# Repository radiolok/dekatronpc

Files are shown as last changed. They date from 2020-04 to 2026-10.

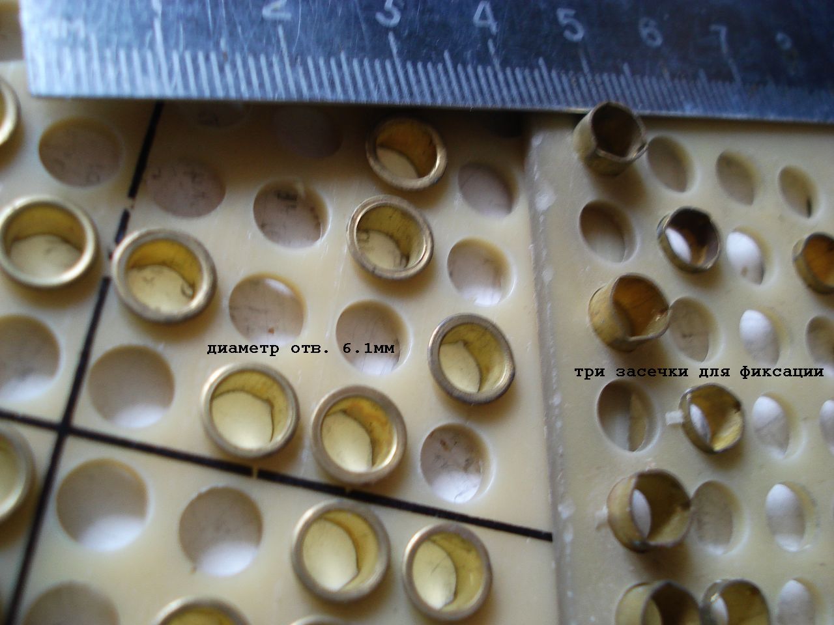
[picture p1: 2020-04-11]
img/magnetic_punch_card/DSC00020.JPG

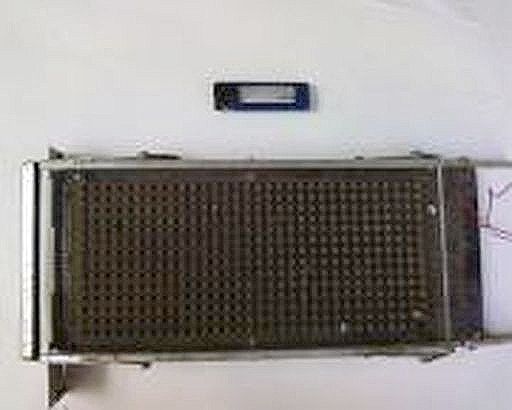
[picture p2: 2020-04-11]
img/magnetic_punch_card/njojryg1g.jpg

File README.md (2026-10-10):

# DekatronPC

Ламповый компьютер на декатронах А110 с системой команд Brainfuck. Счётчики машины — реверсивные декатроны: они умеют ровно то, что нужно Brainfuck, — прибавить и отнять единицу. Логика вокруг них — вакуумные лампы 6Н16Б и 6Ж2Б, без кремниевых полупроводников в вычислительном тракте.

*A vacuum-tube Brainfuck computer built around A110 dekatron counting tubes. RTL in SystemVerilog, an FPGA emulator for blocks not yet built, requirements and microarchitecture docs in Russian.*

Верхний уровень DekatronPC: пульт, терминал, автомат управления, линия выборки с памятью программ, линия данных с памятью данных, реле времени сброса

## Машина

| Параметр | Значение |
|---|---|
| Архитектура | гарвардская: отдельные память программ и память данных |
| Система команд | Brainfuck и отладочный набор, по 16 опкодов, 4 бита на команду |
| Счётчик команд IP | 5 декатронов, 0…99999 |
| Счётчик вложенности Loop | 2 декатрона, 0…99 (в RTL пока 3) |
| Указатель данных AP | 5 декатронов, предел 29999 (99999 — открытый вопрос OPEN-001) |
| Значение ячейки Data | 3 декатрона, 0…255 |
| Всего декатронов | 15 |
| Память программ | 100 000 × 4 бит, верхний банк 99900…99999 — ПЗУ загрузчика |
| Память данных | 30 000 ячеек × 10 бит (BCD: сотни, десятки, единицы) |
| Тактовая частота | 1 МГц (цель; калибровка таймингов декатрона — OPEN-013/014) |
| Логика | ≈ 2600 ламп по синтезу RTL в библиотеку ламповых ячеек, без памяти |

Адреса и данные хранятся в BCD прямо так, как их показывают декатроны: память адресуется тетрадами без перевода в двоичный код. Цикл просматривается самой линией выборки: при `[` с нулевой ячейкой или `]` с ненулевой IP проматывается до парной скобки, счётчик Loop считает вложенность.

Конфигурация счётчиков проверена на наборе из ста реальных программ с GitHub — [Brainfuck-100](https://github.com/radiolok/bfutils/tree/claude_nextGen/programs/bf100) в сабмодуле `bfutils`: в 5 + 2 + 5 + 3 декатрона помещаются 97 программ из 100.

## Система команд

Команда декодируется по паре {режим, опкод}. Неопределённые и зарезервированные опкоды исполняются как NOP.

| Опкод | Отладочный набор (режим 0) | Brainfuck (режим 1) |
|---|---|---|
| 0x0 | NOP | NOP |
| 0x1 | HALT | HALT |
| 0x2 | BELL | `+` INC |
| 0x3 | — (NOP) | `-` DEC |
| 0x4 | EOT — конец загрузки | `>` AINC |
| 0x5 | SOT — начало загрузки | `<` ADEC |
| 0x6 | `{` — пропуск, если AP = 0 | `[` LBEG |
| 0x7 | `}` — повтор, если AP ≠ 0 | `]` LEND |
| 0x8 | CLRL — Loop ← 0 | `.` COUT |
| 0x9 | CLRI — IP ← 0 | `,` CIN |
| 0xA | CLRD — ячейка ← 0 | `[-]` CLRD |
| 0xB | CLRA — AP ← 0 | CLRML — выгрузить и снять MemLock |
| 0xC | HRST — аппаратный сброс | LOAD |
| 0xD | SRST — программный сброс | STORE |
| 0xE | ISA0 — в отладочный набор | ISA0 |
| 0xF | ISA1 — в Brainfuck | ISA1 |

Аппаратный сброс ставит IP = 99900 и запускает загрузчик из ПЗУ; программный — IP = 0. Полная семантика, MemLock и ленивое чтение памяти данных — в [TRS.md](TRS.md), разделы 6–10.

## Документы

| Документ | Что в нём |
|---|---|
| [TRS.md](TRS.md) | требования: архитектура, ISA, память, декатроны, RTL, верификация, стенд, ламповые модули, открытые вопросы, чек-лист и план работ. Каждое требование имеет ID (`REQ-*`, `OPEN-*`) и статус |
| [SCHEMES.md](SCHEMES.md) | структурные схемы ядра в семи листах: декатрон, модуль, счётчик, IpLine, ApLine, MachineCtrl, верхний уровень |
| [doc/dpcrun_golden_model.md](doc/dpcrun_golden_model.md) | C++ golden model: семантика, расхождения RTL и TRS, найденные дефекты |
| [tb/README.md](tb/README.md) | testbench на cocotb и pyuvm |
| [rtl/DekatronPC/Dekatron/DekatronCounter.md](rtl/DekatronPC/Dekatron/DekatronCounter.md) | устройство декатронного счётчика |
| [rtl/DekatronPC/emulator_inspection.md](rtl/DekatronPC/emulator_inspection.md) | разбор слоя эмулятора на ПЛИС |
| [history.md](history.md) | журнал сессий работы над проектом |

## Репозиторий

| Путь | Содержимое |
|---|---|
| `rtl/DekatronPC/` | ядро: `DekatronPC.sv`, `MachineCtrl.sv`, `IpLine.sv`, `ApLine.sv`, `IpMemory.sv`, `RAM.sv`, верх для DE0-Nano `De0Nano.sv` |
| `rtl/DekatronPC/Dekatron/` | декатрон: модель лампы `DekatronTubeV2`, модуль, счётчик, генератор фаз, формирователь импульсов |
| `rtl/parameters.sv` | разрядность счётчиков |
| `rtl/Emulator/` | слой эмулятора на ПЛИС: клавиатура, индикатор МС6205, ИН-12, загрузчик прошивки |
| `rtl/Logic/`, `rtl/Functions/` | примитивы и кодеры |
| `rtl/vtube/` | библиотека ламповых ячеек `vtube_cells.lib` для синтеза |
| `rtl/programs/` | тестовые программы `*.bfk` и загрузчик |
| `rtl/run/` | скрипты моделирования, синтеза и подсчёта ламп |
| `rtl/quartus/` | проект Quartus |
| `tb/` | testbench на cocotb и pyuvm |
| `bfutils/` | сабмодуль [radiolok/bfutils](https://github.com/radiolok/bfutils): компилятор, эмулятор, golden model `dpcrun`, набор Brainfuck-100 |
| `sch/` | схемы KiCad: эмулятор, экспериментальная декатронная ячейка, библиотеки ламп |
| `doc/` | отчёты и справочная литература |
| `img/schemes/` | картинки для SCHEMES.md |
| `web/` | симулятор в браузере: пульт, декатроны, загрузка по SOT/EOT, Brainfuck-100 ([web/README.md](web/README.md)) |
| `tools/schemes/` | генератор SCHEMES.md и картинок схем: `python3 tools/schemes/build.py` |

Блоки `Dekatron.sv`, `DekatronPulseAllow`, `DekatronCarrySignal`, `InsnDecoder`, `BcdToBinEnc` в тракте памяти и папка `rtl/[DEPRECATED]` — старый тракт, подлежит удалению (TRS, раздел 19.4).

## Сборка и проверка

```bash
git clone --recursive https://github.com/radiolok/dekatronpc.git
cd dekatronpc
git submodule update --init       # если клонировали без --recursive

docker build -t dekatron-pc .     # Verilator, Icarus, Yosys, cocotb — то же окружение, что в CI
```

| Задача | Команда |
|---|---|
| один тест на Icarus | `cd tb && make test_compare SIM=icarus` |
| регрессия cocotb | `cd tb && make regression` |
| моделирование RTL | `cd rtl/run && ./run_tests.sh -t` |
| синтез в лампы (Yosys) | `cd rtl/run && ./run_tests.sh -s` |

Полная сборка DekatronPC и эмулятора в Verilator и синтез — тяжёлые задачи; на слабой машине начинайте с одиночных целей на Icarus. CI: `.github/workflows/docker-image.yml`.

## Состояние

- Готово в RTL: модель декатрона, декатронный счётчик с Valid/Ready, линии IpLine и ApLine с ленивым чтением, MachineCtrl, банковая память, синтез в ламповые ячейки.
- Golden model `bfutils/dpcrun` поддерживает полный ISA; пошаговое сравнение с RTL ждёт исправления вывода `.` (OPEN-017).
- Решения, ещё не внесённые в RTL: Loop на 2 декатрона, сброс `lock` в ApLine при смене адреса, вывод через `AP_COUT`.
- Следующие этапы: прогон всех новых блоков в Verilator и Icarus, испытательный стенд, экспериментальная декатронная ячейка и калибровка таймингов, первые ламповые модули.

Полный чек-лист — в TRS.md, разделы 19–22.

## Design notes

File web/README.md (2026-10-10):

# DekatronPC web simulator

A static web page that runs DekatronPC in the browser: 15 dekatrons (IP 5, Loop 2, AP 5, Data 3), the operator panel of `DekatronPC.sv`, program and data memory strips, the Consul printer with keyboard input, the repo test programs and the Brainfuck-100 set.

| File | What it is |
|---|---|
| `index.html` | the page: console, panel, program sheet, printer, RU/EN text |
| `dpc.js` | the machine: JavaScript port of the golden model `bfutils/dpcrun` |
| `build_bf100.py` | copies `rtl/programs/*.bfk` and `bfutils/programs/bf100` (with licenses) to `programs/` and writes `programs/index.json` |
| `test/test_dpc.js` | model tests: trace compare with `dpcrun`, assembler, SOT/EOT load |
| `programs/` | generated, not committed |

## Run locally

```bash
git submodule update --init bfutils
python3 web/build_bf100.py
cd web && python3 -m http.server 8000      # open http://localhost:8000
```

The page fetches `programs/`, so it needs an HTTP server: opening `index.html` as a file shows only the built-in Hello World.

## Deploy

- **GitHub Pages:** `.github/workflows/pages.yml` builds and publishes on every push to `master`, `claude_nextGen` or `web_simulator` that touches `web/`, `bfutils` or `rtl/programs/`, and on manual run. Repository settings: Pages, Source: GitHub Actions; Environments, `github-pages`, Deployment branches: allow the branch you deploy from.
- **Own server:** run `build_bf100.py`, then copy `index.html`, `dpc.js` and `programs/` to any static directory. All paths are relative.

## Tests

```bash
g++ -O2 -DEXEC -o /tmp/dpcrun bfutils/dpcrun/dpcrun.cpp
node web/test/test_dpc.js /tmp/dpcrun     # without the argument the trace compare is skipped
```

CI: `.github/workflows/web.yml`. Design notes and the halt finding: `doc/web_simulator.md`.

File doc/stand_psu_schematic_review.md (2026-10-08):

# Test stand power supply: schematic review

Date: 2026-10-07. Scope: KiCad project `sch/stand/stand.kicad_pro` (was `sch/stand/stand/` at the first review)
(root sheet `stand.kicad_sch` plus three instances of `psu.kicad_sch`:
PSU_200v, PSU_120v, PSU_80v). The side files `stand_v2.kicad_sch` and
`untitled.kicad_sch` are not part of the project hierarchy and were not reviewed.
Requirements: TRS §15 (REQ-STAND-*, REQ-PWR-*, REQ-SAFE-*).

Method: `kicad-cli` 10.0.6 (ERC, netlist export, PDF plot, DRC with schematic
parity), then a manual net-by-net reading of the exported netlist against the
datasheets (TL494, TL431, PC817, LM317, LM337). No simulation was run. The AC
input voltages of the converters are not stated in the schematic, so the
numbers below that depend on them are given as formulas plus an example.

## 1. What the schematic contains

| Block | Parts | Function |
|---|---|---|
| Root, top | J10, D34–D37, C40, U10 LM317, R57/R58/R59, J14 (6.8k pot) | Positive linear rail, about +5.1…+29.8 V |
| Root, bottom | J11, D39–D41/D44, C42, U11 LM337, R62/R60/R61, J15 (6.8k pot) | Negative linear rail, about −5.1…−29.8 V |
| psu.kicad_sch ×3 | Bridge D1–D4 + C1 330 µF/315 V; TL494 push-pull, 2× IRFBE30S, EL33 transformer; bridge HER108 + C14; TL431 + PC817 feedback; Q1 + 1 Ω current limit; 12 V aux via R1, 18 V zener, 7812 | Isolated adjustable HV outputs, nominally 200 / 120 / 80 V |

The ±regulators, protection diodes, ADJ bypass capacitors and their discharge
diodes, bridge orientations and capacitor polarities are all correct (checked
pin by pin, including the LM317 1-ADJ/2-OUT/3-IN and LM337 1-ADJ/2-IN/3-OUT
TO-220 pinouts, TL431LP TO-92 1-REF/2-A/3-K and 2N3904 EBC footprint).

## 2. ERC result

172 violations, of which 163 are only "library not in the current configuration"
(the global symbol and footprint tables are not set up on this machine; not a
design fault). The remaining 9:

- 8 × `power_pin_not_driven` (U10/U11 IN, U3/U4/U7 IN, U1/U4/U7 GND). The rails
  come from rectifiers, not power symbols. Cosmetic: add `PWR_FLAG` symbols.
- 1 × `unconnected_wire_endpoint`: a 3.8 mm stub at (234.95, 81.28)–(234.95, 85.09)
  in `psu.kicad_sch`, next to R9/OC1. The R9→OC1 connection itself is fine;
  delete the stub.

So ERC finds no wiring errors. The real problems are in circuit design and are
listed below.

## 3. Findings, by severity

### Critical: the converter cannot work as drawn

**C1. The voltage loop has the wrong sign (positive feedback).**
The two TL494 error amplifiers are disabled (1IN+/2IN+ at GND, 1IN−/2IN− at
REF), so FB (pin 3) is set only by R13 (4.7k, FB→REF 5 V) and the PC817
transistor (collector OC1.4→FB, emitter OC1.3→GND). In the TL494, higher FB
means a shorter pulse (≈0.5 V gives maximum duty, ≈3.5 V gives zero).
- Output above setpoint → TL431 conducts → LED on → transistor pulls FB low →
  **maximum duty** → output rises further.
- Output below setpoint (including start-up) → TL431 off → LED off → FB pulled up
  to about 5 V → zero duty.

So the loop either does not start, or (with FB partly loaded by the error-amplifier
sink current) starts, then latches at maximum duty with no regulation. The output
then rises to Vbus·Ns/Np_half (≈1.12·Vbus), limited only by the transformer.
Fix: swap the roles: transistor collector to REF (pin 14), emitter to FB,
R13 from FB to GND (the usual TL494 + opto arrangement).

**C2. The current limit is wired for the wrong loop sign, and becomes wrong once
C1 is fixed.** Q1 (base at J2.1, emitter at the return, sensing R24 = 1 Ω)
pulls TL431 REF low on overcurrent. With today's inverted opto this shuts the
converter down, which is the right effect for the wrong reason. After the C1 fix,
pulling REF low turns the LED off, which gives **maximum** duty in overcurrent.
Fix: connect the Q1 collector to the TL431 cathode (U2-K), in parallel with the
TL431, so that overcurrent drives the LED on. Also add a base resistor (≈100–470 Ω).
The trip point is about 0.6–0.7 A, far above REQ-PWR-004's 0.1 A. For a tube
stand, R24 ≈ 6.8 Ω (≈0.1 A) is probably what is wanted. **Question to the owner.**

**C3. The TL431 cathode sees the full output voltage.** The LED and TL431 are fed
straight from +Vout through R9 (18k). The TL431 is rated V_KA ≤ 37 V. When it is
off (start-up, overcurrent, transients) its cathode floats to almost Vout
(80–200 V). When it regulates, V_KA = Vout − V_LED − I_LED·R9. Only about 1 mA
of LED current is needed to pull FB through R13, so V_KA would sit near Vout.
This is an overvoltage on the TL431 in every instance. Fix: supply the LED +
TL431 from a low-voltage rail derived from Vout (for example an
R + 12–15 V zener shunt, or a small transistor follower), with R9 recalculated
for 1–5 mA. The same rail can then power Q1's collector path.

**C4. The 12 V auxiliary supply cannot deliver the gate-drive current.** The TL494
VCC comes from the HV bus through R1, an 18 V zener (D5, DO-35 ≈ 0.5 W) and a
7812. The load on it is dominated by the gate pull-downs R20/R21 = 68 Ω on E1/E2:
when an output is on, (12 − ~1.5) V / 68 Ω ≈ 154 mA. With about 45 % duty per
output, that averages ≈ 140 mA, plus about 10 mA for the TL494: ≈ 150 mA.
R1 then dissipates (Vbus − 18 V) × 0.15 A. At Vbus = 200 V that is about 27 W,
in a DIN0918 (≈2 W) footprint. R1's value is also unspecified (value "R" in all
three instances). As drawn, the rail will collapse, and the MOSFETs will run in
linear mode at low gate voltage. Fix: power the 12 V from a separate
low-voltage winding (the stand already has AC inputs for the ±rails), and raise
the pull-downs to about 1 kΩ with a PNP turn-off transistor (or a diode +
pull-down) per gate, so gate drive costs milliamps, not 150 mA.

**C5. The 4.7 nF snubbers burn tens of watts.** C3/C13 (4.7 nF/630 V) +
R22/R23 (1k, DIN0414 ≈ 1 W) + D7/D6 sit from each drain to GND. In a
centre-tapped push-pull each drain swings 0 → 2·Vbus. A RC/RCD snubber
dissipates about C·V²·f: at Vbus = 200 V, 4.7 nF · (400 V)² · 50 kHz ≈ 38 W
per transistor (bounded a little by R·C = 4.7 µs against a 10 µs half-period).
In addition, the diode is reversed relative to a classic RCD turn-off snubber:
anode is at GND, so it does not speed up charging on turn-off. It does let the
capacitor dump CV² straight into the MOSFET at turn-on, with no resistance.
Fix: a 100–470 pF RC snubber sized against the measured ringing, or an RCD
clamp from drain to +Vbus; in any case, recalculate R power.
Also: the capacitor voltage rating of 630 V is below 2·Vbus + spike as soon
as Vbus > ~280 V.

### Major: values and requirements

**M1. Per-instance values exist only as text notes.** The notes on the PSU sheet
give R7 = 91k / 51k / 24k, R9 = 18k / 11k / 5.6k and transformer turns per
version, but the components carry 91k and 18k in all three instances, and the
BOM/netlist lists them 3×. Use separate sheet files (or KiCad variants) so the
BOM is correct.

**M2. The output range does not reach the nominal voltage in any version.**
Vout = 2.5 V · (1 + R7 / (R8 + R_pot)), with R8 = 1.5k and R_pot = 0…6.8k
(J4 "Voltage", with pins 1–2 joined: a rheostat in the lower leg).

| Version | R7 (note) | R_pot = 0 (max) | R_pot = 6.8k (min) | Needed R8 for nominal |
|---|---|---|---|---|
| 200v | 91k | 154 V | 30 V | ≤ 1.15k |
| 120v | 51k | 87.5 V | 17.9 V | ≤ 1.08k |
| 80v | 24k | 42.5 V | 9.7 V | ≤ 0.78k |

REQ-PWR-004 (50–200 V) is therefore not met. Fix: R8 ≈ 1.0k with a smaller pot,
or move the pot into the upper leg. With a pot in the lower leg, a broken wiper
or unplugged J4 sends REF high: after the C1 fix this shuts the converter down
(safe), but with today's wiring it gives maximum output.

**M3. Linear rail range: a disconnected pot gives the full input voltage.**
On the LM317 (and the LM337 mirror) the pot J14 is in parallel with R58 = 12k.
The range is 1.25·(1 + (R58‖R_pot + 680)/220) ≈ 5.1…29.8 V. If J14 is
disconnected, the setpoint becomes 73 V, so the output goes to Vin − dropout.
If this rail heats tubes (6.3 V), that is an overvoltage on every heater.
Prefer a topology where an open pot gives the minimum voltage. Note also:
LM317/337 are ≤ 1.5 A with 1 A 1N4007 bridges, so neither rail meets
REQ-PWR-001 (6.3 V, ≥ 6 A). The LM337 range (≥ −30 V, 40 V in-out limit) does
not cover REQ-PWR-006 (−20…−70 V). **Question to the owner:** which rails
feed the heaters and the bias, and are REQ-PWR-001/005/006 supposed to be on
another board?

**M4. Bus capacitor rating vs input.** C1/C4/C28 are 330 µF/**315 V**. If the
200v converter is fed from 220–230 V mains directly, the bus is 311–325 V
nominal and about 357 V at +10 % mains, above the rating. The turns notes
(Ns/Np_half ≈ 1.12 for all three versions, Np = 50/30/20) suggest each version
gets a different, lower AC input, but that is not written anywhere.
**Question to the owner:** what AC voltage goes to J1/J3/J7, and is it from an
isolating transformer?

**M5. Shared heatsink.** On the PCB, `radiator1` sits between U10 (LM317, tab =
OUT) and U11 (LM337, tab = IN). On one bare heatsink these tabs short +Vout to
the negative input. REQ-SAFE-005 requires insulated flanges; nothing in the
schematic or PCB records the insulators. Add a note or BOM line (mica/silpad +
bushing) for both, and for the 7812s if they share it.

### Minor

- No fuse, inrush limiter (NTC) or EMI filter on any input. With 330 µF on a
  rectified high-voltage bus, the inrush current is large.
- No HV presence indicator (REQ-SAFE-002), and no explicit bleeder on the
  330 µF bus (REQ-SAFE-004): it only discharges through the R1/zener path. The
  output bleeds through R7 and R9 only.
- Soft-start (C7 1 µF, R10‖R11 ≈ 0.9 kΩ) is ≈ 0.9 ms, short for charging an
  82 µF/200 V output. Consider about 10× more.
- DTC rest level 5·1k/11k = 0.45 V: dead time is fine. Oscillator
  RT = 10k, CT = 1.1 nF: ≈ 100 kHz, 50 kHz per switch, reasonable for EL33.
- No primary-side current sensing: a transformer short or saturation is caught
  only on the secondary (C2), and only after the fix.
- R8/R34/R49 values are written `1.5к` with a Cyrillic "к". BOM tools and
  SPICE will not parse it; use `1.5k`.
- R1/R2/R3 value is `R` (unspecified).
- Symbol `Transformer_SP_1S` is described as 1 secondary, matching the
  netlist. D6/D7 labels overlap the `IRFBE30S` text on the sheet; cosmetic.

## 4. PCB parity (outside the schematic scope, noted for completeness)

DRC with schematic parity (`kicad-cli pcb drc --schematic-parity`, library
warnings ignored): 5 unconnected items, among them the **positive output
rectifier cathodes** D8–D10, D19–D21 and D30–D32 not joined in all three
converters, a Q7 drain track ending at x = −423 mm (off-board), and a D39 pad.
The 4 "extra footprints" and 8 hole-clearance errors are the reference-less
mounting holes. 39 courtyard overlaps; HV creepage was not checked.

## 5. Suggested order of work

1. Decide the input voltages and current limits (M4, C2), and which rails serve
   REQ-PWR-001/005/006 (M3).
2. Rework the feedback: opto polarity (C1), Q1 to the TL431 cathode (C2),
   low-voltage rail for the TL431/LED (C3), R8 and the pot (M2).
3. Rework gate drive and the 12 V auxiliary supply (C4), and the snubbers (C5).
4. Split the PSU sheet per version (M1), fix values (`R`, `1.5к`), add PWR_FLAGs,
   delete the wire stub.
5. Then fix the PCB opens, and check HV creepage and heatsink insulation.

Reproduce: `kicad-cli sch erc --severity-all stand.kicad_sch`,
`kicad-cli sch export netlist stand.kicad_sch`,
`kicad-cli pcb drc --schematic-parity stand.kicad_pcb` in `sch/stand/stand/`.

## 6. Re-check after the owner's fixes (2026-10-07)

The project moved to `sch/stand/` (the `stand/` subfolder is gone). The netlist
was re-exported and diffed against the first review; the changes are present in
all three instances.

| Item | Change in the netlist | Verdict |
|---|---|---|
| C1 | OC1 collector (pin 4) → REF, emitter (pin 3) → FB, R13 4.7k FB → GND | **Fixed.** LED on → FB up → shorter pulse. |
| C2 | Q1 collector → TL431 cathode/LED cathode, base through R51 470 Ω | **Fixed.** Overcurrent now drives the LED on, so duty drops. Trip ≈ 0.6 A kept by owner decision (soft limit). |
| C3 | D38/D47/D48 18 V zener from the R9/LED-anode node to the output return | **Fixed** for the TL431 rating: V_KA ≤ 18 − V_LED ≈ 17 V. Remaining notes below. |
| C4 | none yet | Open; proposal below. |
| C5 | D7/D6 anode at the drain, R22/R23 drain → node, C3/C13 node → +Vbus | **Not fixed**, see below. |

**C3 notes.** (a) R9 now carries the zener current: at 200 V out,
(200 − 18)/18k ≈ 10 mA and 1.8 W in a DIN0516 (≈2 W): use 3 W or 2 × 9.1k.
D38 dissipates about 0.18 W: fine in DO-35. (b) The TL431 needs ≥ 1 mA
cathode current to regulate (datasheet I_min), but the LED needs only a fraction
of that to pull FB up. Add about 1 kΩ across the opto LED so the TL431 always
has its bias. (c) At low setpoints the R9 branch gives little current, for
example (30 − 18)/18k ≈ 0.7 mA at 30 V: then the lowest usable output is about
20–40 V. This is fine for the 200 V version, but check it when R9 is set per version (M1).

**C5 is still a dv/dt snubber, not a clamp.** R22 sits across D7, so the
capacitor charges through D7 on turn-off and discharges through R22 on
turn-on. Referenced to +Vbus, the node still swings from 0 to 2·Vbus each
cycle, so R22 still dissipates about ½·C·(2·Vbus)²·f ≈ ½ · 4.7 nF · (400 V)² ·
50 kHz ≈ 19 W at Vbus = 200 V. Two ways to fix it:
- **RCD clamp:** move R22 so it is across C3 (node → +Vbus) instead of across D7.
  C then charges to about Vbus + overshoot and stays there, so it only absorbs
  the leakage spike. R dissipates about (Vbus + ΔV)²/R, so it has to be large:
  for example 10 nF/630 V, 47–100 kΩ / 2 W. One clamp (C‖R) can serve both
  drains through D6 and D7.
- **Keep the RC/RCD snubber:** but with C ≈ 100–220 pF (≈ 0.4–0.9 W).

### C4 proposal: buffer the TL494 outputs

The 150 mA comes from the 68 Ω static pull-downs, not from the MOSFETs.
IRFBE30 gate charge is about 78 nC, so 78 nC · 50 kHz ≈ 4 mA per transistor
on average. Put an NPN/PNP emitter-follower pair (BC337/BC327 or
2N4401/2N4403) behind each output:

```
            VCC 12 V
               |
               C   NPN
 E1 ──┬─────── B
      |        E ──┬── R18 10 Ω ──┬── G (Q4)
      |        E ──┘              |
      |        B   PNP          10k (G–S)
      |        C                  |
    R20 2.2k   |                 GND
      |       GND
     GND
(the two bases are joined at E1; the two emitters are joined)
```

- Each TL494 output now sources only about 5 mA into R20, against 154 mA before.
- Turn-off goes through the PNP at hFE × 5 mA ≈ 0.5 A peak. This is much
  faster than the 68 Ω pull-down was.
- The 10 kΩ gate–source resistor at each MOSFET keeps it off while VCC is absent.

12 V budget after the change: TL494 ~7 mA, 7812 quiescent ~5 mA, gates ~8 mA,
R20/R21 ~5 mA, REF loads ~1.5 mA, so about 25–30 mA.
Then R1 = (Vbus − 18 V)/30 mA, and P(R1) = (Vbus − 18 V) · 30 mA: for example
6.2 kΩ and 5.5 W at Vbus = 200 V, or 9.7 kΩ and 8.8 W at 310 V. Use a
wirewound part of ≥ 10 W.
D5 then has to absorb the full R1 current whenever the TL494 is not switching:
18 V · 30 mA = 0.54 W, more than a DO-35 can take, so use a 1 W part
(1N4746A, DO-41).
Optional:
- Replace the 18 V zener + 7812 with a single 15 V / 1.3 W zener
  (1N4744A). That saves the 7812's ~5 mA.
- The usual way to remove the R1 heat entirely is a few-turn auxiliary winding
  on T1. R1 then only starts the converter (a few mA), and the winding powers
  VCC once it runs. It stays inside the converter, with no external supply.

### Still open from §3

M1 (per-instance values, R7/R9 are still 91k/18k in all instances),
M2 (R8 1.5k caps the outputs at 154/87/42 V), M3–M5, the minor items, and the
3.8 mm wire stub at (234.95, 81.28) in `psu.kicad_sch`.

## 7. Second re-check (2026-10-07)

Netlist diffed against §6.

**C4: fixed.** Each TL494 output drives a BC337/BC327 pair: the bases are joined
at E1/E2 with R20/R21 = 1k to GND, the NPN collector goes to VCC and the PNP
collector to GND, and the joined emitters drive R18/R19 10 Ω to the gate. The
CBE TO-92 pinout matches the BC337/BC327 parts. Output drive is now
≈ 10 mA per TL494 output instead of 154 mA. One leftover: there is no
gate–source resistor at Q4/Q5 (about 10k), so a gate floats while VCC is absent.

**C5: fixed.** There is now one shared RCD clamp: D6 and D7 run from the drains
to a common node, with C3 10 nF/630 V and R22 47k in parallel from that node to +Vbus.
C13/R23 were removed. R22 dissipates about (Vbus + overshoot)²/47k: about 1.0 W
in the 200v version, which is at the limit of the DIN0414 footprint (≈1 W). Use
2 W there; the 120v and 80v versions are at ≤ 0.45 W.

**M1: accepted by owner.** The three copies are soldered by hand with
per-version values from the sheet notes, so the BOM showing 91k/18k ×3 is known
and acceptable.

**M4: closed.** The inputs are now documented: J10/J11 24 V RMS, and J1 136 / 80 / 56 V RMS for
the 200v / 120v / 80v converters. Peak bus ≈ √2·V − 1.4 V:

| Version | Vbus nominal (+10 %) | Max output ≈ Vbus·Ns/Np − 2.4 V, nominal / −10 % mains | R1 for 30 mA, P(R1) |
|---|---|---|---|
| 200v | 191 V (212 V) | 211 V / 190 V | 5.6k, ≈ 5.2 W |
| 120v | 112 V (124 V) | 124 V / 111 V | 3.0k, ≈ 2.8 W |
| 80v | 78 V (86 V) | 87 V / 78 V | 2.0k, ≈ 1.8 W |

- All bus capacitors (315 V), output capacitors (315 V) and the 630 V clamp
  capacitor have margin. The IRFBE30 drain stays ≤ 2·212 V + spike.
- With no output choke, the output peak-charges, so the maximum is set by the
  turns ratio, not the duty. Each version reaches its nominal voltage with about 5 % headroom
  at nominal mains, but not at −10 % mains or under heavy load.
- R1 can now be sized (the table assumes the 25–30 mA budget from §6). Pick
  about 2× the power rating.
- **D5 (18 V, DO-35 0.5 W) is still too small.** While the converter idles
  (output at setpoint, no load, pulses near zero) the zener takes all of R1's
  current: 18 V · 30 mA ≈ 0.55 W, more at +10 % mains. Use a 1 W zener
  (1N4746A, DO-41).
- ±rails: 24 V RMS gives ≈ 32.5 V DC (36 V at +10 %). This is within LM317/337's
  40 V input–output limit across the whole 5–30 V range. At low output voltages
  the regulator dissipates (32.5 − Vout)·I, for example ≈ 26 W at 6.3 V/1 A, so the
  heatsink must be sized for that.

**M5: closed.** One of the two TO-220s is fully isolated (REQ-SAFE-005). The
heatsink is then at the other part's tab potential (LM317 OUT or LM337 IN,
≤ 36 V), so keep it off the chassis.

**Still open:**
- M2: R8 = 1.5k caps the outputs at 154 / 87 / 42 V. It needs R8 + R_pot,min ≤ 1.15k / 1.08k / 0.78k.
- M3: an open pot drives the LM317/337 rails to full input. Also unanswered: which rails cover REQ-PWR-001/005/006.
- Minor: R1 value still `R`, `1.5к` (Cyrillic), the 3.8 mm wire stub in psu.kicad_sch.
- New, minor: the transformer footprint link `User:EL33` does not
  exist in `User.pretty` (the file is `EL33_1Prx2+1S.kicad_mod`). The PCB still
  holds an embedded copy, but "Update PCB from Schematic" will fail on T1–T3.

## 8. Third re-check (2026-10-07)

Changes: R8 now has per-version values (1.1k / 1.1k / 0.82k), R1 has per-version
values (10k / 4.7k / 3k), and both have sheet notes. Owner information: heater
power goes from the transformer straight to the edge connectors
(REQ-PWR-001), and the 300–500 V dekatron supply is a separate PWM module
mounted on top of this board (REQ-PWR-005; the PCB has mounting holes for it).

**M2.** Range with R_pot = 0…6.8k: Vout = 2.5·(1 + R7/(R8 + R_pot)).

| Version | R7 / R8 | Range | Turns limit (nominal mains) | R8 for nominal |
|---|---|---|---|---|
| 200v | 91k / 1.1k | 31…209 V | 211 V | ≤ 1.15k: OK |
| 120v | 51k / 1.1k | 19…118 V | 124 V | ≤ 1.08k: **1.0k** |
| 80v | 24k / 0.82k | 10…76 V | 87 V | ≤ 0.77k: **0.75k** |

The 120v and 80v versions still stop 2–4 V short of nominal. Before tolerances
(TL431 ±1–2 %, resistors ±1 %) the 200v version sits at 209 V, and the turns ratio
leaves it only about 1 % headroom at nominal mains. So at its top setting it
runs near maximum duty (see the R1 note).

**M3: closed, no defect.** The divider is R57 (220 Ω, OUT–ADJ) over
R58 + R59 in series to GND. The pot (J14 pins 1–2 at ADJ, pin 3 at the
R58/R59 node) is **in parallel with R58**, so
V = 1.25·(1 + (R58‖R_pot + R59)/R57): 5.1 V at R_pot = 0, 29.8 V at 6.8k.
A disconnected pot leaves R58 + R59 = 12.68k, which gives a setpoint of 73 V.
The regulator cannot reach that, so it saturates at its input, ≈ 32.5 V − dropout
≈ 30 V. That is the same as the pot's top end. Heaters are not on these
rails, so this is harmless. The LM317/LM337 rails cover REQ-PWR-007
(+10 V/−20 V), but −30 V is the limit, so they **do not cover the −20…−70 V bias
(REQ-PWR-006)**. Question to the owner: where does the bias come from?

**R1 and the 12 V budget.**

| Version | R1 | I(R1) nominal | P(R1) nominal / +10 % mains | D5 idle, +10 % |
|---|---|---|---|---|
| 200v | 10k | 17 mA | 3.0 W / 3.8 W | 0.35 W |
| 120v | 4.7k | 20 mA | 1.9 W / 2.4 W | 0.41 W |
| 80v | 3k | 20 mA | 1.2 W / 1.5 W | 0.41 W |

- **R1 footprint:** DIN0918 (18 × 9 mm) is a ≈ 2 W body. The 200v R1 (3–3.8 W) and the
  120v R1 (≈ 2.4 W at high mains) are over it: use a 5 W part with its footprint
  (for example a cement/wirewound R_Axial_Power_L25.0mm).
- **D5:** idle dissipation is now ≤ 0.41 W, within the DO-35 0.5 W rating but with
  little margin when hot. A 1 W zener is still advisable, though no longer critical.
- **Budget at full duty is about 30 mA**: TL494 ~6 mA, 7812 quiescent ~5 mA,
  gate charge 2 × 78 nC × 50 kHz ≈ 8 mA, R20/R21 1k ≈ 10 mA, REF loads
  ≈ 1 mA. R1 now supplies only 17–20 mA. At light load this is fine (short
  pulses), but during start-up and near the top setting the 18 V node sags, the 7812
  drops out and gate drive falls below the 10 V the IRFBE30 needs. The 200v
  version near 209 V is the worst case. Cheapest fix: **R20/R21 → 4.7k**.
  Then the PNP still gets ≈ 2 mA of base current (≈ 200 mA turn-off peak),
  and the budget drops to about 22 mA. Optionally replace the 7812 with a 78L12
  (≈ 3 mA quiescent). For the 200v version, also consider R1 ≈ 8.2k / 5 W.

**Still open (minor):** a 10k gate–source resistor at each MOSFET; R22 2 W in the 200v version;
the `User:EL33` footprint link (file is `EL33_1Prx2+1S`); the wire stub
at (234.95, 81.28) in psu.kicad_sch; the REQ-PWR-006 bias source.

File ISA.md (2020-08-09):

# DekatronPC Instruction set

DekatronPC Instruction set if fully compatible with brainfuck programming language, but have some extentions for maintance purposes.

In-memory representation for each instruction is 4-bit width, 
but there are two Instruction Set Registers - ISAR0 and ISAR1, which extend number of instructions from 16 to 64.

## Brainfuck ISA (ISAR1=0, ISAR0=0)

| Symbol | Opcode | Brainfuck | Name | Description |
|---|---|---|-|---|
|  N |  0x0 | |NOP | No instruction, can be used for alignment purposes|
|  H |  0x1 | |HALT | Stop machine execution, Namual resume |
|  + |  0x2 | + |INC  | Increment of Current data cell|
|  - |  0x3 | - |DEC  | Decrement of current data cell|
|  > |  0x4 | > |AINC | Increment of address pointer|
|  < |  0x5 | < |ADEC | Decrement of address pointer|
|  [ |  0x6 | [ |LBEG | If current data cell equal zero, skip the loop|
|  ] |  0x7 | ] |LEND| If current data cell not equal zero, repeat loop iteration|
|  . |  0x8 | . |COUT| Print current symbol to the terminal|
|  , |  0x9 | , |CIN | Read symbol from the terminal (Blocked acces - Program halted while no symbol)|
|  R |  0xA | |RST | Hard reset|
|  0 |  0xB | |CLRD | Write zero to current Data Cell |
|  3 |  0xC | |ISA3| Set ISAR1 = 1 and ISAR0=1 - RESERVED ISA|
|  P |  0xD | |ISA2| Set ISAR1 = 1 and ISAR0=0 - PunchTape ISA|
|  M |  0xE | |ISA1| Set ISAR1 = 0 and ISAR0=1 - Maintaince ISA|
|  B |  0xF | |ISA0| Set ISAR1 = 0 and ISAR0=0 - Brainfuck ISA (Default value)|

## Maintance ISA (ISAR1=0, ISAR0=1)

| Symbol | Opcode | Brainfuck | Name | Description |
|---|---|---|-|---|
| |  0x0 | | | |
| |  0x1 | || |
| |  0x2 | |  ||
| |  0x3 | |  ||
|  > |  0x4 | > | AINC | Increment of address pointer|
|  < |  0x5 | < | ADEC | Decrement of address pointer|
|  { |  0x6 | |LABEG | If current address equal zero, skip the loop|
|  } |  0x7 | |LAEND | If current address is not equal zero, repeat loop iteration  |
|  S |  0x8 | |SETI| Set instruction counter to start point|
|  I |  0x9 | |CLRI |Clear instruction counter|
|  A |  0xA | |CLRA | Clear address counter|
|  0 |  0xB | | CLRD | Clear Data |
|  3 |  0xC | |ISA3| Set ISAR1 = 1 and ISAR0=1 - RESERVED ISA|
|  P |  0xD | |ISA2| Set ISAR1 = 1 and ISAR0=0 - PunchTape ISA|
|  M |  0xE | |ISA1| Set ISAR1 = 0 and ISAR0=1 - Maintaince ISA|
|  B |  0xF | |ISA0| Set ISAR1 = 0 and ISAR0=0 - Brainfuck ISA (Default value)|

# Bootloader

Bootloder is the code, which is performed after reset vector. In placed on the instruction address 0x00000;

## Memory clearance routine

After Reset vector release we have zeroes in any counters, but memory can contain garbage. We need to do cleanup:

  ```
  for (i = 0; i < 30000; ++i)
  {
    Memory[i] = 0;
  }
  ```
  
With Dekatron PC ISA we will get next code:

```
  MA0> //Select maintance ISA, Clear Address counter, Clear data and select next data cell
  {   // While address counter is not zero
    0 >//Cleanup current data cell and go next
  }
  B //Set Default brainfuck ISA
  ```

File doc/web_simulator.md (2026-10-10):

---
title: Web simulator of DekatronPC
date: 2026-10-08
status: report
requirements: REQ-GM-001, REQ-LOAD-001..009, REQ-PANEL-001..006, REQ-BELL-007
---

# Web simulator of DekatronPC

`web/` holds a static page that runs the machine in a browser and shows it the way the console will: dekatrons, lamps, keys and switches, memory strips, the Consul printer. It is published on GitHub Pages by `.github/workflows/pages.yml` and runs from any static server (`web/README.md`).

## 1. Machine model

`web/dpc.js` is a line-by-line port of `bfutils/dpcrun` (`dpcrun.cpp` at bfutils 651cb62). The semantics are the golden model's, including the "RTL:" places of `doc/dpcrun_golden_model.md` §4. Differences are outside the instruction semantics:

| Item | dpcrun | web model | Why |
|---|---|---|---|
| Bootloader ROM | empty unless `-b` | `SIMPLEBOOT` of `bootloader.sv`: NOPs, ISA0 at 99998, SOT at 99999 | owner: no clear-memory routine in the simulator, memory is cleared with memset |
| AP limit | 29999 default, `-a` | 99999 | current RTL (ApLine has no top limit, OPEN-001), as `DekatronPC_tb.cpp` builds dpcrun |
| Panel keys | none | `haltKey()`, `loadingStop()`, `nextIp()`, `prevIp()` | keys of `DekatronPC.sv`; semantics from MachineCtrl/IpLine (S_HALT) |
| Loader | one table | two dialects, see §3 | owner decision |

**Check:** `web/test/test_dpc.js` runs the same programs as `dpcrun -f … -s -a 99999` and compares every trace line (IRET, IP, mnemonic, Loop, AP, Data counter, MemLock, status). All match: helloworld 400 steps, looptest 73, program 5 771, triangle 321 969, pi 221 386, fibonachi 400 000 (endless, cut). Plus assembler tests, a full SOT/EOT load of helloworld through the ROM (prints `Hello World!`) and a CIN test on rot13. 15 checks pass.

## 2. Loading: SOT/EOT only

LOAD AND BOOT clears program and data memory, puts the opcode stream on InsnIn and presses Hard Reset and Run. The ROM runs to SOT, the opcodes are written from address 0, EOT gives Soft Reset (SoftRstOnEOT) and the machine waits for RUN unless RunOnSoftRst is on.

The stream is `ISA1, program, HALT, ISA0, EOT`; HALT/ISA0/EOT are not appended when the program already ends with ISA0, EOT (the repo `.bfk` files end with `HDE`). ISA1 comes first for the same reason as in `DekatronPC_tb.sv`: loading starts in Debug ISA, where `>` (0x4) is EOT.

Data memory is cleared at power-on, on LOAD AND BOOT and by the HARD RST key (owner, 2026-10-08; the MEM CLEAN key was dropped). The HRST instruction does not clear memory.

The same load also works from the panel: with RunOnHardRst on, HARD RST starts the ROM, and when SOT puts the machine in load mode with InsnIn empty, the program reader puts the program from the text window on InsnIn (same stream, memory not cleared). With RunOnHardRst off, HARD RST then RUN does the same.

## 3. Program text: two dialects

- **DekatronPC ISA off (default for pasted text and Brainfuck-100):** only `+ - < > [ ] . ,` are commands, everything else is a comment.
- **DekatronPC ISA on (repo `.bfk` presets):** the full table of `generate_rom.py`/`dpc::assemble()`, with comments `//`, `;`, `#` to the end of the line and `/* … */`. `generate_rom.py` and `dpc::assemble()` don't know these comments yet; the page only strips them before assembling.

## 4. Panel

Keys (rectangles, label above): Hard rst, Soft rst, Halt, Step, Run, Load start, Load stop, Dec, Inc. Dec/Inc change the counter picked by the rotary Counter selector (IP, Loop, AP, Data) while the simulator clock is stopped. The RTL has only keyPrevIp/keyNextIp; the other three are a simulator extension (`Machine.manualStep()`): Loop wraps 0–99 without touching the overflow flag, AP moves like `>`/`<` (a locked Data counter is flushed first, which releases MemLock), Data steps like `+`/`-` (MemLock set). Switches (rotary OFF/ON): EchoMode, RunOnHardRst, RunOnSoftRst, SoftRstOnEOT, BellOnCIN, BellOnHALT, BellOnError. Defaults are the Emulator's hard-wired values (OPEN-011) except BellOnHALT and BellOnError, which are on so a finished program rings. Speed: 1, 4, 16, 64, 256, 1k, 10k instructions/s or MAX. The page counts retired instructions only.

The printer has a column selector (40, 64, 72, 80, 132; default 80): lines longer than the width wrap like on a terminal, tabs stop every 8 columns, and the type is sized so the chosen width fills the paper.

`key_next_app_i` is replaced by the program selector. The bell sound plays on every Bell output and has an On/Off radio.

## 5. Finding: halt step skips a pending loop scan

dpcrun has no Step key. Its `enterHalt()` mirrors IpLine S_IDLE with `halt_rq`: when `ip_counted_q & ~ip_ahead`, IP steps once more without looking at `scan_req`. Brackets are never prefetched (`pf_q <= ~is_bracket & ~is_ip_op`), so `ip_ahead` is 0 after a bracket. If the machine halts right after a taken `]` (data ≠ 0) or `[` (data = 0), the scan is lost and IP lands after the bracket.

In the model, halting after every instruction (what MachineCtrl does in Step mode, `one_step` → S_HALT) turns helloworld into garbage output. Not checked on the RTL in a simulator.

By owner decision (2026-10-08) the page's STEP pauses the simulator clock after one `step()` and does not go through the halt path; HALT does, so the effect is visible there. The fix in IpLine/MachineCtrl (and dpcrun) is left for later.

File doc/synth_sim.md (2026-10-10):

# Netlist (gate-level) simulation of the RTL tests

Date: 2026-10-07. Scope: run the Icarus tests of `rtl/run/run_tests.sh -t`
against the Yosys netlists instead of the RTL. Requirement: REQ-VER-025
(first, zero-delay step). Script: `rtl/run/synth_sim.sh`, CI job `synth_sim`.

## 1. How to run

```
cd rtl/run
./synth_sim.sh                 # all tests: synthesize, then simulate
./synth_sim.sh IpLine ApLine   # chosen tests
./synth_sim.sh -n IpLine       # reuse the netlist, simulate only
./run_tests.sh -g              # the same, from run_tests.sh
```

Tests: `Dekatron` (DekatronModule), `Counter` (DekatronCounter), `IpLine`,
`ApLine`, `MachineCtrl`, `DekatronPC` (helloworld and program.bfk on one
netlist). Output goes to `rtl/run/synth_sim/<test>/` (git-ignored):
`<top>_synth.v`, `synth.log`, `<run>_compile.log`, `<run>_sim.log`, VCD.
The exit code is the number of failed runs, and a summary is printed at the end.
Only yosys, python3 and Icarus are needed. Synthesis takes seconds per
block; the whole suite takes about 2.5 min, most of it the two
DekatronPC runs, which hit the testbench timeout.

## 2. Flow

1. **Synthesis**: `synt_dpc.tcl`, the same flow as `run_tests.sh -s` (area
   ABC script, `equiv_opt`, `qn_absorb.py`). Two new options, both off by
   default, so the tube-count flow is unchanged (IpLine rerun: 657.5 tubes,
   415 cells, same as before):
   - `-p NAME VALUE`: `chparam` on the top. Each DUT is synthesized with the
     parameters its testbench uses (e.g. IpLine `LOOP_READ=1`, MachineCtrl
     `EN_EMULATOR=1`, Counter `TOP_VALUE=12'h255`).
   - `-bb MODULE`: the module stays a black box, so its instances stay in the
     netlist **with their parameters** (`DekatronTubeV2 #(...) dekatron`).
   The file list is now read relative to the list file itself, not the
   working directory (same files as before from `rtl/run`).
2. **Prep**: `synth_sim_prep.py` checks that every liberty cell has a model
   in `rtl/vtube/vtube_cells.v`. A synthesized top has no parameters, but the
   testbench passes them, so the script declares them again in the top with the
   synthesized values. An `initial` block calls `$fatal` if the testbench passes
   a different value than the netlist was built for. This guard caught a
   real mistake while setting up: DekatronPC_tb uses `EN_EMULATOR=0`.
3. **Simulation**: Icarus, `-g2012`, the testbench files unchanged:
   testbench + netlist + `vtube_cells.v` + RTL of the black boxes +
   `parameters.sv` + `ClockDivider` (testbench clocks). Run in
   `synth_sim/<test>/`; `../firmware.hex` resolves to `synth_sim/firmware.hex`.

### Black boxes

These are behavioural models of parts that are not tube logic. Under `SYNTH`
they are empty or stubbed, so they add nothing to the tube count, and the
simulation puts their RTL back:

| Module | What it models | Under SYNTH |
|---|---|---|
| `DekatronTubeV2` | the tube | empty body |
| `OneShot`, `Impulse` | hs_clk pulse timing: phase generator, `writeTimer` window; special tube circuits (owner) | empty body |
| `RstTimeRelay` | time relay in the reset lines | empty body; RTL is extracted from `DekatronPC.sv` with awk |
| `Ram`, `IpMemory` | memory (ferrite) | stub |

Without `OneShot`/`Impulse` the netlist has undriven pulse lines
(yosys: `Wire Impulse.\Impulse is used but has no driver`), the tube never
steps and every test fails. **Owner decision (2026-10-07):** `OneShot` and
`Impulse` are special tube circuits, not standard-cell logic, so they stay black
boxes here. Like the dekatron, they are outside the ABC tube count
(`run_tests.sh -s`) and must be added to the machine's budget separately.

### Cell models

`rtl/vtube/vtube_cells.v` had drifted from `vtube_cells.lib`: old names
(`BUF_6N16B`, `NOT_6N16B`, `A1OOI_N16X7`, `A2OOI_N16X7`), no `NOR10_N16X7`,
and triggers without `QN` (which `qn_absorb.py` uses). It is rewritten one to
one with the liberty file. The models have zero delay, and flops without reset
start at X.

## 3. Results (local, Icarus 13-devel, yosys 0.51)

| Run | Result |
|---|---|
| Dekatron | PASS |
| Counter | PASS |
| IpLine | PASS |
| ApLine | PASS |
| MachineCtrl | PASS |
| DekatronPC_hello | PASS ("Hello World!\n", 14332 us; RTL 14330 us) |
| DekatronPC_program | PASS ("Hello from program.bfk!", 179736 us; RTL 179734 us) |

Sanity check: one `NAND2_J2` in the IpLine netlist swapped for `NOR2_N16`
makes IpLine fail, so the netlist really is the DUT.

The netlist runs finish 2 clocks after RTL. TX and every check match; the
offset is not investigated yet.

## 4. DekatronPC failure: analysis and fix (2026-10-07)

Before the fix both DekatronPC runs timed out: after the bootloader the
testbench saw `halted` at `IP=00000 Insn=f`, and TX gave `(0)` every 11
clocks. Method: a probe module printing MachineCtrl/IpLine/ApLine handshakes
every clock after loading, run on RTL and on the netlist and diffed, then
a VCD of `ipLine` around the divergence and a backward walk from the first
X net through the netlist drivers. There were two independent causes. Neither
is a tube-logic bug: the netlist computes the same function as the RTL.

### 4.1 X from the memory read path (simulation model)

Traces match through loading, EOT and the soft reset. At the first IP step
in BF mode (`ISA1` at IP 0) the netlist IP stays at 0, and two clocks later
`ip_ready`, MachineCtrl's state and everything after it are X. Back-trace
from the first X net in `ipLine`:

```
_083_ <- OR2  _026_ <- NOR2(_023_, _025_)
  _023_ <- OR2(_022_, insn_loading=0)  _022_ <- NOR2(loop_val_zero=x, insn_loop_close=0)
  _025_ <- NOR2(_024_, insn_loop_open=0) _024_ <- NOT(loop_val_zero=x)
```

`loop_val_zero = insn_mode ? data_zero : ap_zero`, and in BF mode
`data_zero = lock_q ? data_ctr_zero : ~|mem_rd_data` (ApLine). Right after a
reset no cell has been read (`data_zero_valid = 0`), so `data_zero` follows
the memory output register, which was X: `RamBank.rd_q` is set to 0 at
power-up under `INIT_ZERO`, but `RamGroup.digit_q` (which child drives
`rd_data`, one clock behind) had no such initial value, so
`rd_data = child_rd[digit_q]` was X until the first access.

In RTL IpLine uses the signal only as `insn_loop_open & loop_val_zero`, so
`0 & X = 0`. ABC built the same function from `loop_val_zero` and
`~loop_val_zero` on reconvergent paths, which a 4-state simulator cannot
resolve (X pessimism). The X reached IpLine's state flops and the machine
was lost. With any 0/1 value on the memory output the netlist behaves like
RTL, so real hardware is not affected.

Fix: `rtl/DekatronPC/RAM.sv`, `RamGroup` sets `digit_q`/`dbg_digit_q` to 0
under `INIT_ZERO`, in the same way as `RamBank.rd_q`. This is part of the
behavioural memory model only (`RamGroup` is outside `SYNTH` and a black box
here), so tube count and synthesis are unchanged.

### 4.2 Zero-width IsHalted pulse (testbench)

With 4.1 fixed the netlist matches the RTL trace clock for clock, but the
testbench still printed `halted` on the first instruction. An event probe
shows `IsHalted` going 0 -> 1 -> 0 in one time step on every entry into
state 4: `is_halted = (state == S_HALT)` is a decoder of the state register,
and in the netlist the state bits update in different delta cycles, so the
decoder passes through `S_HALT` for zero time (a decode hazard; a real one
too, but harmless, since every consumer samples it on a clock edge).
`@(posedge IsHalted)` and `wait (IsHalted)` in `DekatronPC_tb.sv` catch the
pulse. A VCD does not show it, because it keeps only the settled value per
time step.

Fix: `DekatronPC_tb.sv` task `wait_halted()` samples `IsHalted` on the
falling edge of `Clk` (as `read_tx` already does for `tx_vld`) and replaces
all four asynchronous waits. The other async waits look at a flop output
(`InsnInLoading`) or at the RTL time relay (`rst_busy`), which do not glitch.
The RTL runs still pass (helloworld 14330 us, program.bfk 179734 us).

## 5. CI

Job `synth_sim` in `.github/workflows/docker-image.yml`: runs
`./synth_sim.sh` in the Docker image (Icarus 12) and uploads `synth_sim/**/*.log` and the netlists as the
`synth-sim-logs` artifact. All runs passed in CI on Icarus 12, so
`continue-on-error` was removed (2026-10-07): a failing netlist run now fails
the pipeline.

## 6. Next

- REQ-VER-025 asks for liberty delays. The flow is zero-delay, so it needs
  `specify` blocks or SDF from the liberty file.
- Look into the 2-clock offset between netlist and RTL run times.
- The netlist's reconvergent X handling will hit any signal read while
  invalid. A gate-level run with random 0/1 initial values for flops without
  reset (instead of X) would find such spots without masking real ones.

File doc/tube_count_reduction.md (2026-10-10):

# Tube count: analysis of the synthesis report and how to reach the budget (now ≤ 1200)

Date: 2026-10-06. Covers the Yosys netlists of `IpLine`, `ApLine` and `MachineCtrl`
(`rtl/run/run_tests.sh -s`, `rtl/run/synt_dpc.tcl`, `rtl/vtube/vtube_cells.lib`
with the uncommitted renames `NOT_N16`, `A1OOI_N16J2`, `A2OOI_J2`).
§1–§7 are the original analysis (no RTL or flow file was changed then; all experiments
ran on scratch copies). §8–§14 record what was implemented afterwards.

## Status (updated 2026-10-07)

Library with 7-tube triggers, `synt_dpc.tcl` with the area ABC script (`-J 50`),
`equiv_opt` and `qn_absorb.py`; `run_tests.sh -s` set (IpLine + ApLine + MachineCtrl,
counters included, memory/reset relay/panel excluded):

| Step | Section | IpLine | ApLine | MachineCtrl | Total | Δ |
|---|---|---|---|---|---|---|
| Old flow, new library (baseline) | §8 | 998.5 | 1065.5 | 572 | 2636 | – |
| Area ABC script + `QN` pins (R6) | §8 | 876 | 989 | 471.5 | 2336.5 | −299.5 |
| RX handshake, `rx_q` removed | §9 | 874.5 | 874 | 493.5 | 2242 | −94.5 |
| ApLine FSM rewrite | §10 | 874.5 | 719 | 493.5 | 2087 | −155 |
| IpLine FSM rewrite (R1) | §11 | 722 | 714 | 512 | 1948 | −139 * |
| MachineCtrl FSM rewrite (R2) | §12 | 722 | 714 | 284.5 | 1720.5 | −227.5 |
| COUT from the Data counter (R7) | §13 | 711 | 679.5 | 282 | 1672.5 | −48 * |
| Decode once (R3), no `insn_q` (R4) | §14 | 652 | 676 | 250 | 1578 | −94.5 * |
| Relays for panel switches, + 5 relays (REQ-MOD-011) | §15 | 661.5 | 684 | 250 | 1595.5 | +17.5 † |
| Prefetch P3, opcode latch back in MachineCtrl (REQ-PERF-003) | §16 | **663.8** | **684** ‡ | **318.7** | **≈ 1666.5** | +71 |
| Binary FSM encoding in DekatronCounter, IpLine, ApLine (T1) | §17.6 | **517.5** | **599** | **334** | **1450.5** (mean of 3 seeds ≈ 1437) | −219 § |
| One pulse sender per counter + J2 guide gates (T5), busy flag in Loop/AP (T4), MachineCtrl state codes (T6) | §17.7 | **489.5** | **568.5** | **319.5** | **1377.5** (mean of 3 seeds 1377) | −60 § |

Δ is the change of the total. Each step re-ran ABC, which moves a block whose RTL
didn't change by up to ±30 tubes, so the RTL effect alone (old and new RTL synthesized
in the same run) differs for the rows marked \*: IpLine rewrite −180, R7 −37, R3+R4 −97.
† IpLine and ApLine didn't change in §15; today's run of the same RTL gives 661.5–662.5 /
681.5–684, with or without the relay cell in the library, so +17.5 is ABC drift, not the
relays. The relays' own effect on MachineCtrl is about −4.5 tubes on average over 7 ABC
seeds (§15); the default seed happens to give 250 both ways. Relays are counted separately
and are not tubes: the three blocks are now **1595.5 tubes + 5 relays (2CO)**.
‡ ApLine wasn't resynthesized for §16 (its RTL didn't change). IpLine and MachineCtrl are
means over 3 `&deepsyn` seeds (§16). After P3 the three blocks are about **1666.5 tubes +
5 relays**.
§ T1 row: default seed; Δ is the mean over 3 seeds against HEAD before T1 (≈ 1656 → ≈ 1437, §17.2).
After T1 the three blocks are **1450.5 tubes + 5 relays** (default seed), 64 triggers. After T4–T6:
**1377.5 tubes + 5 relays** (default seed; 3 seeds 1377.5 / 1376 / 1377.5), 62 triggers, 30 `GUIDE_EN_J2`.

Overall: **2636 → 1578 (−1058, −40 %)** for the three blocks. Of the §5 ideas, R1, R2,
R3, R4, R6 and R7 are done, R8 and R9 were rejected by the owner, R5 and R11 are open,
R10 is not recommended. The open items are worth about 10–30 tubes.

**New goal (2026-10-07, owner):** the whole machine must fit in **1200 tubes**
(REQ-MOD-009, was 1500). The three blocks alone are 1578, 378 (24 %) over that,
before memory support, the reset relay and the panel are counted. FSM cleanup is
used up; see §6 for what's next.

**Second attempt (2026-10-08, §17):** binary state encoding (measured −219, **done**, §17.6), diode codecs under REQ-AUTH-002 (≈ −150…−170) and latches for the counter
carry flags (≈ −70…−84) would take the three blocks from ≈ 1656 to ≈ 1170–1200.
T1 and T4–T6 are in the RTL (three blocks ≈ 1377). Owner (2026-10-08): T2 rejected (diodes
only in rectifiers and ferrite memory, REQ-AUTH-002), T3 and T8 postponed, T7 and T9 rejected (§17.5).

## 1. Baseline

`python3 dpc_stat.py -j IpLine.json,ApLine.json,MachineCtrl.json` on the netlists
from 2026-10-06 22:38, after commit fb4fff7:

| Block | Tubes | of which counters | glue (FSM + muxes) |
|---|---|---|---|
| IpLine | 784.5 | IP 188, Loop 77, InsnLoopDetector 5.5 | **514** |
| ApLine | 871.5 | Data 213, AP 185 | **473.5** |
| MachineCtrl | 482.5 | – | **482.5** |
| **Total** | **2138.5** | 668.5 | **1470** |

The glue between the dekatrons takes 69 % of all tubes, while the four counters
take 31 % (their codecs: BinToBcd 13 × 9, BcdToBinEn 3 × 23, PulseSender 15 × 6).

By cell type, flops are the largest single item: 106 `DFFSR_n` + 24 `DFF` =
130 triggers × 3.5 = **455 tubes (21 %)**. The IpLine and ApLine flop counts
(33 and 31) include one-hot state registers (12 and 9 bits): Yosys `synth` extracts
those FSMs and recodes them to one-hot. MachineCtrl's `state` is an output port,
so its FSM is not extracted.

What the count does **not** include: `Ram`/`IpMemory` (stubbed under `SYNTH`),
`RstTimeRelay`, the panel and the dekatrons themselves. The 1500 target needs a
scope (see §7, Q1; answered in §8: the whole machine).

## 2. Findings in the flow and the library

All four are resolved (§8).

1. **Fixed (§8).** **`fsm -encoding onehot` in `synt_dpc.tcl` is a no-op.** It runs after `synth`,
   which has already done FSM extraction. Measured: an explicit binary pass gives the
   same 2138.5, and `synth -nofsm` gives 2165 (+27). FSM encoding is not a lever.
   The pass was removed.
   **Correction (2026-10-08, §17):** the binary pass also ran after `synth`, so it was a
   no-op too and the encoding was never measured. Set through the `fsm_encoding`
   attribute *before* `synth`, binary encoding saves about 219 tubes (§17.2).
2. **Fixed (§8).** **ABC maps for delay, not area.** `abc -liberty` with the default script is
   delay-oriented. In tubes only area matters (1 MHz is slow for a gate).
   `rtl/run/abc_area.abc` is now used.
3. **Fixed by the owner (§8).** **`DFF` has `heat_current: 8500`**, ten times `DFFSR`/`DFFSR_n` (850). This
   looks like a typo. It adds 204 A of the 813 A in the heat-current total (about
   1.3 kW of the 5.1 kW estimate). It does not affect the tube count.
   All three trigger cells now have area 7 and `heat_current: 2000`.
4. **Fixed (§8, R6).** 51 of the 161 inverters (25 tubes) only invert a flop output. A tube trigger
   (Eccles–Jordan) has both anodes, so Q̄ is free physically. The library DFF cells
   expose only `Q`. The cells now have `QN`, and `qn_absorb.py` moves the inverters to it.

## 3. Measured: synthesis-only changes (no RTL change)

**Adopted in §8** as `rtl/run/abc_area.abc`: script G with `&deepsyn -J 50 -T 30`, which
runs in seconds instead of minutes, plus the `equiv_opt` check asked for below.

Only the `abc` line in `synt_dpc.tcl` was changed to `abc -liberty $cell_lib -script <file>`:

| Variant | ABC script | Total | Δ | Time for 3 modules |
|---|---|---|---|---|
| baseline | default (delay) | 2138.5 | – | ~3 s |
| A | `strash; dch; map -a; topo` | 2059 | −79.5 | ~2 s |
| B | `strash; ifraig; scorr; dc2; strash; dch -f; map -a; topo` | 2023 | −115.5 | ~2 s |
| E | B + 2× resyn2 + a second `dch -f; map -a` pass | 1992 | −146.5 | ~3 s |
| **G** | `strash; &get -n; &deepsyn -T 10; &put; dch -f; map -a; topo` | **1817.5** | **−321** | ~2.5 min |

G by block: IpLine 665, ApLine 781.5, MachineCtrl 371. `&deepsyn` is SAT-based
exact resynthesis, so its gain grows with `-T`, but so does runtime (this is the
heavy part on a small node).

Things that do not work: `mfs2` turns the result into `$lut` cells (no library
mapping), and `resyn2`/`amap` are either missing aliases in Yosys' ABC or worse
(`amap`: 2072).

**Required before adopting G:** an equivalence check of the mapped netlist
against RTL (`equiv_make`/`equiv_induct` in Yosys, or the cocotb tests on the
`*_synth.v` gate netlist). ABC is trusted, but this flow then feeds the tube
build, so it must be checked.

## 4. Measured: RTL prototype of ApLine

**Implemented in §9 (`rx_q`) and §10 (FSM, Moore strobes).** The held-level `mem_valid`
question below is answered in §10.

A scratch rewrite of ApLine for area estimation only. It passes Verilator lint but
has **not** been simulated. Changes:

- `rx_q` (12 flops plus their enable muxes) removed: `data_in` takes `rx_data_bcd`
  directly. This needs the terminal side to hold RX data stable until CIN is done.
- OP/WAIT state pairs merged: 9 states → 6 (`IDLE, FLUSH, READ, AP, DSET, DOP`). The
  WAIT states are redundant because `ready` in IDLE already ANDs `ap_ready & data_ready & mem_ready`.
- The 7 registered strobes (`ap_valid`, `ap_set_zero`, `data_valid`, `data_set`,
  `data_set_zero`, `mem_valid`, `mem_wr`) are decoded from `state` (Moore outputs).
  This is allowed by the handshake rule: `valid` may depend on state, and only
  `ready` must not depend on `valid`.

| | Script B | Script G |
|---|---|---|
| ApLine now | 835.5 | 781.5 |
| `rx_q` removed only | 769.5 (−66) | – |
| Prototype (all three) | 640.5 (−195) | **607.5 (−174)** |
| Flops in ApLine glue | 31 → 18 | 31 → 18 |

The ApLine glue goes from 406.5 to 232.5 tubes (−43 %). Before this can be used,
check that a held-level `mem_valid` matches the RAM handshake (now it is a pulse
re-raised while `mem_ready & ~mem_rd_valid`).

Negative result: making MachineCtrl's `state` internal (so Yosys extracts and
one-hot encodes it) gives 444 → 482.5 under B, which is worse.

## 5. Estimated: further RTL ideas

The estimates come from the ApLine result and from cell costs (flop with enable ≈ 5
tubes, 2:1 mux bit ≈ 1.5–2, NOT 0.5).

| # | Idea | Est. Δ | Changes a rule or requirement? | Status, measured Δ |
|---|---|---|---|---|
| R1 | Same FSM cleanup in **IpLine**: merge `IP_OP/IP_WAIT`, `LOOP_OP/LOOP_WAIT`, `CLR_OP/CLR_WAIT`; decode `ip_valid`, `loop_valid`, `ip_set_zero`, `loop_set_zero`, `mem_valid`, `mem_wr` from state; `clr_is_loop_q` becomes two states | −100 … −130 | no | **Done, §11** (REQ-IPV2-007). IpLine 902 → 722, **−180**; triggers 51 → 40 |
| R2 | Same in **MachineCtrl**: merge `FETCH/FETCH_W`, `IP_OP/IP_OP_W`, `AP_OP/AP_OP_W`, `COUT`/`ECHO`; decode `ip_valid`, `ap_valid`, `tx_vld`, `*_rst_req` from state; remove the unreachable `S_BELL` (nothing enters it) | −80 … −110 | no | **Done, §12** (REQ-CTLV2-010). MachineCtrl 512 → 284.5, **−227.5**; triggers 25 → 9. Includes the register-free op decode (first half of R3) and the bell/echo/reset-type cleanup |
| R3 | **Decode once.** Pass `{insn_mode, insn}` to ApLine and IpLine as the op, instead of re-encoding it to `ap_op[3:0]`/`ap_dec`/`ip_op[1:0]`. This drops 7 registers and the encoder in MachineCtrl. CIN/TEST become ApLine's own sub-ops | −30 … −50 | internal interface only (ApLine/IpLine op codes) | **Done, §12 + §14** (REQ-APV2-008). The 7 registers went in §12; the encoder and op ports in §14: MachineCtrl 282 → 250 (−32), ApLine +0.5 |
| R4 | Drop `insn_q` in IpLine: the program memory's output register already holds the last opcode (same as the data memory's write-through register). Loading mode can take `insn_in` straight away | −15 … −20 | check IpMemory rd_data hold semantics | **Done, §14** (REQ-IPV2-008). `Ram` hold semantics checked; EOT reported by a 1-bit `insn_eot` (owner). IpLine 717.5 → 652, **−65.5** (two states removed as well) |
| R5 | Panel edge detection (`key_moved_q`, the `one_step` release logic) done once, in the panel or MachineCtrl, not duplicated in IpLine | −10 … −20 | no | **Open.** After R1/R2 there is one flop on each side: `key_moved_q` (±IP keys) in IpLine and `one_step` (Step key) in MachineCtrl. They watch different keys, so merging them saves at most one trigger plus its logic (≈ −10) |
| R6 | `QN` pin on `DFF`/`DFFSR_n` in the liberty, plus a post-map pass that replaces `NOT(Q)` with `QN` | −20 … −25 | library only; confirm the tube trigger really gives Q̄ for free | **Done, §8** (REQ-MOD-010). The owner confirmed `QN` is free. `qn_absorb.py` replaced 19 inverters in IpLine and 8 in ApLine (2026-10-06 logs, counters included), ≈ −13.5 tubes at 0.5 per `NOT_N16`. Not measured on its own: §8 reports it together with the ABC script |
| R7 | COUT always from the Data counter: if the cell isn't locked, LOAD it first. That removes the 10-bit `tx_data_bcd` mux. It costs one write window per `.`, which is negligible at 110 baud | −20 … −30 | changes the ApLine COUT path (lazy read stays for TEST) | **Done, §13** (OPEN-017 closed). ApLine −34.5, MachineCtrl −2.5, **−37**. Also fixed `Hello WWrld!!` |
| R8 | Shared counter control: only one counter steps at a time (asserted in IpLine and MachineCtrl), so the four `writeTimer`/`Impulse`/`DekatronPhaseGen`/3-bit FSM sets can become one or two | −40 … −80 | yes: §5 "one phase generator per counter", counter as a self-contained Valid/Ready unit | **Rejected** by the owner (§8, decision 4) |
| R9 | Address memories with dekatron cathodes one-hot (10 lines per decade) instead of BCD: drops BinToBcd on IP and AP (exactly −90) **and** the BCD→1-of-10 decoders on the memory side, which aren't counted today | −90 (+ memory) | yes: §3 "addresses are raw BCD tetrads"; 50 address wires instead of 20 | **Rejected** by the owner (§8, decision 4) |
| R10 | Use the Data counter as the nesting counter during a scan (flush first): removes the Loop counter (74.5 tubes + 2 dekatrons) | −75 | yes: REQ-CNT-002/007 overflow semantics, IpLine/ApLine coupling | **Not recommended**, not pursued |
| R11 | Flatten MachineCtrl+IpLine+ApLine for synthesis (keep counters and DekatronModule as instances) so constant ops propagate across the boundary | unknown | no | **Open.** The first attempt failed to set up: SYNTH stubs of RstTimeRelay/memories fold the netlist to constants. After R3 the ops cross the boundary as raw `{insn_mode, insn}`, so little is left to propagate |

Also done, outside this list: the area ABC script with `equiv_opt` (§8), `rx_q` removed
with the RX handshake (§9, REQ-UART-008) and the ApLine FSM rewrite (§10, REQ-APV2-007).

## 6. Path to ≤ 1500

### Original plan (2026-10-06, old library with 3.5-tube triggers)

| Step | Total |
|---|---|
| Baseline | 2138.5 |
| §3 ABC script G (measured) | 1817.5 |
| §4 ApLine cleanup + no `rx_q` (measured, G) | 1643.5 |
| R1 IpLine cleanup (≈ −115) | ≈ 1530 |
| R2 MachineCtrl cleanup (≈ −95) | ≈ 1435 |
| R3 decode once (≈ −40) | ≈ 1395 |
| R6 QN pins (≈ −22) | ≈ 1375 |
| optional R7/R8/R9 | ≈ 1170 … 1290 |

That plan assumed the 1500 budget covered only these three blocks, and 3.5-tube
triggers. Both assumptions changed in §8: the budget is for the whole machine
(REQ-MOD-009) and a trigger costs 7 tubes.

Order of work as planned, all done:
1. ~~ABC script G in `synt_dpc.tcl` + an equivalence check step.~~ §8.
2. ~~ApLine rewrite, new ApLine test.~~ §9, §10 (Icarus `ApLine_tb`; there is still no
   cocotb ApLine target).
3. ~~IpLine, then MachineCtrl, each with its own test first.~~ §11, §12.
4. ~~R3, then R6.~~ R6 in §8, R3 in §12/§14, plus R4 (§14) and R7 (§13).

### Where it stands (2026-10-07, 7-tube triggers)

| | Planned (old library) | Done (new library) |
|---|---|---|
| Start | 2138.5 | 2636 |
| After R1–R3, R6 (+ R4, R7 done) | ≈ 1375 | **1578** |
| Reduction | ≈ −36 % | **−40 %** |

The relative reduction beat the plan, but the three blocks alone are still 78 over a
budget that must also cover memory support, `RstTimeRelay` and the panel (and possibly
the dekatrons, still to be clarified in REQ-MOD-009). The ideas left in §5 (R5, R11)
are worth about 10–30 tubes.

What remains in the three blocks: 35 glue triggers (IpLine 17, ApLine 9, MachineCtrl 9,
§14), about 245 tubes, plus the four counters with their codecs and phase generators.
Further reduction therefore needs a new direction, not more FSM hygiene. §8 named one:
move state and flags into dekatron-driven sequencing. R8/R9 would have touched the
counters, but the owner rejected them.

### Next goal: 1200 for the whole machine (owner, 2026-10-07)

REQ-MOD-009 is lowered from 1500 to 1200. Against that target:
- the three blocks must lose at least 378 tubes even if nothing else counted;
- memory support, `RstTimeRelay` and the panel aren't in the synthesis count yet, so
  the real gap is larger. Counting them is the first step (TRS §22 item 10);
- whether the dekatrons count toward the budget is still open (REQ-MOD-009).

## 7. Questions for the owner

All six were answered on 2026-10-06; the decisions are in §8.

1. What does the 1500 budget cover: only the logic counted today (IpLine/ApLine/
   MachineCtrl incl. counter glue), or also memory support, reset relay and panel?
   Should it become a REQ in the TRS?
   → **The whole machine**, REQ-MOD-009. Whether the dekatrons count is still open (TRS).
2. OK to switch `synt_dpc.tcl` to the deepsyn ABC script (2.5 min instead of 3 s)
   and add an equivalence check?
   → Yes. Done in §8 with `-J 50` (about 25 s for the three blocks) and `equiv_opt`.
3. Can the terminal side hold `rx_data_bcd` until CIN completes, so ApLine drops
   `rx_q`? The signal stays, but its timing contract (TRS Appendix B) changes.
   → Yes, through a Valid/Ready handshake with a new `rx_rdy` port. Done in §9 (REQ-UART-008).
4. R8 (shared counter control) and R9 (one-hot memory address): worth pursuing, or
   do the §3/§5 rules stand?
   → Not applicable; the rules stand.
5. Does the tube trigger really give Q̄ without extra tubes (R6)?
   → Yes (REQ-MOD-010). Done in §8.
6. Is `DFF heat_current: 8500` a typo for 850?
   → The owner revised all trigger cells: area 7, `heat_current: 2000`.

## 8. Owner's decisions and what was done (2026-10-06, later the same day)

Decisions:
1. The budget is **1500 tubes for the whole machine** (REQ-MOD-009). No further
   investigation in this step.
2. Fix `synt_dpc.tcl` (done, see below).
3. RX uses a Valid/Ready handshake. The sending side holds `rx_data_bcd` until the
   handshake, so ApLine needs no input register (REQ-UART-008). Today `DekatronPC`
   has only `rx_vld`; an `rx_rdy` port is needed, which is a change to TRS Appendix B.
4. R8/R9 (shared counter control, one-hot memory address) are not applicable.
5. The tube trigger has `QN` for free (REQ-MOD-010).
6. The owner updated the library: a trigger (`DFF`, `DFFSR`, `DFFSR_n`) costs
   **7 tubes** (3 × N16B + 4 × J2B) with 2 A of heater current at 6.3 V.

With 7-tube triggers, the 130 triggers cost 910 tubes, **39 %** of the three
blocks. Every flop removed now saves about 7–9 tubes (with its enable mux), so
§4/§5 (Moore strobes, merged states, no `rx_q`, decode once) matter even more.

### Flow changes

- `rtl/vtube/vtube_cells.lib`: `QN` pin (`function: "IQN"`) on `LATCH`, `DFF`,
  `DFFSR`, `DFFSR_n`.
- `rtl/run/abc_area.abc`: `strash; &get -n; &deepsyn -J 50 -T 30; &put; dch -f; map -a; topo`.
  `-J` (stop after 50 steps without improvement) keeps the result reproducible.
  `-T 30` only caps the runtime.
- `rtl/run/synt_dpc.tcl`:
  - The no-op `fsm -encoding onehot` is removed.
  - The library path is resolved from the script's directory.
  - `equiv_opt -assert -async2sync -map <cell models>` proves the ABC mapping before
    it runs for real. `equiv_opt` restores the pre-ABC design, so `abc` runs a second
    time. The proof covers the **top module only** (the glue), not the counter
    submodules.
  - The mapped netlist is passed through `rtl/run/qn_absorb.py` (via JSON), which
    moves every inverter on a trigger's `Q` to its `QN`.

### Results (new library, `run_tests.sh -s` set: IpLine, ApLine, MachineCtrl)

| Flow | IpLine | ApLine | MachineCtrl | Total |
|---|---|---|---|---|
| old `synt_dpc.tcl` | 998.5 | 1065.5 | 572 | 2636 |
| new, `-J 50` (25 s for the three) | 876 | 989 | 471.5 | **2336.5** |
| new, `-J 200` (80 s) | 873 | 989 | 468.5 | 2330.5 |
| new, `-J 1000` (246 s) | 873 | 989.5 | 466.5 | 2329 |

`-J 50` was kept: larger values cost minutes for 0.3 %.

Projection to 1500 for the whole machine (written before §9–§14; the actual result,
1578 for the three blocks, is in §6 and the status table at the top): the measured ApLine cleanup removes 13
triggers (−91 tubes from flops alone), and R1–R3 should remove about 25 more in
IpLine/MachineCtrl. Even so, the three blocks would stay around 1900–2000 before
memory, reset and panel are counted. Reaching 1500 will need more flop reduction
than §5 lists, for example state and flags moved into dekatron-driven sequencing.
That is the next step's question.

## 9. Done: RX handshake, `rx_q` removed (REQ-UART-008)

Changes:
- `ApLine`: the 12-bit `rx_q` register is gone. For CIN, `data_in` comes straight from
  `rx_data_bcd`, and the Data counter loads it during the write window.
- `MachineCtrl`: new output `rx_rdy = (state == S_AP_OP_W) & (ap_op == AP_CIN) &
  ap_ready & ~(soft_rst | hard_rst)`. It is combinational, needs no extra flop, and
  doesn't depend on `rx_vld`. The handshake `rx_vld & rx_rdy` happens in the cycle
  ApLine finishes CIN, so `rx_data_bcd` is stable for the whole write.
- `DekatronPC`: new output port `rx_rdy` (TRS Appendix B, breaking change).
- `Emulator.sv`: a receive buffer (8-bit `rx_data` + `rx_vld`) catches the UART/consul
  byte on the rising edge of its `vld` and holds it until `rx_vld & rx_rdy`. The
  rising edge matters because the consul's `kb_data_vld` lasts many 1 MHz cycles. A
  byte that arrives while the buffer is full is dropped, the same as before.
- Testbenches: `DekatronPC_tb.sv` connects `rx_rdy`. `DekatronPC_tb.cpp` holds
  `rx_vld` until the handshake. `ApLine_tb` gained a CIN check (CIN 65, flush on an
  AP step, LOAD reads back 65).

Verification:
- Verilator `--lint-only -Wall` is clean for DekatronPC and Emulator.
- `run_tests.sh -t`: all Icarus tests pass (Dekatron, Counter, IpLine, ApLine,
  DekatronPC ×2). The Verilator golden-model runs build and exit 0, but they check
  nothing: without `-s`, the core halts after 12 clocks (IRET=0). This was already
  the case before this change and is TRS §22 item 5. Neither of their programs
  runs CIN.
- `tb make regression`: 34/34 PASS. It has no ApLine/MachineCtrl/DekatronPC targets.
- The Emulator receive buffer is checked by lint only.
- Housekeeping: a stale `rtl/run/obj_dir/DekatronPC_tb.d` still pointed to the old
  `tests/DekatronPC.sv/dpcrun.h` and broke the Verilator build. It was deleted.

Synthesis (`run_tests.sh -s`, `-J 50`). `dpc_stat.py` needs the `liberty` module from
`rtl/run/.venv`; with the system python the script ends with exit 1.

| Block | before (§8) | now | Δ |
|---|---|---|---|
| IpLine | 876 | 874.5 | −1.5 (ABC noise, RTL unchanged) |
| ApLine | 989 | 874 | **−115** |
| MachineCtrl | 471.5 | 493.5 | +22 (`rx_rdy` decode, plus ABC variance) |
| Total | 2336.5 | **2242** | −94.5 |

## 10. Done: ApLine FSM rewrite (§4, REQ-APV2-007)

The §4 prototype, now in `rtl/DekatronPC/ApLine.sv` (`rx_q` was already removed in §9).

Changes:
- 9 states → 6: `S_IDLE, S_FLUSH, S_READ, S_AP, S_DSET, S_DOP`. The WAIT states
  (`S_AP_WAIT`, `S_DATA_SET_W`, `S_DATA_WAIT`) are gone.
- The 7 registered strobes are decoded from `state` (Moore):
  `ap_valid = S_AP & go`, `data_valid = (S_DSET | S_DOP) & go`,
  `mem_valid = (S_FLUSH | S_READ) & go`, `mem_wr = S_FLUSH`, `data_set = S_DSET`,
  `ap_set_zero = op==AP_ZERO`, `data_set_zero = op==DATA_ZERO`,
  where `go = ap_ready & data_ready & mem_ready`.
- Each non-IDLE state issues one operation when all three slaves are idle and leaves in
  the same cycle (the handshake happens in that cycle, because the slave's own ready is
  part of `go`). The next state, or IDLE's `ready`, waits for `go` again, so it also
  waits for the previous operation to finish. Slaves' `ready` never depends on `valid`,
  so `valid & go` makes no loop.
- End of a memory access = `mem_ready` returning. `Ram` drops `busy` on the same edge
  that `rd_data` becomes valid, and the data then holds until the next access. So
  `mem_rd_valid` is no longer used by ApLine (the port stays).
- `lock`/`dirty` after `+ - CLRD` are set when `S_DOP` hands the operation to the
  counter (the old code set them one state later). Nothing can observe the
  difference: `ready` stays low until the counter is done.
- External behaviour is unchanged, including the known v0.9 divergence (a clean AP
  step does not clear `lock`, TRS §22 item 8; the fix is not applied).

The held-level `mem_valid` question from §4 is settled by the design: `mem_valid` only rises
together with `mem_ready`, so a held request can't be accepted twice. The old FSM had
two flaws here. On the first access after reset it re-raised `mem_valid` while the
memory was busy (the RAM ignored it). On every later access it took the **stale**
`rd_valid` of the previous access, which stays 1 until the next accept, as the end
of the read in the accept cycle. It worked only because IDLE's `ready` also waits
for `mem_ready`, and the counter write window outlasts the one-cycle read.

Verification (Icarus, `rtl/run/emul ApLine`):
- `ApLine_tb` was extended with STORE, CLRML (twice: dirty and clean), CLRA with a
  dirty cell, the 255 ↔ 0 wrap, memory access counts (20 AP steps → 0 accesses,
  STORE → 1 write, a clean AP step → no write, CLRML → 1 write, TEST/COUT after a
  flush → no read), and a monitor that flags `mem_valid` without `mem_ready`.
- New ApLine: PASS, 485 µs (the old FSM with the extended test: 575 µs and 1 error,
  the monitor on the first access after reset; every functional check passes on
  both).
- `DekatronPC` hello test passes (it only checks IP moving). Verilator `--lint-only -Wall`
  is clean for DekatronPC.
- `-DASSERTIONS` does not build on Icarus (syntax in `DekatronTubeV2_assertions.sv`,
  unrelated), so the ApLine assertions did not run. The tb monitor covers the
  handshake part.
- Not run: the full `run_tests.sh -t`, the Verilator DekatronPC builds and the cocotb
  regression (heavy, AGENTS §0). The cocotb regression has no ApLine target.

Synthesis (`./synth ApLine`, `-J 50`; `equiv_opt` found no problems):

| Block | before (§9) | now | Δ |
|---|---|---|---|
| ApLine | 874 | **719** | **−155** |
| Total (IpLine + ApLine + MachineCtrl) | 2242 | **2087** | −155 |

The ApLine netlist has 32 triggers (18 `DFFSR_n` + 14 `DFF`, counters included).
Block diagram: sheet 5 (`05_2_apline_fsm.svg`) was redrawn with the new states.

## 11. Done: IpLine FSM rewrite (R1, REQ-IPV2-007)

The §4 method applied to `rtl/DekatronPC/IpLine.sv` (item R1 of §5).

Changes:
- 12 states → 11: `S_IDLE, S_IP, S_FETCH, S_FETCH_W, S_SCAN_EVAL, S_LOOP, S_INSN_IN,
  S_WRITE, S_CLR_IP, S_CLR_LOOP, S_HALT`. The pairs `IP_OP/IP_WAIT`, `LOOP_OP/LOOP_WAIT`
  and `CLR_OP/CLR_WAIT` are gone. `clr_is_loop_q` became two states. `S_FETCH_W` is new
  and is the only waiting state: `insn_q` has to latch `rd_data`, and that is valid only
  when the read ends.
- The 8 registered strobes are decoded from `state` (Moore), with
  `go = ip_ready & loop_ready & mem_ready`:
  `ip_valid = (S_IP & ~scan_done | S_CLR_IP) & go`, `loop_valid = (S_LOOP | S_CLR_LOOP) & go`,
  `mem_valid = (S_FETCH | S_WRITE) & go`, `mem_wr = S_WRITE`, `ip_set_zero = S_CLR_IP`,
  `loop_set_zero = S_CLR_LOOP`.
- `ip_dec` and `scan_dec_q` are merged into one `dir_q` (direction of the next IP step:
  scan direction or the ±IP key). `loop_dec = dir_q ? insn_loop_open : insn_loop_close`,
  taken from `insn_q`. `loop_init_q` is gone: on the starting bracket the opposite
  bracket detector is 0, so the first step is an increment by itself.
- End of scan: `S_LOOP` leaves on issue, so the zero check moved to `S_IP`. When
  `scanning_q & loop_is_zero` holds there (after `go`, so the loop step is done), the
  pair is found and the FSM returns to `S_IDLE` without stepping. During a scan the
  nesting counter is 0 only at that moment: the start and own brackets increment it,
  and overflow is caught before the step.
- `mem_wr_data = insn_q` instead of the live `insn_in`. The loader may change `insn_in`
  right after the `insn_in_valid & insn_in_ready` handshake, and `DekatronPC_tb` does.
  The old FSM wrote one cycle after the handshake and took the next opcode. That was found
  by reading the code; it wasn't simulated on the old RTL.
- `halt_pending_q` is now cleared by `soft_rst | hard_rst` too. Before, a reset during
  the halt step left it set, and the next IP step went to `S_HALT` with `halt_rq` low.
- `mem_rd_valid` is no longer used (the port stays, as in ApLine).

Defect of the old FSM, found by the new testbench: it latched `insn_q` in the cycle the
memory **accepted** the read, using the stale `rd_valid` of the previous access (the
same flaw §10 describes for the old ApLine, but here it loses data). With a memory that
follows the `Ram` discipline, every fetch returned the opcode of the previous fetch
(the first one after `rst_n` returned the reset value 0). The old `IpLine_tb` didn't see
this because its memory was combinational and always ready. The DekatronPC test checks
only that IP moves (TRS §22 item 5), so it didn't see it either.

Verification (Icarus, `rtl/run/emul IpLine ../programs/looptest.bfk`):
- `IpLine_tb` rewritten. The test memory now follows `Ram`: `ready = ~busy`, 2 busy
  cycles, `rd_data` is X until `ready` returns, write-through. The test has six parts:
  1. looptest (back scan);
  2. loading a 23-opcode program with nesting depth 3 over `insn_in` (EOT is shown on
     `insn` and not written; `insn_in` changes right after each handshake). Then 400
     fetches with random `loop_val_zero` (131 scans, forward and back), each compared to
     a reference model (address and opcode), with the nesting counter 0 after each
     fetch (REQ-IPV2-003);
  3. overflow: 120 × `[`, the scan stops at IP 99 with the counter at 99, a repeated
     NEXT doesn't move, CLRL clears both (REQ-CNT-007, REQ-IPV2-004);
  4. CLRI: `insn_valid` drops, and the next fetch reads address 0 without a step;
  5. halt: IP+1, `ready` and `insn_valid` low, ±IP keys, after release the fetch reads
     in place;
  6. hard reset: IP = 99900.

  Monitors: `mem_valid` without `mem_ready`, `ip_valid & loop_valid`, X on `insn` at ready.
- New IpLine: PASS, 9259 µs simulated, 1.6 s wall time. Old IpLine on the same test:
  hangs in part 1 (stale opcodes).
- Verilator `--lint-only -Wall` is clean for DekatronPC. The DekatronPC hello test
  (Icarus) passes, but it checks only that IP moves.
- Not run: the full `run_tests.sh -t`, the Verilator DekatronPC builds and the cocotb
  regression (heavy, AGENTS §0).

Synthesis (`./synth IpLine`, `-J 50`; `equiv_opt`: 129/129 `$equiv` cells proven). The
old IpLine was synthesized with the same flow from a scratch copy:

| | old | new | Δ |
|---|---|---|---|
| IpLine, tubes | 902 | **722** | **−180** |
| Triggers (counters included) | 51 | 40 | −11 |

The `−180` compares two runs made today with the same flow. Against the §9 figure
(874.5, same RTL as "old") it is −152.5; the 27.5 gap is ABC variance.

The three blocks from today's netlists: IpLine 722 + ApLine 714 + MachineCtrl 512 =
**1948**. ApLine and MachineCtrl RTL didn't change since §10; their figures (719 and
493.5 then) moved with ABC variance.

Block diagram: sheet 4 (`04_1_ipline.svg`, `04_2_ipline_fsm.svg`) redrawn. No SVG
renderer was available, so the layout was checked by coordinates only.

## 12. Done: MachineCtrl FSM rewrite (R2, REQ-CTLV2-010)

The §4 method applied to `rtl/DekatronPC/MachineCtrl.sv` (item R2 of §5). The external
interface and the op codes sent to IpLine/ApLine are unchanged.

Changes:
- 15 states → 10: `S_HALT, S_IDLE, S_FETCH_W, S_DECODE, S_EXEC, S_WAIT, S_COUT, S_CIN_WAIT,
  S_RST_REQ, S_RST_WAIT`. `S_IDLE` issues the fetch itself (old `S_IDLE` + `S_FETCH`).
  `S_IP_OP`/`S_AP_OP` became one `S_EXEC`, and the two `_W` states one `S_WAIT`. `S_ECHO` is
  gone (echo goes through `S_COUT`), and so is the unreachable `S_BELL`. The codes of `S_HALT`,
  `S_IDLE`, `S_DECODE` and `S_CIN_WAIT` are kept, because `DekatronPC_tb.cpp` uses them.
- Moore strobes, with `go = ip_ready & ap_ready & ~(soft_rst | hard_rst)`:
  `ip_valid = (S_IDLE & ~halt_key | S_EXEC & is_ip_op) & go`,
  `ap_valid = (S_EXEC & ~is_ip_op | S_CIN_WAIT & ~halt_key & rx_vld) & go`,
  `tx_vld = S_COUT`, `rx_rdy = S_WAIT & is_cin & go`, `*_rst_req = S_RST_REQ & type`.
- **Decode once, without registers.** `ip_op`, `ap_op` and `ap_dec` are combinational from
  `{insn_mode, insn}`. IpLine holds `insn` in `insn_q` until the next fetch, and the next fetch
  waits for `go`, so the op codes stay stable until the slave's `ready`, as Valid/Ready
  requires. This removes 7 registers while keeping ApLine's and IpLine's op encoding (the
  rest of R3 is still open). `ap_dec = insn[0]` also feeds non-step ops; `DekatronCounter`
  ignores `dec` when `set`/`set_zero` is active.
- `echo_pending` removed: `S_WAIT` goes to `S_COUT` when the finished op was CIN (`is_cin`
  from `insn`) and `echo_mode` is on.
- `bell` is a pulse in the cycle of the event (HALT opcode, BELL, CIN, `halt_key` in
  `S_IDLE`, overflow). `bell_pending` and the `bell` register are gone. `Bell` isn't connected
  in `Emulator.sv`.
- `rst_type` (2 bits) → `rst_soft` (1 bit). `RunOnHardRst`/`RunOnSoftRst` act when
  `S_RST_WAIT` ends: it goes straight to `S_IDLE`, not through `S_HALT`, so `RST_NONE` isn't
  needed. On power-up the relay always gives a hard reset, so `run_on_hard_rst` still works
  after `rst_n`.
- **Overflow halts (REQ-CTLV2-005).** `overflow_hit = loop_overflow & ~overflow_q`
  (`overflow_q` is last cycle's `loop_overflow`) takes priority over the whole `case`. The old
  code had two defects. `state <= S_HALT` came before `case (state)`, and the `S_FETCH_W` branch
  overrode it (`doc/dpcrun_golden_model.md` §5.2). Also, CLRL cleared `error_flag` in
  `S_DECODE`, but IpLine drops `overflow_q` only when it accepts CLR_LOOP. In between,
  `error_flag` was set again, and the next overflow didn't halt either. The edge detector has
  no clear, so neither problem can occur.
- Flops: 25 → 9 (`state` 4, `insn_mode`, `insn_loading`, `one_step`, `overflow_q`, `rst_soft`;
  `iret` only with `EN_EMULATOR`).
- One clock less per instruction (the old `S_FETCH`): a NOP takes 7 clocks instead of 8.

Not changed, by owner decision: COUT. `.` still raises `tx_vld` without `AP_COUT` (OPEN-017).
The simulation below printed `Hello WWrld!!` with **both** FSMs, as
`doc/dpcrun_golden_model.md` §5.1 predicts. The cause is the stale memory register after `>`:
ApLine's `S_AP` clears `mem_here_q` without reading, and `Ram` updates `rd_q` only when it
accepts an access (`RAM.sv:109-121`). So, with `lock_q = 0`, `tx_data_bcd = cell_from_mem` is the
previous cell. The owner then chose to print always from the Data counter; see §13.

Verification:
- New `rtl/tests/MachineCtrl.sv/MachineCtrl_tb.sv` (`rtl/run/emul MachineCtrl`, added to
  `run_tests.sh -t`). It uses models of IpLine (opcodes from a queue), ApLine (busy 1–4 random
  cycles, checks that `ap_op`/`ap_dec` stay stable until `ready`), the time relay and the terminal.
  Parts:
  1. all 32 `{insn_mode, insn}`: which op goes to which slave, `dec`, bell, ISA switch, HALT
     with `bell_on_halt`; `loop_val_zero` source;
  2. TEST before a bracket only in BF and only when `data_zero_valid` is low;
  3. CIN with and without echo, `bell_on_cin`, `halt_key` while waiting;
  4. loading: nothing runs, ISA1 inside makes 0x4 a `>`, EOT with and without `SoftRstOnEOT` +
     `RunOnSoftRst`, panel load start/stop keys;
  5. HRST/SRST with `RunOn*` 0/1, panel hard reset during CIN, panel soft reset during loading;
  6. overflow: halt, bell, the bracket is not decoded, Run does not halt again, after CLRL a new
     overflow halts again;
  7. halt key, step: one instruction per press while the key is held.

  Monitors: `ip_valid`/`ap_valid` without `ready`, both at once, `rx_rdy` before CIN ends or
  without `rx_vld`, both reset requests at once.
  New FSM: PASS. Old FSM, same tb (it doesn't depend on state codes): 6 errors, all in part 6
  (the two overflow defects above). Every other check passes on both.
- `DekatronPC_tb` (Icarus) with the existing `TRY_PROGRAM` scenario, in a scratch copy: the
  bootloader starts, helloworld is loaded over `InsnIn`, EOT gives a soft reset, `RunOnSoftRst`
  runs the program. TX characters and IP at each character are identical for the old and new
  FSM (`Hello WWrld!!`). Both halt at IP 113. The new FSM is about 8 % faster between the first
  and last character (14.06 ms vs 15.36 ms of simulated time).
  The scenario isn't usable as checked in, and that was the case before this change:
  - `generate_rom.py` output has no leading ISA1, so in Debug ISA the first `>` (0x4) is EOT
    and only `++++++++++[` is loaded;
  - `@(posedge IsHalted)` caught the old FSM's one-cycle pass through `S_HALT` after the soft
    reset, before the program ran;
  - the tb's final TX compare never completes (it isn't enabled by any cfg).

  For the run, the scratch copy prepended `0xF` and waited for the TX count before waiting
  for HALT.
- Verilator `--lint-only -Wall` is clean for DekatronPC. `./emul DekatronPC` (hello cfg) passes.
- Not run: the Verilator golden-model builds (`run_tests.sh -s`, heavy) and the cocotb
  regression (it has no MachineCtrl target).

Synthesis (`./synth MachineCtrl`, `-J 50`, 6 s; `equiv_opt`: 62/62 `$equiv` cells proven):

| | old (§11 netlist) | new | Δ |
|---|---|---|---|
| MachineCtrl, tubes | 512 | **284.5** | **−227.5** |
| Triggers | 25 | 9 | −16 |

R2 was estimated at −80…−110 (§5). The extra came from decoding the op codes from `insn`
(part of R3) and from the cleanup of the bell, echo and reset-type flags.

The three blocks: IpLine 722 + ApLine 714 + MachineCtrl 284.5 = **1720.5** (the
2026-10-06 baseline was 2636 with the same library).

Block diagram: sheet 6 (`06_*`) redrawn.

## 13. Done: COUT always from the Data counter (R7, OPEN-017)

Owner's decision after §12: drop the `tx_data_bcd = lock ? data_out : cell_from_mem` mux
and always print the Data counter. If MemLock is off, load the cell into the counter first.

Changes:
- `ApLine`: `tx_data_bcd = data_out`. `OP_COUT` in `S_IDLE`: with `lock_q` nothing to do.
  Otherwise go to `S_DSET` if `mem_here_q`, else `S_READ` → `S_DSET`. `S_READ` now
  goes to `S_DSET` for everything except `OP_TEST`. MemLock and `dirty` don't change, as with
  LOAD. Setting `lock` here would hit the known v0.9 divergence (a clean AP step doesn't
  clear `lock`), and the next `.` after `>` would print the old cell again.
- `MachineCtrl`: `.` (`5'h18`) goes to `S_EXEC` with `ap_op = AP_COUT`. `S_WAIT` goes
  to `S_COUT` for COUT, or for CIN with echo. `tx_vld` therefore rises only when ApLine is
  done, and the counter doesn't change while `tx_vld` is high.
- Cost: one counter write window per `.` when MemLock is off. At 110 baud it doesn't matter.
  Memory reads are the same as before: a read only when the register isn't on the
  current cell.

Verification:
- `ApLine_tb`: new part "COUT after an AP step without MemLock". A `<` with the counter holding
  cell 1 must make COUT read cell 0 (1 read, value 124). Back to cell 1: 1 read, value 1. A
  second COUT: no read. MemLock stays off. New ApLine: PASS. The old ApLine also passes this
  part: its `OP_COUT` already read the cell. The defect was only that MachineCtrl never
  issued it.
- `MachineCtrl_tb`: `.` must issue exactly one `AP_COUT` and one TX. A new monitor fails on
  `tx_vld` while ApLine is busy. PASS.
- `DekatronPC_tb` (`TRY_PROGRAM`, the scratch copy from §12): helloworld through the
  bootloader now prints **`Hello World!\n`** (13 characters), and halts at IP 113.
- Verilator `--lint-only -Wall` is clean for DekatronPC.
- Not run: `run_tests.sh -s` (golden-model comparison). The dpcrun golden model was changed to
  match: COUT without MemLock loads the cell into the counter, and `txData()` is the counter
  (`doc/dpcrun_golden_model.md` §5.1). bfutils unit tests: 55 tests, 482 checks pass.

Synthesis (`-J 50`, `equiv_opt` proven: ApLine 127/127, MachineCtrl 62/62):

| Block | §12 | now | Δ |
|---|---|---|---|
| ApLine | 714 | **679.5** | −34.5 |
| MachineCtrl | 284.5 | 282 | −2.5 |
| IpLine (RTL unchanged, netlist on disk) | 722 | 711 | ABC variance |
| Total | 1720.5 | **1672.5** | |

R7 was estimated at −20…−30.

Block diagrams: sheets 5 and 6 redrawn. The dashed "COUT: immediately tx_vld" edge and the
OPEN-017 note are gone.

## 14. Done: decode once (R3) and the opcode held by memory (R4)

Items R3 and R4 of §5. §12 had already decoded the op codes from `insn` without
registers. This step removes the op codes themselves, and the opcode register in
IpLine.

### R3: the instruction is the op code (REQ-APV2-008)

- `ApLine.op` is now `{insn_mode, insn}` (5 bits), wired in `DekatronPC` straight from
  `insn_mode` and `Insn`. ApLine decodes it itself: `0x0A`/`0x1A` zero data, `0x0B` zero
  AP, `0x12`/`0x13` step data, `0x14`/`0x15` step AP, `0x16`/`0x17` TEST, `0x18` COUT,
  `0x19` CIN, `0x1B` CLRML, `0x1C` LOAD, `0x1D` STORE. Other codes are NOP (MachineCtrl
  doesn't issue them). The step direction is `op[0]`, so the `dec` port is gone.
- The `ap_op` encoder, `ap_op[3:0]` and `ap_dec` are gone from MachineCtrl.
- IpLine gets one bit, `clr` (MachineCtrl's `ip_clr = S_EXEC`), instead of `ip_op[1:0]`.
  With `clr`, IpLine picks CLRI or CLRL from `insn[0]` of its own opcode.
- The decode is exact (no don't-cares on unused codes), per the "no X-masking" rule.

### R4: no `insn_q` in IpLine (REQ-IPV2-008)

The precondition from §5 was checked in `RAM.sv`. `Ram.rd_data` changes only when an
access is accepted: the bank's `rd_q` and the group's `digit_q` load on `bank_en`, and
`ovl_hit_q`/`ovl_data_q` load on `accept`. IP steps, CLRI and halt don't touch memory, and
IpLine starts the next access only after MachineCtrl has finished with the current
instruction (`ready` needs `go`). So `insn = mem_rd_data` holds while MachineCtrl
decodes and ApLine executes. The ferrite memory behaves the same way: the value stays in
the sense amplifiers until the next access.

EOT isn't stored in memory (neither RTL nor `dpcrun` writes it), so the register can't
show it. Two options were put to the owner: a 1-bit flag, or writing EOT to memory as well
(which changes the loaded image and `dpcrun`). **The owner chose the flag.** `eot_q` is set
when S_INSN_IN accepts EOT, cleared by the next accepted operation and by the reset lines.
It goes to MachineCtrl as `insn_eot`. In loading mode MachineCtrl checks `insn_eot` first,
then ISA0/ISA1 from `insn`. After write-through, `insn` holds the opcode that was just
written.

Loading writes the opcode in the handshake cycle. `insn_in_ready = S_INSN_IN & insn_loading & go`
(free memory, doesn't depend on `insn_in_valid`). `mem_valid` also covers
`insn_in_valid & insn_in_ready & ~EOT`, and `mem_wr_data = insn_in`. This is the one Mealy
strobe in IpLine: valid follows the loader's valid, while ready still doesn't depend on
valid. The loader already holds `insn_in` until the handshake.

States 11 → 9:
- `S_WRITE` is gone. S_INSN_IN goes to S_IDLE on the handshake, and S_IDLE's `ready`
  waits for the write to finish.
- `S_FETCH_W` only existed to latch `insn_q`, so it is gone too. S_FETCH goes to S_IDLE
  (or S_SCAN_EVAL while scanning) when the read is issued. S_SCAN_EVAL now waits for
  `go` before it looks at the opcode.

Edge case: a write into the bootloader area is rejected by `Ram` (`err`), and `rd_data`
then shows the ROM opcode, not the one sent. Before, MachineCtrl decoded the opcode as
sent. This only matters for a write that is already an error.

### Verification

- `IpLine_tb`:
  - `clr` replaces `op`. For CLRI/CLRL the tb puts the opcode into the memory model's
    register.
  - `insn` must equal the opcode just written after every load.
  - After EOT, `insn_eot` and `insn_valid` must be set, and the next request must clear
    `insn_eot`.
  - A monitor checks that `insn` doesn't change while the memory is idle. This checks the
    memory model's discipline, the precondition R4 relies on.
  - The loader raises `insn_in_valid` before `insn_in_ready`.
  - PASS. `looptest` part 1 runs about 13 % faster (8038 µs vs 9259 µs for the whole tb).
- `ApLine_tb`: op names map to opcodes. Added: Debug CLRD `0x0A` next to BF `[-]` `0x1A`,
  and `]` as TEST. PASS.
- `MachineCtrl_tb`:
  - The IpLine model now behaves like the RTL. EOT during loading doesn't change `insn`
    and raises `insn_eot`.
  - The ApLine model checks that `{insn_mode, insn}` stays stable until `ap_ready` and
    that only data ops reach ApLine.
  - A new monitor fails on `ip_clr` with anything but CLRL/CLRI.
  - PASS.
- Mutations:
  - IpLine never sets `eot_q`: `IpLine_tb` fails ("EOT not reported").
  - MachineCtrl decodes EOT from `insn` the old way: `MachineCtrl_tb` fails 5 checks.
- `DekatronPC_tb` (Icarus, `run_tests.sh -t` configs): helloworld through the bootloader
  prints `Hello World!\n`, halts at IP 112; `program.bfk` passes.
- Verilator `--lint-only -Wall`: clean for `DekatronPC` and `Emulator`.
- Not run: the Verilator golden-model comparison (`veremul`, full DekatronPC build) and the
  cocotb regression (it has no targets for these blocks).

### Synthesis

HEAD and the new RTL were synthesized the same day with the same flow (`./synth`,
`-J 50`). `equiv_opt` is proven on all six runs (new RTL: IpLine 125/125, ApLine 130/130,
MachineCtrl 57/57).

| Block | HEAD | R3 + R4 | Δ |
|---|---|---|---|
| IpLine | 717.5 | **652** | −65.5 |
| ApLine | 675.5 | 676 | +0.5 |
| MachineCtrl | 282 | **250** | −32 |
| Total | 1675 | **1578** | **−97** |

Triggers in the IpLine glue (counters excluded): 22 → 17. `insn_q` costs −4 and `eot_q`
+1. The other −2 come from the state register, which Yosys extracts and encodes one-hot,
so 11 → 9 states. The MachineCtrl and ApLine glue triggers don't change (9 and 9).

The estimates were R3 −30…−50 and R4 −15…−20. As expected, ApLine pays for the 5-bit
decode about what MachineCtrl's encoder cost. The extra gain comes from the two removed
IpLine states.

Block diagrams: sheets 4, 5, 6 and 7 redrawn (no SVG renderer available; layout checked
by coordinates).

## 15. Done: relays for the panel switches (REQ-MOD-011)

Owner's request (2026-10-07): logic that only a panel switch controls (EN or MUX on a
switch) doesn't need tubes. A relay does the same with no filament. Only 2CO relays
(one coil, two changeover contacts) are used. A relay may only be driven by a user
switch, never by fast or clocked logic. Where a relay saves no tube, the tubes stay.

### Library and modules

- `rtl/vtube/vtube_cells.lib`: cell `RELAY_2CO` (pins `COIL`, `NC1/NO1/C1`, `NC2/NO2/C2`;
  `Cn = COIL ? NOn : NCn`), area 0, `heat_current` 0, group `relays(names) { RELAY_2CO: 1; }`.
  The output pins have **no function**, so ABC never uses the relay as a general mux;
  it only appears where RTL instantiates it. Model in `rtl/vtube/vtube_cells.v`.
- `rtl/Logic/Relay.sv` (added to `DPC.files` and `Emulator.qsf`):
  - `RELAY_2CO` behavioral model under `ifndef SYNTH` (in synthesis the liberty cell is used);
  - `RelayMux #(W, S)`: 2^S words of W bits, selected by S switches. A tree of changeover
    contacts, select bit l switches 2^(S−1−l)·W contacts, two per relay:
    relays = Σ_l ⌈2^(S−1−l)·W / 2⌉;
  - `RelayEn #(W)`: `y = en ? a : 0`, NC contacts tied to 0; relays = ⌈W / 2⌉.
  - Both have `(* keep_hierarchy = "yes" *)`, so `synth -top` doesn't flatten them.
  - Each tree level is its own vector. One array for all levels was a false loop for
    Verilator (UNOPTFLAT), fixed structurally (AGENTS.md §5).
- `rtl/run/dpc_stat.py`: prints a `Relays` column per block and the total. The cell
  table now multiplies by instance counts (before, it summed cells per module
  *definition* and undercounted repeated submodules: its tube column added up to ~1528 of 1595.5).

### Where relays went, and where they didn't

Switch-controlled logic in RTL lives only in `MachineCtrl` (IpLine/ApLine have no
switch inputs). Each site was measured: MachineCtrl synthesized in all 8 combinations
(bell / run / echo relays on or off) × 7 ABC seeds (`&deepsyn -S 0…6`), then each bell
site separately (8 × 7). Main effect = mean tubes with the relay − mean without it.

| Site | RTL | Relays | Effect, tubes | Decision |
|---|---|---|---|---|
| `BellOnHALT` | `RelayEn` on the HALT bell term | 1 | −1.8 | relay |
| `BellOnCIN` | `RelayEn` on `decode_run & is_cin` | 1 | −3.0 | relay |
| `BellOnError` | `RelayEn` on `overflow_hit` | 1 | −1.6 | relay |
| `RunOnSoftRst` / `RunOnHardRst` | `RelayMux #(1,2)`: `{soft, hard}` selects `{1, rst_soft, ~rst_soft, 0}` | 2 | −1.3 (no mux cell in the library: a 2:1 mux costs gates) | relay |
| `EchoMode` | `is_cin & echo_mode` | – | −0.3 (noise: the AND merges into the next-state term) | **tubes** |
| `SoftRstOnEOT` | FSM branch in `S_DECODE` | – | not a MUX/EN: the switch picks the next state, the gate stays either way | **tubes** |

`run_on_rst` was `rst_soft ? run_on_soft_rst : run_on_hard_rst`, so the select was the
`rst_soft` trigger, not a switch. To keep the rule "coils only from switches" it was turned
around: the two switches drive the coils and `rst_soft`/`~rst_soft` (`QN`, free) pass
through the contacts. Behaviour is unchanged.

Total: **5 RELAY_2CO**. One contact is spare in each `RelayEn #(1)` and in the second
level of the `RelayMux`.

| MachineCtrl variant (bell/run/echo) | mean of 7 seeds | min | max |
|---|---|---|---|
| none (before) | 254.3 | 250 | 259 |
| bell + run (chosen) | 249.8 | 246.5 | 252.5 |
| bell + run + echo | 248.3 | 245.5 | 254 |

bell + run + echo is 1.5 lower on average, but echo's main effect over all 8 combinations
is −0.3, within noise, so echo stays on tubes per the owner's rule.

### Verification

- Exhaustive Icarus check of `RelayMux`/`RelayEn` against `d[sel*W +: W]` and `en ? a : 0`
  for (W,S) = (1,1), (1,2), (3,2), (4,3), (5,1), (2,4), 200 random vectors each: 0 errors.
- `MachineCtrl_tb` (all checks, including bell, echo, run on hard/soft reset, SoftRstOnEOT)
  and `DekatronPC_tb` (helloworld, program.bfk) pass on Icarus.
- Verilator `--lint-only -Wall`: clean for `DekatronPC` and `Emulator`.
- Synthesis `run_tests.sh -s`: `equiv_opt` proven on all three blocks (relays are black
  boxes on both sides).

| Block | Tubes | Relays |
|---|---|---|
| IpLine | 661.5 | 0 |
| ApLine | 684 | 0 |
| MachineCtrl | 250 | 5 |
| Total | **1595.5** | **5** |

Note: today's IpLine/ApLine (661.5 / 684) differ from §14 (652 / 676) although their RTL
didn't change in this step. Synthesizing them without the relay cell in the library gave
662.5 / 681.5, so ABC results move by ±10 tubes between runs. Comparisons below ~5 tubes
need several seeds (as above), not one run.

Block diagram: sheet 6 marks which switches go through relays.

## 16. Speed over tubes: prefetch P3 (REQ-PERF-003)

The owner chose P3 from `doc/cycle_profile_helloworld.md`: the next opcode is fetched while
ApLine works. That brings back an opcode register, removed in §14 (R4) to save tubes,
this time as `op_q` in MachineCtrl. Over 3 seeds, MachineCtrl goes from 248.3 to 318.7
tubes (+70.4). The 5 new flops cost 35 tubes; the rest is the load enable and decoding.
IpLine is unchanged (663.7 → 663.8). In exchange, helloworld runs in 4184 cycles instead
of 5540. Details, per-seed numbers and the 8-tube cheaper of the two variants:
`doc/prefetch_p3.md` §5.

## 17. Second attempt toward 1200 (2026-10-08)

The goal is still REQ-MOD-009, 1200 tubes for the whole machine. This round looked for
levers outside FSM cleanup. All experiments ran on scratch copies of the RTL, and nothing
in the repo was changed except this report. Flow: `synt_dpc.tcl` as committed (Yosys 0.51,
`&deepsyn -J 50`, `equiv_opt`, `qn_absorb.py`). "Seed" means `&deepsyn -S`.

### 17.1 Where the tubes are now

HEAD (4f3f4ad), three seeds: **1669.5 / 1644 / 1653.5, mean ≈ 1656** for IpLine + ApLine +
MachineCtrl (§16 had ≈ 1666.5; the `dirty_q` removal is within noise). There are 80 triggers
(560 tubes, 34 %):

| Where | Triggers | What they are |
|---|---|---|
| 4 counters | 41 | carry flags `nines_q`/`zeroes_q` (+ `zero_q`/`at_top_q` in Data): 24; state register, **one-hot** after Yosys FSM extraction: 4–5 per counter, 17 |
| IpLine glue | 17 | state one-hot (9), `dir_q`, `ip_counted_q`, `insn_valid`, `scanning_q`, `loop_overflow`, `key_moved_q`, `halt_pending_q`, `insn_eot`, `mem_wr` |
| ApLine glue | 8 | state one-hot (5), `mem_here_q`, `mem_lock`, `mem_wr` |
| MachineCtrl | 14 | state (4, binary: it is an output port, so it isn't extracted), `op_q` (5), `ip_ahead`, `insn_loading`, `rst_soft`, `one_step`, `overflow_q` |

### 17.2 Measured: binary state encoding (−219)

§2.1 concluded that the encoding doesn't matter, but both passes it compared ran after
`synth` and were no-ops. Setting the encoding through the attribute before synthesis:

```systemverilog
(* fsm_encoding = "binary" *) logic [2:0] state;   // DekatronCounter (next split off)
(* fsm_encoding = "binary" *) logic [2:0] state;   // ApLine
(* fsm_encoding = "binary" *) logic [3:0] state;   // IpLine
```

IpLine + ApLine (MachineCtrl isn't affected):

| Variant | Seed 0 | Seed 1 | Seed 2 | Mean | Δ |
|---|---|---|---|---|---|
| HEAD (one-hot from Yosys) | 1335.5 | 1329 | 1327 | 1330.5 | – |
| counters binary only | 1249 | | | | −86.5 |
| IpLine/ApLine binary only | 1189.5 | | | | −146 |
| all `fsm_encoding = "none"` (keep the RTL codes) | 1187 | | | | −148.5 |
| **all binary** | **1116.5** | **1108** | **1111** | **1111.8** | **−218.7** |

The three blocks: ≈ 1656 → **≈ 1437** (1450.5 / 1423 / 1437.5). Triggers 80 → 64 (counters
41 → 33, IpLine 17 → 12, ApLine 8 → 5). The logic shrinks as well, because one-hot
next-state logic on 7-tube triggers isn't cheaper than binary decoding in this library.
`equiv_opt` passes. `synth_sim.sh Counter IpLine ApLine` on the binary netlists: all PASS.
DekatronPC and the delay/SDF runs weren't repeated.

MachineCtrl keeps its hand-written codes because `state` is an output port (it only goes
to the panel display, `DPC_currentState`). 24 random code assignments (seed 0) gave
320.5…355 tubes, and today's codes gave 334. A search would gain about −10…−15, which is
close to the ±10 drift. The panel decode would have to follow the new codes.

### 17.3 Breakdown after binary encoding (seed 1, 1423)

| Part | Tubes | Note |
|---|---|---|
| `DekatronPulseSender`, 15 decades × 6 | 90 | AND-OR of StepF/StepR with Phase1/Phase2 |
| `BinToBcd`, 13 decades × 9 | 117 | Loop has READ = 0 in the real machine |
| `BcdToBinEn`, 3 decades (Data) × 20.5 | 61.5 | |
| `DekatronPhaseGen`, 4 × 2.5 | 10 | |
| Counter control (FSM, carry chain, 33 triggers = 231) | 407 | Loop 58, IP 116, Data 118, AP 115 |
| IpLine glue (+ InsnLoopDetector 5.5) | 243 | 12 triggers |
| ApLine glue | 179.5 | 5 triggers |
| MachineCtrl | 315 | 14 triggers |

The counters are still 685.5 tubes (48 %).
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

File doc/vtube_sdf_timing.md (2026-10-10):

# Tube delays on the netlist: SDF annotation and setup/hold checks

Date: 2026-10-08. Related: REQ-VER-025 (netlist simulation), REQ-DEK-010
(delay model), OPEN-013/014 (timing calibration, is 1 MHz achievable).

## 1. What was built

Gate-level simulation (`synth_sim.sh -d`) used zero-delay cell models. A new
mode `-t` gives every vacuum-tube cell a real delay and checks the triggers
for setup and hold.

| File | Role |
|---|---|
| `rtl/vtube/vtube_cells.v` | each cell got a `specify` block with every input→output path at delay 0. Without `iverilog -gspecify` the blocks are ignored and the earlier flows behave exactly as before (checked: `-d` Dekatron, Counter, DekatronPC pass). |
| `rtl/vtube/vtube_timing.json` | **the only place for the numbers**: per cell, per arc (`A->Y`, `posedge C->Q`, `S->Q`, …), one value or `[rise, fall]` in ns; `setuphold` for the triggers. |
| `rtl/run/vtube_sdf.py` | reads the netlist, the specify paths and the table; writes one SDF per netlist module and `vtube_sdf.sv`, a second simulation root with the `$sdf_annotate` calls, the checkers and a summary line. |
| `rtl/vtube/vtube_timing_check.v` | `vtube_setuphold`, a behavioural setup/hold checker. Icarus parses `$setuphold` and SDF `TIMINGCHECK` but never checks them (tested on Icarus 13). |
| `rtl/run/synth_sim.sh` | `-t` (tube delays, implies `-d`, output in `synth_sim_timing/`), `-c NS` (Clk period). |
| `Dekatron_tb`, `Counter_tb`, `DekatronPC_tb` | under `DEKATRON_DELAY_MODEL` the Clk period is `` `CLK_NS `` (default 1000 ns). |

Current values (estimates, to be replaced by SPICE and hardware numbers):

* every logic cell, every arc: 150 ns;
* DFF / DFFSR / DFFSR_n: C→Q 150 ns, S/R→Q 150 ns, setup 150 ns, hold
  150 ns (a trigger is two latches in a row: the master needs 150 ns to
  take D, and D must stay 150 ns after the edge until the slave closes it off);
* RELAY_2CO contacts: 0 ns (metal contacts, coil only from panel switches);
* LATCH: D→Q, C→Q 150 ns, no setup/hold check (not used in the netlists).

Black boxes that come back from RTL keep their own timing: the dekatron
tube, OneShot, Impulse, RstTimeRelay, Ram, IpMemory.

```
cd rtl/run
./synth_sim.sh -t -c 10000                 # Dekatron Counter DekatronPC, Clk 10 us
./synth_sim.sh -n -t -c 2000 DekatronPC    # reuse the netlist, Clk 2 us
```

A run fails if the testbench fails, if Icarus reports any SDF ERROR/WARNING,
or if the summary line is not `VTUBE TIMING: 0 setup, 0 hold violations`.
Under `-t`, files written by the simulation are capped at 2 GB (`ulimit -f`).
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

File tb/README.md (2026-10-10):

# DekatronPC UVM Test Infrastructure

Cocotb-based layered testbench for the DekatronPC processor — a vacuum-tube computer implemented in SystemVerilog.

## Quick Start

```bash
cd tb
make test_compare SIM=icarus        # single test
make test_insn_decoder SIM=icarus   # single test
make regression                     # full suite (~40 targets)
```

## Requirements

- Python 3.8+ with `cocotb>=2.0`, `pyuvm`, `pytest`
- Icarus Verilog (iverilog) for module-level tests
- Verilator for full DPC/Emulator integration tests

```bash
pip install "cocotb>=2.0" pyuvm pytest
```

Don't install `cocotb-coverage` alongside: it pins `cocotb<2`, and pip then downgrades cocotb to 1.9,
which breaks the tests (`unit=` keyword). `conftest.py` imports it optionally.
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

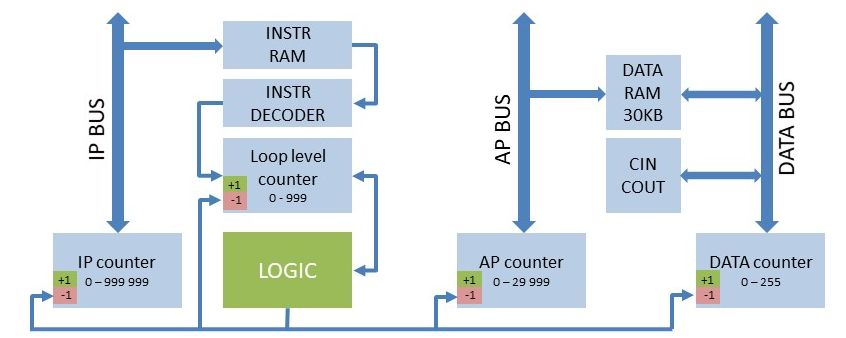
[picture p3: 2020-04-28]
img/DPC_Arch.jpg

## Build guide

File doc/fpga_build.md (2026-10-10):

# FPGA bitstream build from the command line

Tool: `rtl/run/build_fpga.sh`. Target: the Emulator top (`rtl/Emulator/Emulator.sv`) on DE0-Nano-SoC, Cyclone V 5CSEMA4U23C6 (REQ-RTL-001, REQ-RTL-004).

## 1. Why a separate build project

The GUI project `rtl/quartus/Emulator.qsf` has a hand-kept file list that has fallen behind the RTL. It still lists `Dekatron.sv`, `DekatronPulseAllow`, `InsnDecoder` and `RsLatch`, and it lacks `MachineCtrl.sv`, `DekatronTubeV2.sv`, `DekatronPhaseGen.sv`, `FirmwareLoader.sv` and the UART. The script builds a fresh project in `rtl/quartus_build/` (gitignored) on every run:

- device, pins, partitions and other settings come from `rtl/quartus/Emulator.qsf`; its file, SDC and macro lines are dropped;
- sources come from `rtl/DekatronPC/DPC.files` and `rtl/Emulator/Emul.files`, the same lists Verilator uses in `run_emul.sh`, so simulation and FPGA build one file set. `*_assertions.sv` files are skipped because they are bound only under `ASSERTIONS`;
- the SDC is `rtl/quartus/Emulator.sdc`, and `EMULATOR=True` is always defined;
- `VERILOG_CONSTANT_LOOP_LIMIT` is raised to 100000. `RamBank`'s zero-init `for` loop runs over a whole bank (10⁴ cells in IpMemory with `BANK_DIGITS = 4`), and Quartus stops at its default of 5000 iterations (`Error (10106) ... RAM.sv(147)`).

The build directory has to sit directly under `rtl/`. The file lists use `../X` paths, and `FirmwareLoader`/`MS6205` call `$readmemh("../….hex")`, which Quartus resolves relative to the project directory. Before each build the script regenerates the firmware images (`rtl/firmware.hex`, `rtl/load_firmware*.hex`) from `rtl/programs/*.bfk` with `generate_rom.py`, the same way `run_emul.sh` does.

The GUI project is left untouched.

## 2. Usage

```
cd rtl/run
./build_fpga.sh                 # syn + fit + asm + sta -> rtl/quartus_build/output_files/Emulator.sof
./build_fpga.sh elab            # analysis & elaboration only (about 1 min)
./build_fpga.sh syn             # analysis & synthesis only
./build_fpga.sh -p              # compile, then program the FPGA over JTAG
./build_fpga.sh program         # program the existing .sof, no rebuild
./build_fpga.sh --rbf           # also write Emulator.rbf (compressed, for loading from HPS Linux)
./build_fpga.sh --list-cables   # JTAG cables seen by quartus_pgm
./build_fpga.sh -n              # write the project, print the Quartus commands, run nothing
./build_fpga.sh -D CONSUL=1     # extra Verilog macro (repeatable)
```

The exit code is the verdict. After a run the script prints the `map`/`fit`/`sta` summaries.

Programming uses JTAG device index 2: on DE0-Nano-SoC the chain is HPS (1) then FPGA (2). Override it with `-i`, and pick the cable with `-c`.

## 3. Finding Quartus

The script checks, in order: `--quartus DIR`, `$QUARTUS_BIN`, `quartus_sh` on `PATH`, then `~/intelFPGA_lite/*/quartus/bin`, `/opt/intelFPGA*/…` and, under WSL, `/mnt/c/intelFPGA_lite/*/quartus/bin64` (newest version first). The Windows install (`quartus_*.exe`) works from WSL with the project on the WSL filesystem (`\\wsl.localhost\…`): relative paths and `$readmemh` resolve correctly. This was checked on Quartus Prime Lite 23.1std.0 Build 991. `quartus_pgm.exe` uses the Windows USB-Blaster driver, so no USB passthrough into WSL is needed.

## 4. Results so far (2026-10-07)

| Stage | Result |
|---|---|
| `-n` (dry run) | Project generated, 51 pin assignments carried over. |
| `elab` before the loop limit | `Error (10106)`: loop in `RamBank` (RAM.sv:147) exceeds 5000 iterations. |
| `elab` | Successful, 0 errors, 212 warnings, 58 s, peak about 4.8 GB virtual memory. |
| `syn` / `compile` before the RamBank fix | `Error (276003)` in Analysis & Synthesis (35 s, peak 4.96 GB), see §5. |
| `syn` / `compile` after the fix | Not run yet. This is a heavy job; per AGENTS.md §0 it waits for the owner's go-ahead. |

Memory is expected to fit: OPEN-015 was closed in TRS v0.8 by `BANK_DIGITS = 4` (about 80 memory blocks instead of 1300). With the debug read port (`EN_EMULATOR = 1`) Quartus may duplicate each bank for the second read address; even then the two memories need about 1.4 Mbit of the device's 2.7 Mbit (270 M10K blocks).

## 5. RamBank was not mapped to block RAM (Error 276003)

Symptom in `output_files/Emulator.map.rpt`:

```
Info (276007): RAM logic "...|RamBank:g_bank.bank|mem" is uninferred due to asynchronous read logic  (RAM.sv:99, all 20 banks)
Error (276003): Cannot convert all sets of registers into RAM megafunctions when creating nodes.
                The resulting number of registers remaining in design exceeds the number of registers in the device ...
```

Cause: the RTL read was synchronous, but both read registers in `RamBank` had logic between the array and the flop: the write-through multiplexer (`rd_q <= wr ? wr_data : mem[idx]`) on the main port and the invalid-address mask (`dbg_q <= dbg_ok ? mem[dbg_idx] : 0`) on the debug port. Quartus absorbs a read register into an M10K block only when the register is fed directly from `mem[...]`. Otherwise it treats the read as asynchronous and builds the memory from flip-flops: about 1.4 million of them, against about 30 000 ALMs in the 5CSEMA4.

Fix in `rtl/DekatronPC/RAM.sv` (`RamBank`), behaviour unchanged:

- main port: `rd_q <= mem[idx]` only on reads; a write stores the value in `wr_q` and sets `byp_q`, and the output is `byp_q ? wr_q : rd_q`. The output still holds the last touched cell, write-through included;
- debug port: `dbg_q <= mem[dbg_idx]` and `dbg_ok_q <= dbg_ok`, with the mask applied after the register.

Checked: Verilator `--lint-only -Wall` on DekatronPC and Emulator (clean), Icarus `ApLine`, `IpLine` (looptest.bfk), `DekatronPC` on helloworld.bfk and program.bfk, all pass. The Quartus rerun is still to be done.

The `Critical Warning (127005)` about `FirmwareLoader` (memory depth 1024 vs 650 words in the init file) is harmless: the rest of the ROM is filled with zeros.

## 6. CI (`.github/workflows/fpga.yml`)

| Trigger | What runs | Artifacts |
|---|---|---|
| pull request to `master` | `build_fpga.sh elab`: syntax, hierarchy, parameters | reports |
| push to `master`, manual run (`workflow_dispatch`) | `build_fpga.sh --rbf compile` | `Emulator.sof`, `Emulator.rbf`, reports and summaries (14 days) |

The workflow is separate from `docker-image.yml` and not a required check.

**Quartus source: community Docker image (owner decision, 2026-10-07).** The job uses `chriz2600/quartus-lite:23.1.1-1`: Ubuntu 22.04 with the full Quartus Prime Lite 23.1std.1 tar installed (all device families, about 6.3 GB compressed). It is pinned by digest (`sha256:50eac410…`), so a re-pushed tag cannot change the toolchain silently. Quartus is on `PATH` only in a login shell, so the job runs `bash -lc`. The image has no Python, so the runner generates the firmware hex files and the container runs `build_fpga.sh --no-fw`. The job frees disk space on the runner before pulling the image.

Why not the official installers: Quartus is not in any distro repository, and since the Intel/Altera split, scripted downloads fail. `downloads.intel.com` redirects to a 404 page, and `download.altera.com` answers `403 Access Denied` (checked 2026-10-07). A mirror would have to be non-public, because Intel's EULA does not allow redistribution.

Fallback if the image disappears or breaks: a self-hosted runner on the owner's server with Quartus installed (the owner's choice; to be decided again then). On a public repository a self-hosted runner must not run pull requests from forks.

The local Windows install is 23.1std.0; the CI image is 23.1std.1, which gives the same results for this flow as far as is known.

Status: written, not yet run on GitHub.

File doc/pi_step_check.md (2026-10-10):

# pi.bfk: step-by-step check of the RTL against the golden model

Date: 2026-10-08. RTL at `2f91d76` (with P3 prefetch), bfutils `651cb62`.
Requirements: REQ-GM-002, REQ-PERF-003, REQ-CNT-005 / OPEN-001, REQ-MEM-DATA-005.

## 1. Result

`rtl/programs/pi.bfk` runs to HALT on the full `DekatronPC` in Verilator and
matches the golden model `dpcrun` on **every one of 221 386 retired
instructions** (`DekatronPC_tb.cpp -s`): IRET, IP (prefetch-aware), AP,
Data counter (`tx_data_bcd`), LoopCount and terminal output. Exit code 0:

```
VDekatronPC Done. state.CPU_CLK_UNHALTED = 3171964, IRET=221386
  Clk        3171964 cycles,    144.567 kHz simulated (slowdown 6.9x)
  IRET        221386 insns,    10090.0 insn/s
PASS: RTL matches the model, output "3.141
"
```

Wall time 22 s; the Verilator build took about 1 min.

## 2. Why this counts as proof

1. **Every step compared, by the testbench.** `compareStates()` runs after each
   retire. Any difference ends the run with a non-zero exit code.
2. **The step log re-checked separately.** A short script read all 221 386
   lines of the log and compared both columns again (RTL, model). It found 0
   mismatches. On 161 251 steps IP is model IP + 1: that's the P3 prefetch,
   which the testbench accepts by design. The last step's status is `Halted`.
3. **A third reference, independent of dpcrun.** A plain Python Brainfuck
   interpreter (8-bit cells, unbounded tape) prints the same `'3.141\n'`.
   It executes 198 594 BF operations (the same figure as TRS §4.4), with 17 076
   backward jumps and 5 715 forward skips. The machine's IRET reconciles
   exactly: 198 594 + 17 076 + 5 715 + 1 (HALT) = 221 386. The machine stops
   a loop scan on the matching bracket and then executes that bracket, so it
   costs one extra retire per jump.
4. **Output is correct.** π = 3.14159…; the program prints 4 digits, `3.141`.

## 3. What the run covers

- 221 386 instructions and about 3.17 M clk cycles. 55 723 memory reads and
  43 354 writes (dpcrun count, lazy reads, REQ-APV2-001).
- **AP wrap below zero.** The 6th instruction is `<` from cell 0. The program
  uses cell −1 as a scratch cell and crosses the 0 ↔ top boundary 19 times.
  It touches 66 cells.
- 6 COUT, no CIN.
- Loop scans with up to 11 levels of nesting (TRS §4.4). **Gap:** retires
  happen only after a scan finishes, so the compare always sees
  `LoopCount = 0`. The counter's values *during* the scan are not checked
  against the model here. IpLine_tb covers them.

## 4. Finding: AP limit in RTL vs model (OPEN-001)

The first run failed at instruction 6: `FATAL: ApAddress 99999 != model 29999`.

- RTL: in `ApLine.sv` the AP counter is a `DekatronCounter` with
  `TOP_LIMIT_MODE = 0`. The `AP_TOP_VALUE = 29999` parameter is declared but
  not connected, so AP wraps 0 ↔ 99999. The data `Ram` uses
  `D_NUM = AP_DEKATRON_NUM`, which gives 100 000 cells. The owner confirmed
  that the RTL now works with 100k data RAM.
- dpcrun: `Config::apTop` defaults to `AP_TOP_BF = 29999`.

The program's result doesn't depend on the limit: cell −1 is just a spare
cell. `dpcrun -a 99999` gives the same output and instruction count. The
testbench now builds the model with `apTop = 99999`, as in the RTL, and
`-a <top>` overrides it. OPEN-001 itself is still open: it decides whether
AP stays at 99999 or gets a 29999 top limit back. If it goes to 29999,
connect `AP_TOP_VALUE` with `TOP_LIMIT_MODE = 1` in ApLine and run the tb
with `-a 29999`.

## 5. Testbench changes (`rtl/tests/DekatronPC.sv/DekatronPC_tb.cpp`)

- `-n`: no VCD dump. A full trace of pi would be tens of GB. The default
  (trace on) is unchanged for `run_tests.sh`.
- `-a <top>`: the model's AP limit, default 99999 to match the RTL.

## 6. Reproduce

```
cd rtl/run
g++ -c ../../bfutils/dpcrun/dpcrun.cpp -o dpcrun.o && ar rcs libdpcrun.a dpcrun.o
python3 generate_rom.py -f ../programs/pi.bfk -o ../firmware.hex --hex
verilator -Wall --trace -DSIM_TRACE --top DekatronPC --cc $(cat ../DekatronPC/DPC.files) \
  "-GEN_EMULATOR=1'b1" ../libdpcrun.a -CFLAGS -I$(realpath ../../bfutils/dpcrun) \
  -DEMULATOR=1 -DIPMEMFILE --timescale 1us/1ns rules.vlt \
  --exe ../tests/DekatronPC.sv/DekatronPC_tb.cpp --Mdir obj_pi
make -j8 -C obj_pi -f VDekatronPC.mk VDekatronPC
./obj_pi/VDekatronPC -f ../programs/pi.bfk -s -n </dev/null 2>pi.steps.log
```

The same `obj_pi` binary runs any program: the program is loaded over
`InsnIn` at run time.

`run_tests.sh -t` runs pi too: `veremul` takes extra testbench flags as its
third argument, and pi gets `-n`. The step log is `rtl/run/pi.bfk.steps.log`.

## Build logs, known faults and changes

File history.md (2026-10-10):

- Filled AGENTS.md §1–9 from DekatronPC_TRS_v0_7.md (architecture, ISA, RTL rules, repo map, build/test, open decisions, priorities) and adapted the working rules in §0 to this project; found that insnValues.sv is stale compared with MachineCtrl.sv.
- Added github.com/radiolok/bfutils (the BrainfuckPC C++ model, including dpcrun) as the bfutils/ submodule and documented it in AGENTS.md §6/§9 as the golden-model upstream.
- Moved the CppMachine step model (dpcrun.cpp/.h) from rtl/tests/DekatronPC.sv into the bfutils submodule (local branch dpcrun-cppmachine) and pointed rtl/run/run_tests.sh at bfutils/dpcrun.
- Analysed the bfutils submodule (built all tools with g++, test.sh passes) and rewrote bfutils/README.md: tool status, bfpp pipeline/options, 16-bit opcode encoding, real image header layout, bfrun/dpcrun usage, dpcrun as the DekatronPC golden-model library, known issues.
- Rewrote the bfutils/dpcrun golden model for the full ISA (Debug/BF, MemLock with lazy read, SOT/EOT, resets, loop overflow, boot ROM), mirroring the RTL as-is. Added 53 unit tests with a GitHub Actions workflow in bfutils, ported DekatronPC_tb.cpp (not built), set REQ-GM-001/003/004 to Done [v0.8] and reopened OPEN-017 (COUT never issues AP_COUT), saved doc/dpcrun_golden_model.md.
- Moved the TRS to the repo root as TRS.md (v0.9: merged the repo v0.8 golden-model draft with the external v0.8/v0.9 — memory synthesis, assertions, counter widths fixed on Brainfuck-100), added SCHEMES.md with 14 SVG block diagrams in img/schemes/, rewrote README.md, put the Brainfuck-100 set into bfutils/programs/bf100 and updated AGENTS.md.
- Fixed the synt CI job: run_tests.sh -s passed InsnDecoder.json to dpc_stat.py, but the script synthesises MachineCtrl now, so the tube count read a missing file.
- Fixed the sim CI job: veremul passed -GEN_EMULATOR=1 (a 32-bit constant) to a bit parameter, which Verilator -Wall rejects as WIDTHTRUNC; now 1'b1.
- UVM regression: fixed test_bcd_to_bin (BcdToBin.sv) and the test_dek_counter source list for the new dekatron stack (drive soft_rst/hard_rst); failed targets now print a log tail and a GitHub ::error annotation.
- Rewrote the pulse_sender, ram and ip_memory cocotb tests for the current Valid/Ready interfaces (they still drove the pre-v0.6 ports) and added Impulse.sv to the dek_counter build.
- dek_counter test: zero the tubes with a soft_rst pulse before each test (rst_n never moves a discharge), skip the operand-latching test (the RTL contract is that the master holds operands until ready); the regression annotation now lists every assertion.
- Recorded the owner decision that DekatronCounter does not latch operands (saves tubes): dec/set/set_zero until the handshake, in until ready; REQ-CNT-V2-004 rewritten, RTL comments fixed, the latching test removed.
- Put the block-diagram generator into tools/schemes (build.py, sheets, lib, export to SCHEMES.md and img/schemes/*.svg, README); regenerated output is byte-identical apart from the SCHEMES.md header/footer.
- Removed the dekatron Valid signal (DekatronModule.Valid/OR10_X7, DekatronCounter.out_valid/settled_q); ready now comes from known durations, resets start writeTimer (ST_RST), and the default phase split changed 3/4/3 → 3/3/4 because the fall landed exactly on the next clk edge; TRS v0.10, report doc/dekatron_valid_removal.md.
- Resolved the follow-ups: TOP_VALUE default follows D_NUM (WIDTHTRUNC gone with LOOP_DEKATRON_NUM = 2, REQ-CNT-002 Done), redrew sheets 1–5 and 7 in tools/schemes for the Valid removal and the 3/3/4 split, and cleaned stash conflict markers from AGENTS.md and history.md.
- Analysed the DekatronCounter latch flops (zeroes_q/nines_q/tops_q/primed_q) and wrote a reduction plan, 49 → 24 flops across the four counters, with reasons why the carry/borrow and Data rollover flops must stay; report doc/dekatron_counter_flop_reduction.md (no RTL changed).
- Implemented the DekatronCounter flop reduction (49 → 24): primed_q folded into ST_RST, tops_q dropped, carry flags trimmed to D-1 bits without reset, zero/at_top combinational, Data rollover keeps zero_q/at_top_q; IpLine now catches loop overflow before the step via at_top; Counter_tb and a D_NUM=2 bench pass on Icarus, TRS/DekatronCounter.md/sheet 3 updated.
- Fixed the dpcrun golden model loop overflow: LOOP_SIZE 1000 → 100 (LOOP_DEKATRON_NUM = 2) and overflow caught before the increment with the counter left at 99, matching IpLine; tests updated/added (54 pass), doc/dpcrun_golden_model.md updated.
- Set up cocotb 2.1/pyuvm in ~/.venvs/dekatronpc and ran tb `make regression` (34/34 pass); fixed UART RX/loopback and OneShot tests that passed without checking, fixed the summary grouping, and listed coverage gaps (no ApLine/IpLine/MachineCtrl tests, pyuvm unused, MS6205 still soft) in doc/uvm_tb_check.md.
- Analysed the tube synthesis report (2138.5 tubes, 69 % FSM glue): an area-oriented ABC script (&deepsyn) gives 1817.5 with no RTL change, and a scratch ApLine rewrite (Moore strobes, merged OP/WAIT states, no rx_q) gives −174 more; the path to ≤ 1500 and owner questions are in doc/tube_count_reduction.md (no RTL or flow changed).
- Fixed the synthesis flow per owner decisions: area ABC script (&deepsyn -J 50) with an equiv_opt proof, QN pins on triggers plus rtl/run/qn_absorb.py to absorb inverters; with the 7-tube trigger the three blocks are 2336.5 tubes (old flow 2636); budget 1500 for the whole machine, Q̄ and RX-handshake decisions recorded as REQ-MOD-009/010 and REQ-UART-008.
- Added the RX Valid/Ready handshake (REQ-UART-008): DekatronPC/MachineCtrl output rx_rdy at the end of CIN, ApLine dropped the rx_q register (ApLine 989 → 874 tubes, total 2242), and the Emulator got a receive buffer; TRS Appendix B and the schemes updated; Icarus tests and the cocotb regression (34/34) pass; details in doc/tube_count_reduction.md §9.
- Rewrote the ApLine FSM per doc/tube_count_reduction.md §4 (REQ-APV2-007): 6 states instead of 9, Moore strobes gated by all-slaves-ready, mem_rd_valid unused; ApLine 874 → 719 tubes (three blocks 2087), ApLine_tb extended (STORE, CLRML, CLRA flush, 255↔0, memory access counts, handshake monitor) and passing, sheet 5 redrawn, report in §10.
- Rewrote the IpLine FSM per doc/tube_count_reduction.md §4 (R1, REQ-IPV2-007): merged OP/WAIT pairs, Moore strobes, dir_q instead of ip_dec/scan_dec_q, insn_q written to memory on load; the new IpLine_tb (Ram-style memory, load, random-scan reference model, overflow, CLRI, halt) passes and showed that the old FSM returned the previous fetch's opcode; IpLine 902 → 722 tubes (three blocks 1948), sheet 4 redrawn, report in §11.
- Rewrote MachineCtrl per tube_count_reduction §4/R2 (Moore strobes, op codes decoded from `insn`, 15 → 10 states, 25 → 9 flops, 512 → 284.5 tubes) and fixed the loop-overflow halt override (REQ-CTLV2-005); new MachineCtrl_tb, helloworld compared old vs new in DekatronPC_tb, report in doc/tube_count_reduction.md §12, TRS REQ-CTLV2-010, sheet 6 redrawn.
- COUT now always prints the Data counter (OPEN-017, owner decision): ApLine dropped the tx mux and AP_COUT loads the cell when MemLock is off, MachineCtrl issues AP_COUT before tx_vld; helloworld through the bootloader prints "Hello World!" in Icarus, ApLine 714 → 679.5 tubes, report in doc/tube_count_reduction.md §13; dpcrun's txData() still needs the matching change.
- Brought the dpcrun golden model (bfutils) in line with the RTL COUT change: COUT without MemLock loads the cell into the data counter, txData() returns the counter; new unit test cout_loads_cell_into_counter, 55 tests pass; docs and TRS OPEN-017 updated.
- Added rtl/tests/SimClockStats.h and wired it into the Verilator testbenches (DekatronPC_tb, Emulator_tb): at the end of a run they print simulated hsClk/Clk cycles, wall time, the simulated clock rate as a percentage of real 10 MHz / 1 MHz, the slowdown factor, and insn/s.
- Fixed the CI sim job: CI's Icarus 12 has no break/continue (IpLine_tb, MachineCtrl_tb rewritten); found and fixed checks that passed without checking (DekatronPC_tb.sv program scenario never ran and lost TX characters; DekatronPC_tb.cpp compared nothing). Now -s compares RTL with dpcrun step by step in CI, report doc/ci_sim_check.md.
- Implemented R3 and R4 from doc/tube_count_reduction.md: ApLine takes {insn_mode, insn} as its op, IpLine gets a 1-bit clr and drops insn_q (insn = program-memory register, EOT via a 1-bit insn_eot by owner decision, S_FETCH_W/S_WRITE removed); IpLine/ApLine/MachineCtrl tbs, DekatronPC Icarus sims and lint pass, three blocks 1675 → 1578 tubes (report §14, TRS REQ-APV2-008/REQ-IPV2-008, schemes redrawn).
- Brought doc/tube_count_reduction.md up to date: added a status table (2636 → 1578 tubes for IpLine+ApLine+MachineCtrl, step by step), marked R1–R4, R6, R7 done with measured Δ, R8/R9 rejected, R5/R11 open, closed the §2 findings and §7 questions, and replaced the old ≤ 1500 plan with where it stands (78 over budget on three blocks alone); TRS REQ-MOD-009 note updated to 1578.
- Owner lowered the tube budget for the whole machine from 1500 to 1200: updated TRS REQ-MOD-009, the v0.10 changelog and §22 (new item 10), and the goal in doc/tube_count_reduction.md (three blocks are 1578, 378 over).
- Added relay logic for panel switches (REQ-MOD-011): RELAY_2CO cell (0 tubes) and keep_hierarchy RelayMux/RelayEn in rtl/Logic/Relay.sv; MachineCtrl's bell switches and RunOnSoft/HardRst select moved to 5 relays (EchoMode, SoftRstOnEOT kept on tubes, where relays saved nothing over 7 ABC seeds), dpc_stat.py reports relays, synthesis 1595.5 tubes + 5 relays, report doc/tube_count_reduction.md §15.
- Added netlist simulation: rtl/run/synth_sim.sh runs the Icarus RTL tests on Yosys netlists (synt_dpc.tcl -p/-bb, tube, timing models and memory as RTL black boxes), vtube_cells.v brought in line with the liberty, CI job synth_sim (continue-on-error); 5 block tests pass, DekatronPC times out, report doc/synth_sim.md, TRS REQ-VER-025 In Progress.
- Owner confirmed OneShot/Impulse are special tube circuits: they stay black boxes in netlist simulation and outside the ABC tube count (doc/synth_sim.md, TRS v0.10 changelog, AGENTS.md §7).
- Fixed the DekatronPC netlist simulation failure: RamGroup.digit_q had no power-up value, so ApLine's not-yet-valid data_zero was X and the ABC netlist (unlike RTL) carried it into IpLine; DekatronPC_tb caught a zero-width IsHalted decode pulse with async waits, now sampled on negedge Clk. All synth_sim runs pass; analysis in doc/synth_sim.md §4.
- CI job synth_sim passed on Icarus 12, so continue-on-error was removed: netlist simulation is now a required check (workflow, doc/synth_sim.md §5, TRS REQ-VER-025, AGENTS.md).
- Added rtl/run/build_fpga.sh, a command-line Quartus build of the Emulator bitstream (project generated from the simulator file lists, Windows Quartus usable from WSL, JTAG programming, .rbf); Quartus elaboration passes after raising VERILOG_CONSTANT_LOOP_LIMIT for RamBank, full compile not yet run; report doc/fpga_build.md, AGENTS.md OPEN-015 entries brought in line with TRS v0.8.
- Diagnosed the build_fpga.sh syn failure (Error 276003: RamBank read registers had a write-through mux and a dbg mask in front of them, so Quartus built ~1.4M flops instead of M10K); moved both after the register in RAM.sv, lint and Icarus ApLine/IpLine/DekatronPC tests pass, Quartus rerun pending; doc/fpga_build.md §5.
- Added the FPGA CI workflow .github/workflows/fpga.yml (PR: Quartus elaboration; push to master/manual: full compile with .sof/.rbf artifacts) on the community image chriz2600/quartus-lite:23.1.1-1 pinned by digest, since Altera now blocks scripted installer downloads; fallback is a self-hosted runner; doc/fpga_build.md §6, AGENTS.md §7.
- Reviewed the test stand power supply schematic (sch/stand/stand, KiCad 10 ERC/netlist/DRC + manual analysis): ERC is clean apart from PWR_FLAGs, but the TL494 converters have inverted opto feedback, a TL431 over its 37 V rating, an unworkable 12 V aux supply and oversized snubbers, and the 200 V version tops out at 154 V; report doc/stand_psu_schematic_review.md.
- Re-checked the stand PSU after the owner's fixes (sch/stand moved up one level): C1 opto polarity, C2 Q1 to the TL431 cathode, C3 18 V zener are correct; C5 is still a dv/dt snubber (R across the diode, ~19 W), and C4 got a proposal (NPN/PNP gate buffer, ~30 mA aux budget); doc/stand_psu_schematic_review.md §6.
- Second re-check of the stand PSU: C4 (BC337/BC327 gate buffers) and C5 (shared RCD clamp to +Vbus) are fixed, M1/M5 accepted, M4 closed with the RMS inputs (136/80/56 V, 24 V); remaining: R8 range (M2), open-pot behaviour (M3), D5 zener power, R22 2 W in the 200v version, R1 value, EL33 footprint link; doc/stand_psu_schematic_review.md §7.
- Third re-check of the stand PSU: M2 nearly closed (R8 per version, but 120v/80v need 1.0k/0.75k to reach nominal), M3 closed (pot is parallel to R58, open pot saturates at ≈30 V); R1 now set, but at 17–20 mA it is short of the ~30 mA full-duty 12 V budget, so R20/R21 → 4.7k suggested; heater and 500 V supplies recorded as off-sheet; doc/stand_psu_schematic_review.md §8.
- Profiled helloworld.bfk on the RTL (Icarus FST + wavepeek, new rtl/run/cycle_profile.py): 401 instructions in 5540 cycles (CPI 13.8), with 28% in MachineCtrl handshake states, 21% in 4-cycle loop-scan steps and 10% in the Data counter write window after lazy reads; candidate speedups P1–P6 in doc/cycle_profile_helloworld.md, REQ-PERF-001/002 notes updated.
- Implemented P3 prefetch (REQ-PERF-003): MachineCtrl fetches the next opcode together with every ApLine op except TEST/CIN, latches the current one in op_q (ApLine gets ap_op), and IpLine skips the halt step on ip_ahead; helloworld 5540 → 4184 cycles, MachineCtrl +70 tubes; testbenches, profiler, TRS, AGENTS.md and SCHEMES updated, doc/prefetch_p3.md.
- Ran pi.bfk on the full DekatronPC in Verilator with step-by-step dpcrun compare: all 221 386 steps match and the output is `3.141` after the model was built with AP limit 99999 like the RTL (first run diverged at `<` from cell 0); added `-n` (no VCD) and `-a` (model AP limit) to DekatronPC_tb.cpp, saved doc/pi_step_check.md; pi now runs in run_tests.sh -t.
- Added DekatronTubeDelay, a clockless dekatron model (inertial #N delays, no hsClk; `define DEKATRON_DELAY_MODEL`), with run_tests.sh -d / synth_sim.sh -d (new synt_dpc.tcl -D, synth_sim test Pi) and CI jobs sim_delay/synth_sim_delay; all Icarus tests and pi.bfk pass on RTL and netlist (also on Icarus 12), DekatronPC_tb now runs a real 10 MHz hsClk; REQ-DEK-010 In Progress, doc/dekatron_delay_model.md.
- Switched Impulse, OneShot, DekatronPhaseGen and the DekatronPulseSender check to delays under the same DEKATRON_DELAY_MODEL define (`ifdef branches, no new modules or ports), so DekatronCounter runs with hsClk held at 0; Counter/Dekatron tests, all delay-mode RTL and netlist runs pass with unchanged timing (wavepeek), doc/dekatron_delay_model.md §8.
- Gave RstTimeRelay the same delay branch and cut hsClk inside DekatronPC under DEKATRON_DELAY_MODEL, so the whole machine runs with hsClk at 0; fixed a DekatronPC_tb race (blocking key assignments at the clock edge, which was the one-cycle RTL/netlist offset), after which both models and the netlist match cycle for cycle; doc/dekatron_delay_model.md §9.
- Added tube cell delays to netlist simulation: specify blocks in vtube_cells.v, rtl/vtube/vtube_timing.json (150 ns per arc, trigger setup/hold 150/150), rtl/run/vtube_sdf.py (per-module SDF, works around Icarus not resolving escaped names), a setup/hold checker and synth_sim.sh -t/-c; at Clk 10 us Dekatron passes but DekatronCounter never counts, because the phase windows close before the step command arrives, so no clock period works until the phase alignment is fixed; doc/vtube_sdf_timing.md.
- Removed `dirty_q` from ApLine and `m_dirty` from dpcrun by owner decision: MemLock is now the only ownership flag, which also fixes the lock surviving an AP step after STORE (REQ-APV2-003, REQ-ML-005). ApLine_tb and dpcrun tests pass, and pi.bfk keeps the same access count; saved doc/memlock_single_flag.md.
- Second tube-reduction pass (analysis only, RTL unchanged): found that the old FSM-encoding test was a no-op, measured binary `fsm_encoding` in DekatronCounter/IpLine/ApLine at −219 tubes (three blocks ≈ 1656 → 1437, 3 seeds, netlist tests pass), and estimated diode codecs (REQ-AUTH-002, ≈ −160) and latched carry flags (≈ −75) as the path to ≈ 1200; doc/tube_count_reduction.md §17 with owner questions.
- Applied T1: binary `fsm_encoding` on the state registers of DekatronCounter, IpLine and ApLine; the three blocks go 1669.5 → 1450.5 tubes (64 triggers), equiv_opt proven, run_tests.sh -t/-d and synth_sim.sh/-d pass (-t fails as before at 1 µs); TRS REQ-MOD-009 and doc/tube_count_reduction.md §17.6 updated.
- T4–T6 by owner decision (T2 rejected, REQ-AUTH-002 now allows diodes only in rectifiers and ferrite memory; T3/T8 postponed; T7/T9 rejected): one DekatronPulseSender per counter with a new GUIDE_EN_J2 cell (one J2 tube) gating the guide buses in each decade (REQ-PULSE-007), a busy_q trigger instead of the FSM in the Loop and AP counters, and MachineCtrl state codes found by search; three blocks 1437 → 1362 tubes (mean of 3 seeds), all tests pass, schemes 2–3 redrawn, doc/tube_count_reduction.md §17.7.
- Corrected the guide gate per the owner: J2 is a pentode with two control grids, one per guide signal, so GUIDE_EN_J2 is now a single-guide cell (Y = G & EN) placed twice in each DekatronModule; three blocks 1362 → 1377 tubes (+15, 30 cells), TRS/AGENTS/schemes and doc/tube_count_reduction.md §17.7 updated.
- Reviewed the webui P&R tool (PR #28) against this branch (hierarchical synt_dpc.tcl netlists, rtl/vtube liberty): its Verilog parser silently merges nets across modules, and the app crashes on start. Recorded the owner decisions Q1–Q11 as REQ-PR-011..019 in TRS §17, plus the RTL task of wire structures per inter-block HD-68 connector (§22 item 12). Report: doc/webui_review.md on branch webui.
- Added the web simulator in web/: dpcrun ported to JavaScript (trace-identical on 6 programs), console page with dekatrons, panel keys and rotary switches, SOT/EOT loading through the SIMPLEBOOT ROM, Brainfuck-100 selector, RU/EN; CI web.yml and GitHub Pages pages.yml; found that the halt step skips a pending loop scan after a taken bracket (doc/web_simulator.md).

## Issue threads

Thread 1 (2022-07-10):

Create correct dekatron model

radiolok, 2022-07-10:
Создать более корректную модель декатрона, где у него есть 30 защелок подключенных по кругу, где одна защелка сбрасывает все остальные. Где появление на входах Р1 и Р2 в нужной последовательности перетаскивает разряд по или против часовой стрелки.
Где появление управляющего сигнала на одном из катодов приводит к перетаскиванию сигнала с текущего катода на результирующий.
В идеале у декатрона должен быть вход типа inout с pullup -

логика переключения декатрона
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

Closed 2023-06-08.

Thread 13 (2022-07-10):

Dekatron writing circuit

radiolok, 2022-07-10:
Разработать и спаять схему записи в декатрон на экспериментальной ячейке.
в том числе схема декодера 8-4-2-1 в двоичный формат со сдвигом уровней логических до нужных
схема усилителей и схема управляющих сигналов

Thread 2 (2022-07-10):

Create generated up-down counter based on dekatron model

radiolok, 2022-07-10:
На базе более корректной модели декатрона по #1 сделать генерируемый реверсивный счетчик

Параметры
1. чтение (добавляется схема чтения)
2. запись (добавляется схема записи)
3. разрядность (количество декатронов в цепочке)

Входы:
1. клок
4. резет
5. число для записи в формате 8-4-2-1
6. флаг записи
7. флаг инкремента
8. флаг декремента
9. строб Request

Выходы:
1. Нуль (все декатроны в нуле)
2. Число для чтения в формате 8-4-2-1
3. Флаг Ready - горит когда не идет счет и  число на выходе валидно
4. Флаг Busy

Closed 2024-09-30.

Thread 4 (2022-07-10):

Create code for ApLine block

radiolok, 2022-07-10:
Блок кода, отвечающий за работу:

1. со счетчиком адреса,
2. памятью данных,
3. флагом захвата памяти данных,
4. счетчиком данных
5. Модулем вывода в терминал
6. Модулем чтения с терминала

Closed 2024-06-04.

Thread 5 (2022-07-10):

Create Instruction decoder state machine

radiolok, 2022-07-10:
Разработать блок декодера инструкций.
Входы блока - клок, резет, 4+1 битовый код инструкции
4 бита - непосредственно номер инструкции из памяти программ
плюс 1 бит - текущий набор инструкций - Brainfuck ISA/maintance ISA

Выходы блока - сигналы управления блоками и модулями машины, как-то - чтение из памяти, запись в память, запуск счета и т.п.

По изначальное задумке, физическая реализация блока будет представлять собой набор модулей на 20-25 ламп, где каждый модуль отвечает за свою инструкцию, или свою уникальную стадию набора инструкций.
т.е. установив в машину один модуль, поддерживающий например инструкцию + - машина будет уметь выполнять только ее, добавляя в машину новый модуль - добавляем поддержку новых инструкций.

Возможно, этот вариант будет слишком сложным в реализации. Цель блока - иметь максимальную инкапсуляцию инструкции в модуле при минимальной сложности схемотехнического решения.

Closed 2024-10-02.

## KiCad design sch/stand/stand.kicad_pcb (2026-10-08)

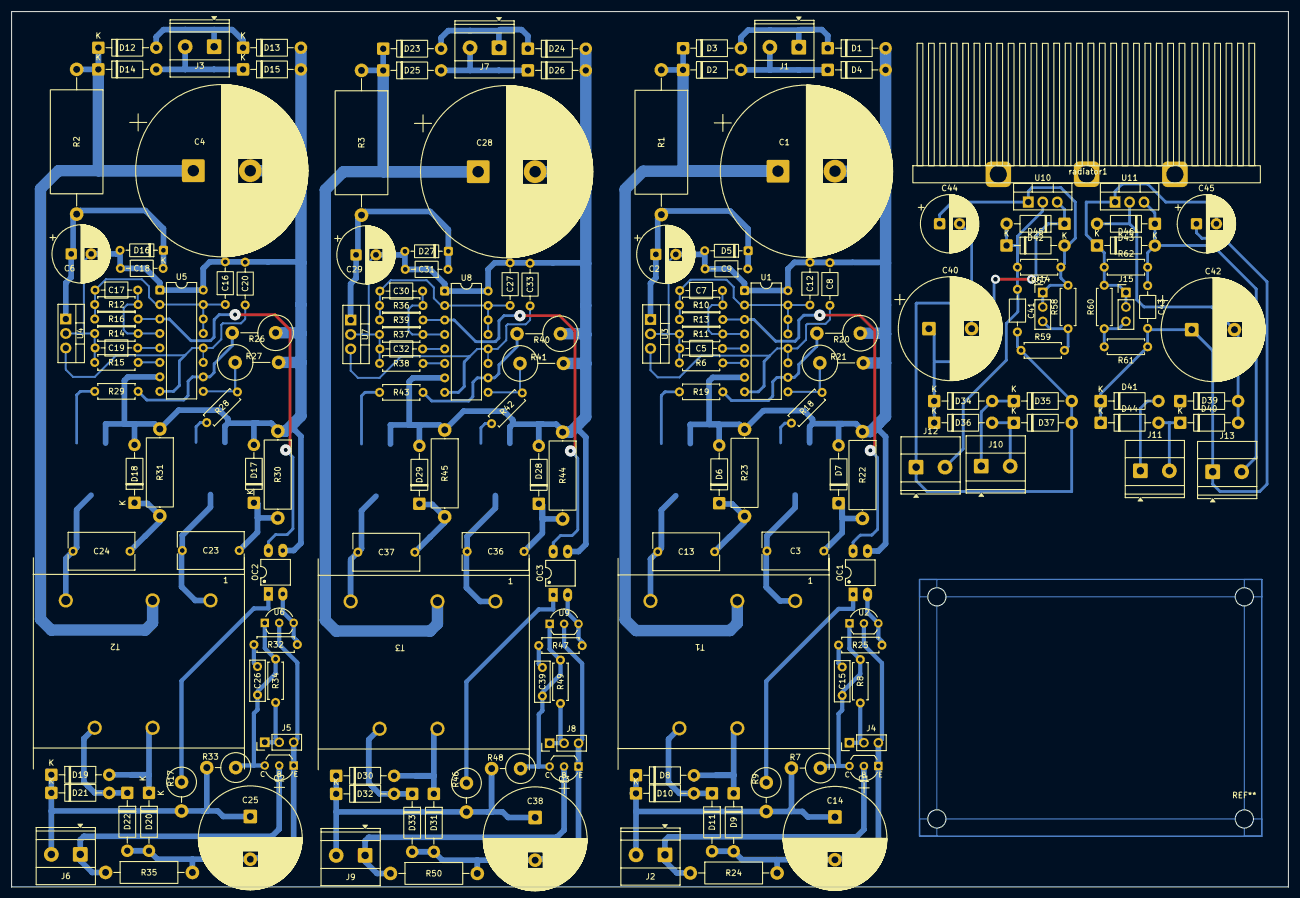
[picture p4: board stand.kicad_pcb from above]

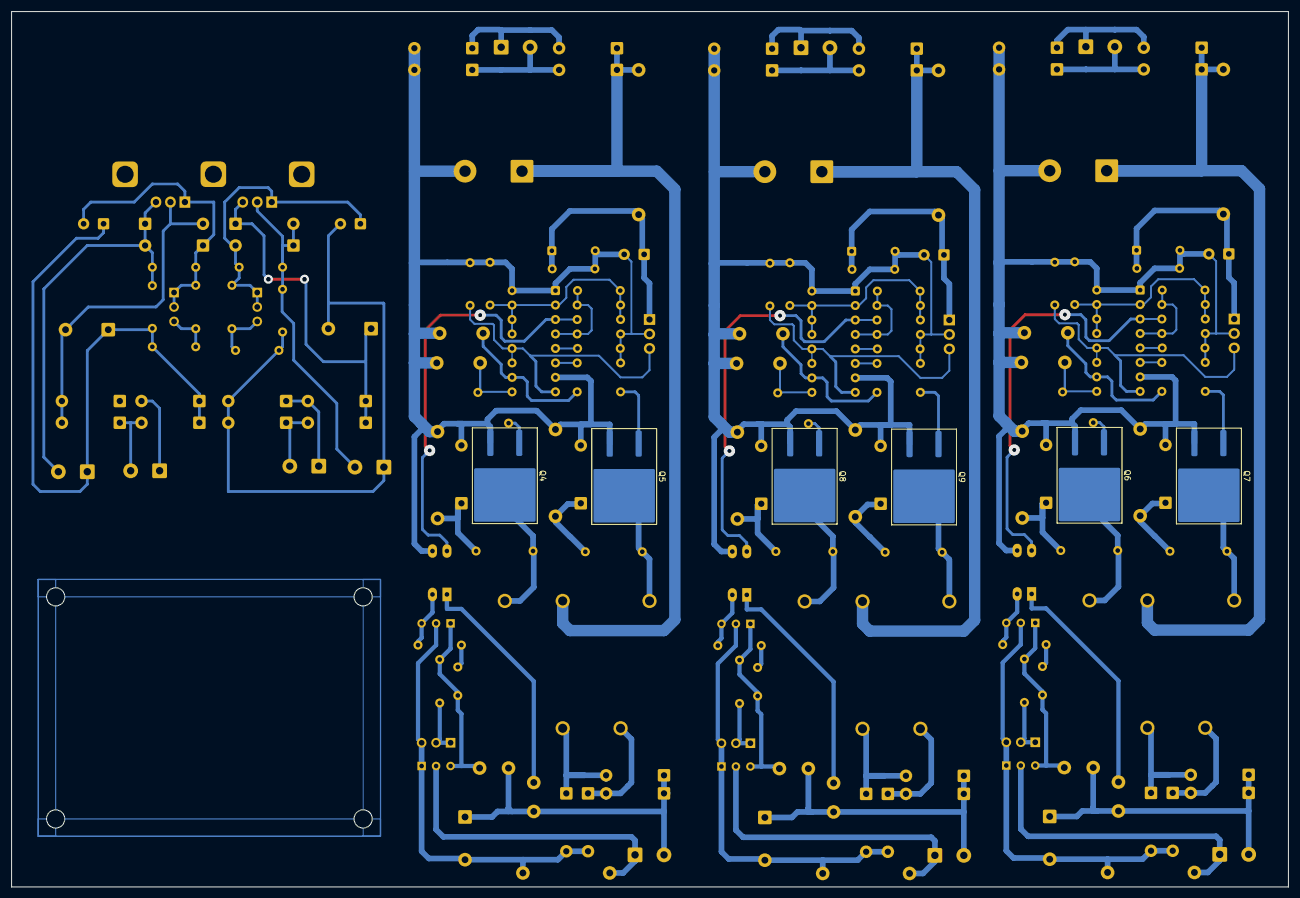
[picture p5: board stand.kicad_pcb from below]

Board: 2 copper layers, 224.2 x 153.7 mm, 180 parts (6 on the bottom side), 101 nets.

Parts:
C1, C4, C28: 330uF 315v; CP_Radial_D30.0mm_P10.00mm_SnapIn
C2, C6, C29: 10uF 160v; CP_Radial_D10.0mm_P3.50mm
C3, C13, C23, C24, C36, C37: 4.7nF 630v; C_Rect_L11.5mm_W6.4mm_P10.00mm_MKT
C5, C19, C32: 1.1nF; C_Axial_L3.8mm_D2.6mm_P7.50mm_Horizontal
C7, C8, C9, C12, C16, C17, C18, C20, C27, C30, C31, C33, C41, C43: 1uF; C_Axial_L3.8mm_D2.6mm_P7.50mm_Horizontal
C14, C25, C38: 82uF 315V; CP_Radial_D18.0mm_P7.50mm
C15, C26, C39: 10nF; C_Rect_L7.0mm_W2.5mm_P5.00mm
C40, C42: 2200uF 50v; CP_Radial_D18.0mm_P7.50mm
C44, C45: 10uF 50v; CP_Radial_D10.0mm_P3.50mm
D1, D2, D3, D4, D12, D13, D14, D15, D23, D24, D25, D26, D34, D35, D36, D37, D39, D40, D41, D42, D43, D44, D45, D46: 1N4007; D_DO-41_SOD81_P10.16mm_Horizontal
D5, D16, D27: 18v; D_DO-35_SOD27_P7.62mm_Horizontal
D6, D7, D8, D9, D10, D11, D17, D18, D19, D20, D21, D22, D28, D29, D30, D31, D32, D33: HER108; D_DO-41_SOD81_P10.16mm_Horizontal
J1, J3, J7, J10, J11: Vin; TerminalBlock_Phoenix_MKDS-1,5-2-5.08_1x02_P5.08mm_Horizont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
J2, J6, J9, J12, J13: Vout; TerminalBlock_Phoenix_MKDS-1,5-2-5.08_1x02_P5.08mm_Horizont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
J4, J5, J8, J14, J15: Voltage; PinHeader_1x03_P2.54mm_Vertical
OC1, OC2, OC3: PC817; DIP-4_W7.62mm_LongPads
Q1, Q2, Q3: 2N3904; TO-92_Inline_Wide_EBC
Q4, Q5, Q6, Q7, Q8, Q9: IRFBE30S; TO-263-2
R1, R2, R3: R; R_Axial_DIN0918_L18.0mm_D9.0mm_P25.40mm_Horizontal
R6, R10, R12, R15, R36, R38: 10k; R_Axial_DIN0207_L6.3mm_D2.5mm_P7.62mm_Horizontal
R7, R33, R48: 91k; R_Axial_DIN0516_L15.5mm_D5.0mm_P5.08mm_Vertical
R8, R34, R49: 1.5к; R_Axial_DIN0207_L6.3mm_D2.5mm_P7.62mm_Horizontal
R9, R17, R46: 18k; R_Axial_DIN0516_L15.5mm_D5.0mm_P5.08mm_Vertical
R11, R14, R37: 1k; R_Axial_DIN0207_L6.3mm_D2.5mm_P7.62mm_Horizontal
R13, R16, R39: 4.7k; R_Axial_DIN0207_L6.3mm_D2.5mm_P7.62mm_Horizontal
R18, R19, R28, R29, R42, R43: 10; R_Axial_DIN0207_L6.3mm_D2.5mm_P7.62mm_Horizontal
R20, R21, R26, R27, R40, R41: 68; R_Axial_DIN0617_L17.0mm_D6.0mm_P7.62mm_Vertical
R22, R23, R30, R31, R44, R45: 1k; R_Axial_DIN0414_L11.9mm_D4.5mm_P15.24mm_Horizontal
R24, R35, R50: 1; R_Axial_DIN0411_L9.9mm_D3.6mm_P15.24mm_Horizontal
R25, R32, R47: 100; R_Axial_DIN0207_L6.3mm_D2.5mm_P7.62mm_Horizontal
R57, R62: 220; R_Axial_DIN0207_L6.3mm_D2.5mm_P7.62mm_Horizontal
R58, R60: 12k; R_Axial_DIN0207_L6.3mm_D2.5mm_P7.62mm_Horizontal
R59, R61: 680; R_Axial_DIN0207_L6.3mm_D2.5mm_P7.62mm_Horizontal
T1, T2, T3: Transformer_SP_1S; EL33
U1, U5, U8: TL494; DIP-16_W7.62mm
U2, U6, U9: TL431LP; TO-92_Inline_Wide
U3, U4, U7: L7812ABV; TO-220-3_Vertical
U10: LM317AT; TO-220-3_Vertical
U11: LM337SP; TO-220-3_Vertical
radiator1: Радиатор

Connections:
unnamed: C15.1, R25.1
unnamed: C26.1, R32.1
unnamed: C39.1, R47.1
unnamed: C1.2, C2.2, C5.2, C8.2, C9.2, C12.2, D1.2 (A), D4.2 (A), D5.2 (A), D6.2 (A), D7.2 (A), OC1.3, Q4.3 (S), Q5.3 (S), R6.1, R11.1, R20.2, R21.1, R22.1, R23.1, U1.1 (1IN+), U1.7 (GND), U1.16 (2IN+), U3.2
unnamed: D1.1 (K), D3.2 (A), J1.1
unnamed: D2.2 (A), D4.1 (K), J1.2
unnamed: C1.1, D2.1 (K), D3.1 (K), R1.1, T1.2 (PM)
unnamed: C2.1, C9.1, D5.1 (K), R1.2, U3.1 (IN)
unnamed: C13.2, D6.1 (K), R23.2
unnamed: C3.2, D7.1 (K), R22.2
unnamed: D8.2 (A), D9.1 (K), T1.5 (S2)
unnamed: D10.2 (A), D11.1 (K), T1.4 (S1)
unnamed: C14.1, D8.1 (K), D10.1 (K), J2.2, R7.2, R9.2
unnamed: C14.2, D9.2 (A), D11.2 (A), J4.3, Q1.1 (E), R24.2, U2.2 (A)
unnamed: D12.2 (A), D13.1 (K), J3.1
unnamed: C4.1, D12.1 (K), D14.1 (K), R2.1, T2.2 (PM)
unnamed: C4.2, C6.2, C16.2, C18.2, C19.2, C20.2, D13.2 (A), D15.2 (A), D16.2 (A), D17.2 (A), D18.2 (A), OC2.3, Q6.3 (S), Q7.3 (S), R14.1, R15.1, R26.2, R27.1, R30.1, R31.1, U4.2, U5.1 (1IN+), U5.7 (GND), U5.16 (2IN+)
unnamed: D14.2 (A), D15.1 (K), J3.2
unnamed: C6.1, C18.1, D16.1 (K), R2.2, U4.1 (IN)
unnamed: C23.2, D17.1 (K), R30.2
unnamed: C24.2, D18.1 (K), R31.2
unnamed: D19.2 (A), D20.1 (K), T2.5 (S2)
unnamed: C25.1, D19.1 (K), D21.1 (K), J6.2, R17.2, R33.2
unnamed: C25.2, D20.2 (A), D22.2 (A), J5.3, Q2.1 (E), R35.2, U6.2 (A)
unnamed: D21.2 (A), D22.1 (K), T2.4 (S1)
unnamed: D23.2 (A), D24.1 (K), J7.1
unnamed: C28.1, D23.1 (K), D25.1 (K), R3.1, T3.2 (PM)
unnamed: C27.2, C28.2, C29.2, C31.2, C32.2, C33.2, D24.2 (A), D26.2 (A), D27.2 (A), D28.2 (A), D29.2 (A), OC3.3, Q8.3 (S), Q9.3 (S), R37.1, R38.1, R40.2, R41.1, R44.1, R45.1, U7.2, U8.1 (1IN+), U8.7 (GND), U8.16 (2IN+)
unnamed: D25.2 (A), D26.1 (K), J7.2
unnamed: C29.1, C31.1, D27.1 (K), R3.2, U7.1 (IN)
unnamed: C36.2, D28.1 (K), R44.2
unnamed: C37.2, D29.1 (K), R45.2
unnamed: D30.2 (A), D31.1 (K), T3.5 (S2)
unnamed: C38.1, D30.1 (K), D32.1 (K), J9.2, R46.2, R48.2
unnamed: C38.2, D31.2 (A), D33.2 (A), J8.3, Q3.1 (E), R50.2, U9.2 (A)
unnamed: D32.2 (A), D33.1 (K), T3.4 (S1)
unnamed: D34.2 (A), D35.1 (K), J10.1
unnamed: C40.1, D34.1 (K), D36.1 (K), D42.1 (K), U10.3 (IN)
unnamed: C40.2, C41.2, C44.2, D35.2 (A), D37.2 (A), J12.1, R59.1
unnamed: D36.2 (A), D37.1 (K), J10.2
unnamed: C42.2, D39.2 (A), D40.2 (A), D43.2 (A), U11.2 (IN)
unnamed: D39.1 (K), D41.2 (A), J11.1
unnamed: D40.1 (K), D44.2 (A), J11.2
unnamed: C42.1, C43.2, C45.1, D41.1 (K), D44.1 (K), J13.1, R61.1
unnamed: C41.1, D42.2 (A), D45.1 (K), J12.2, R57.2, U10.2 (OUT)
unnamed: C43.1, D43.1 (K), D46.2 (A), J13.2, R62.2, U11.3 (OUT)
unnamed: C44.1, D45.2 (A), J14.1, J14.2, R57.1, R58.2, U10.1
unnamed: C45.2, D46.1 (K), J15.1, J15.2, R60.2, R62.1, U11.1
unnamed: J2.1, Q1.2 (B), R24.1
unnamed: J4.1, J4.2, R8.1
unnamed: J5.1, J5.2, R34.1
unnamed: J6.1, Q2.2 (B), R35.1
unnamed: J8.1, J8.2, R49.1
unnamed: J9.1, Q3.2 (B), R50.1
unnamed: J14.3, R58.1, R59.2
unnamed: J15.3, R60.1, R61.2
unnamed: OC1.1, R9.1
unnamed: OC2.1, R17.1
unnamed: OC3.1, R46.1
unnamed: C15.2, Q1.3 (C), R7.1, R8.2, U2.1 (REF)
unnamed: C26.2, Q2.3 (C), R33.1, R34.2, U6.1 (REF)
unnamed: C39.2, Q3.3 (C), R48.1, R49.2, U9.1 (REF)
unnamed: C3.1, Q4.2 (D), T1.1 (PR1)
unnamed: Q4.1 (G), R18.1
unnamed: C13.1, Q5.2 (D), T1.3 (PR2)
unnamed: Q5.1 (G), R19.1
unnamed: C23.1, Q6.2 (D), T2.1 (PR1)
unnamed: Q6.1 (G), R28.1
unnamed: C24.1, Q7.2 (D), T2.3 (PR2)
unnamed: Q7.1 (G), R29.1
unnamed: C36.1, Q8.2 (D), T3.1 (PR1)
unnamed: Q8.1 (G), R42.1
unnamed: C37.1, Q9.2 (D), T3.3 (PR2)
unnamed: Q9.1 (G), R43.1
unnamed: C7.1, C12.1, R10.2, R13.2, U1.2 (1IN-), U1.13 (OUTCTRL), U1.14 (REF), U1.15 (2IN-)
unnamed: C8.1, U1.8 (C1), U1.11 (C2), U1.12 (VCC), U3.3 (OUT)
unnamed: C5.1, U1.5 (CT)
unnamed: C7.2, R10.1, R11.2, U1.4 (DTC)
unnamed: R18.2, R20.1, U1.9 (E1)
unnamed: R19.2, R21.2, U1.10 (E2)
unnamed: OC1.4, R13.1, U1.3 (FB)
unnamed: R6.2, U1.6 (RT)
unnamed: OC1.2, R25.2, U2.3 (K)
unnamed: C20.1, U4.3 (OUT), U5.8 (C1), U5.11 (C2), U5.12 (VCC)
unnamed: C16.1, C17.1, R12.2, R16.2, U5.2 (1IN-), U5.13 (OUTCTRL), U5.14 (REF), U5.15 (2IN-)
unnamed: C19.1, U5.5 (CT)
unnamed: C17.2, R12.1, R14.2, U5.4 (DTC)
unnamed: R26.1, R28.2, U5.9 (E1)
unnamed: R27.2, R29.2, U5.10 (E2)
unnamed: OC2.4, R16.1, U5.3 (FB)
unnamed: R15.2, U5.6 (RT)
unnamed: OC2.2, R32.2, U6.3 (K)
unnamed: C33.1, U7.3 (OUT), U8.8 (C1), U8.11 (C2), U8.12 (VCC)
unnamed: C27.1, C30.1, R36.2, R39.2, U8.2 (1IN-), U8.13 (OUTCTRL), U8.14 (REF), U8.15 (2IN-)
unnamed: C32.1, U8.5 (CT)
unnamed: C30.2, R36.1, R37.2, U8.4 (DTC)
unnamed: R40.1, R42.2, U8.9 (E1)
unnamed: R41.2, R43.2, U8.10 (E2)
unnamed: OC3.4, R39.1, U8.3 (FB)
unnamed: R38.2, U8.6 (RT)
unnamed: OC3.2, R47.2, U9.3 (K)

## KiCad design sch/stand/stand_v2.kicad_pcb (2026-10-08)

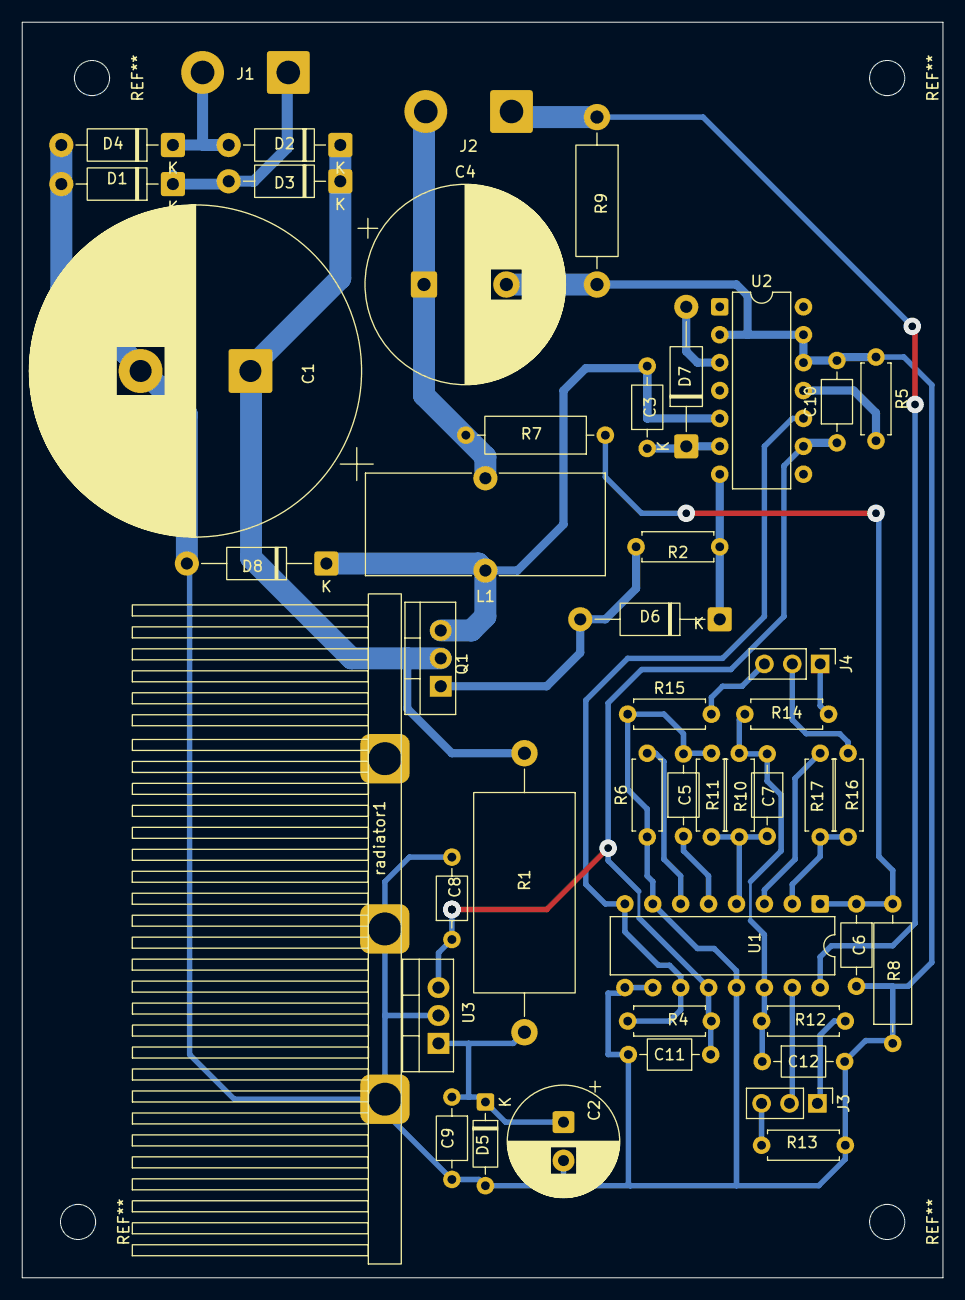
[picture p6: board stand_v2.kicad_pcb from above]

Board: 2 copper layers, 83.8 x 114.3 mm, 46 parts (0 on the bottom side), 28 nets.

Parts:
C1: C_Polarized; CP_Radial_D30.0mm_P10.00mm_SnapIn
C2: C_Polarized; CP_Radial_D10.0mm_P3.50mm
C3, C6, C7, C8, C9, C10, C11, C12: 1uF; C_Axial_L3.8mm_D2.6mm_P7.50mm_Horizontal
C4: C_Polarized; CP_Radial_D18.0mm_P7.50mm
C5: 2.2nF; C_Axial_L3.8mm_D2.6mm_P7.50mm_Horizontal
D1, D2, D3, D4: 1N4007; D_DO-41_SOD81_P10.16mm_Horizontal
D5: D_Zener; D_DO-35_SOD27_P7.62mm_Horizontal
D6, D7, D8: UF4007; D_DO-41_SOD81_P12.70mm_Horizontal
J1, J2: Conn_01x02_Socket; SolderWire-1.5sqmm_1x02_P7.8mm_D1.7mm_OD3.9mm
J3: Current; PinHeader_1x03_P2.54mm_Vertical
J4: Voltage; PinHeader_1x03_P2.54mm_Vertical
L1: L; L_Toroid_Vertical_L21.6mm_W9.1mm_P8.40mm_Bourns_5700
Q1: IRF840A; TO-220-3_Vertical
R1: R; R_Axial_DIN0918_L18.0mm_D9.0mm_P25.40mm_Horizontal
R2: 20; R_Axial_DIN0207_L6.3mm_D2.5mm_P7.62mm_Horizontal
R4, R11: 1k; R_Axial_DIN0207_L6.3mm_D2.5mm_P7.62mm_Horizontal
R5, R6, R10: 10k; R_Axial_DIN0207_L6.3mm_D2.5mm_P7.62mm_Horizontal
R7, R8: ?; R_Axial_DIN0309_L9.0mm_D3.2mm_P12.70mm_Horizontal
R9: 1; R_Axial_DIN0411_L9.9mm_D3.6mm_P15.24mm_Horizontal
R12, R13, R14, R15: ?; R_Axial_DIN0207_L6.3mm_D2.5mm_P7.62mm_Horizontal
R16: 510; R_Axial_DIN0207_L6.3mm_D2.5mm_P7.62mm_Horizontal
R17: 51k; R_Axial_DIN0207_L6.3mm_D2.5mm_P7.62mm_Horizontal
U1: TL494; DIP-16_W7.62mm
U2: IR2110; DIP-14_W7.62mm
U3: L7812ABV; TO-220-3_Vertical
radiator1: Радиатор

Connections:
+5V: C7.1, C12.1, R10.2, R12.2, R14.2, U1.14 (REF)
+12V: C8.1, C10.1, C11.1, R4.2, U1.12 (VCC), U2.9 (VDD), U3.3 (OUT)
+18V: C2.1, C9.1, D5.1 (K), R1.2, U3.1 (IN)
GND: C1.2, C2.2, C4.2, C5.2, C6.2, C8.2, C9.2, C10.2, C11.2, C12.2, D1.2 (A), D4.2 (A), D5.2 (A), D8.2 (A), R5.1, R6.1, R8.1, R9.2, R11.1, R13.1, R15.1, U1.7 (GND), U1.9 (E1), U1.10 (E2), U1.13 (OUTCTRL), U2.2 (COM), U2.12 (LIN), U2.13 (VSS), U3.2
unnamed: D1.1 (K), D3.2 (A), J1.1
unnamed: D2.2 (A), D4.1 (K), J1.2
unnamed: D6.2 (A), Q1.1 (G), R2.2
unnamed: D6.1 (K), R2.1, U2.7 (HO)
unnamed: D7.2 (A), U2.3 (VCC)
unnamed: C3.1, D7.1 (K), U2.6 (VB)
unnamed: C3.2, D8.1 (K), L1.1, Q1.3 (S), U2.5 (VS)
unnamed: J2.1, R9.1, U1.16 (2IN+)
unnamed: C4.1, J2.2, L1.2, R7.2
unnamed: J3.1, R12.1
unnamed: J3.2, U1.15 (2IN-)
unnamed: J3.3, R13.2
unnamed: J4.1, R14.1
unnamed: J4.2, R16.2
unnamed: J4.3, R15.2
unnamed: C6.1, R7.1, R8.2, U1.1 (1IN+)
unnamed: R16.1, R17.2, U1.2 (1IN-)
unnamed: R4.1, U1.8 (C1), U1.11 (C2), U2.10 (HIN)
unnamed: C5.1, U1.5 (CT)
unnamed: C7.2, R10.1, R11.2, U1.4 (DTC)
unnamed: R17.1, U1.3 (FB)
unnamed: R6.2, U1.6 (RT)
unnamed: R5.2, U2.11 (SD)
VCC: C1.1, D2.1 (K), D3.1 (K), Q1.2 (D), R1.1

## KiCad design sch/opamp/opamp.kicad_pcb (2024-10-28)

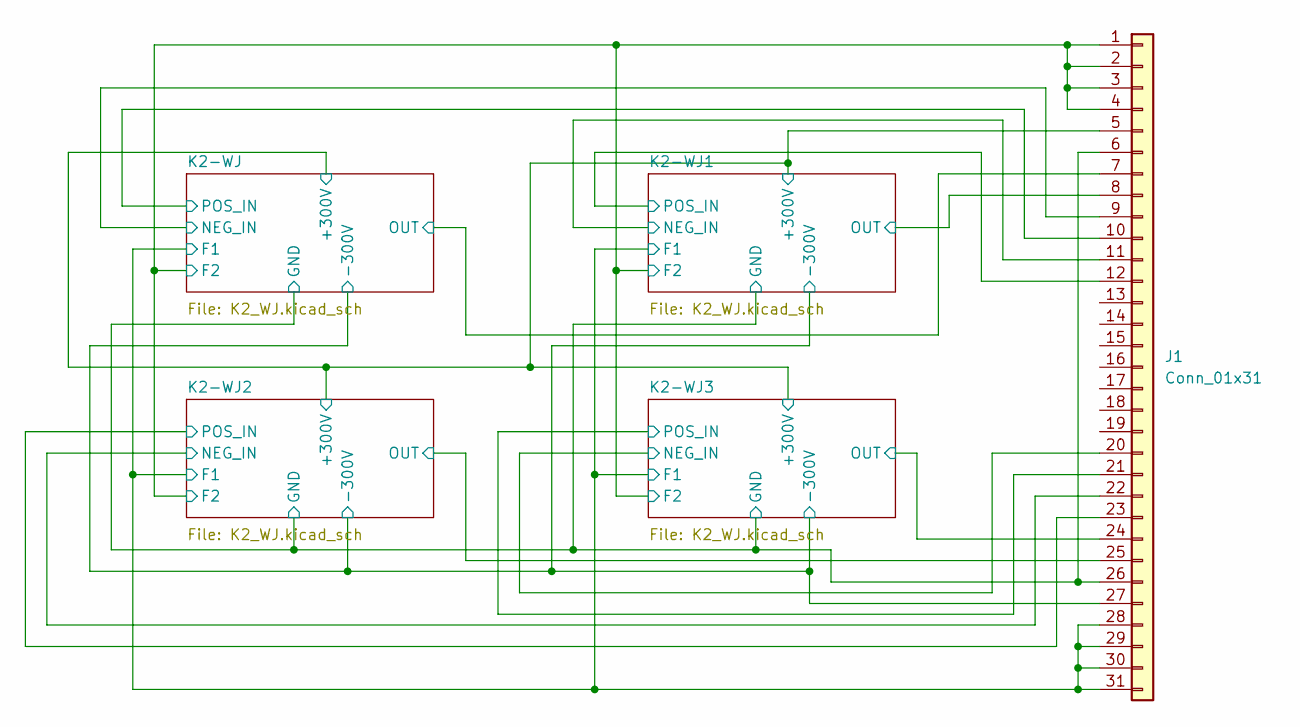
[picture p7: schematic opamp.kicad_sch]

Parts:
J1: Conn_01x31; ГРПМШ1-31

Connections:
/K2-WJ1/NEG_IN: J1.11; also elsewhere on the board
/K2-WJ1/OUT: J1.8; also elsewhere on the board
/K2-WJ1/POS_IN: J1.12; also elsewhere on the board
/K2-WJ2/NEG_IN: J1.22; also elsewhere on the board
/K2-WJ2/OUT: J1.25; also elsewhere on the board
/K2-WJ2/POS_IN: J1.23; also elsewhere on the board
/K2-WJ3/NEG_IN: J1.20; also elsewhere on the board
/K2-WJ3/OUT: J1.24; also elsewhere on the board
/K2-WJ3/POS_IN: J1.21; also elsewhere on the board
/K2-WJ/+300V: J1.5; also elsewhere on the board
/K2-WJ/-300V: J1.27; also elsewhere on the board
/K2-WJ/F1: J1.28, J1.29, J1.30, J1.31; also elsewhere on the board
/K2-WJ/F2: J1.1, J1.2, J1.3, J1.4; also elsewhere on the board
/K2-WJ/GND: J1.6, J1.26; also elsewhere on the board
/K2-WJ/NEG_IN: J1.9; also elsewhere on the board
/K2-WJ/OUT: J1.7; also elsewhere on the board
/K2-WJ/POS_IN: J1.10; also elsewhere on the board

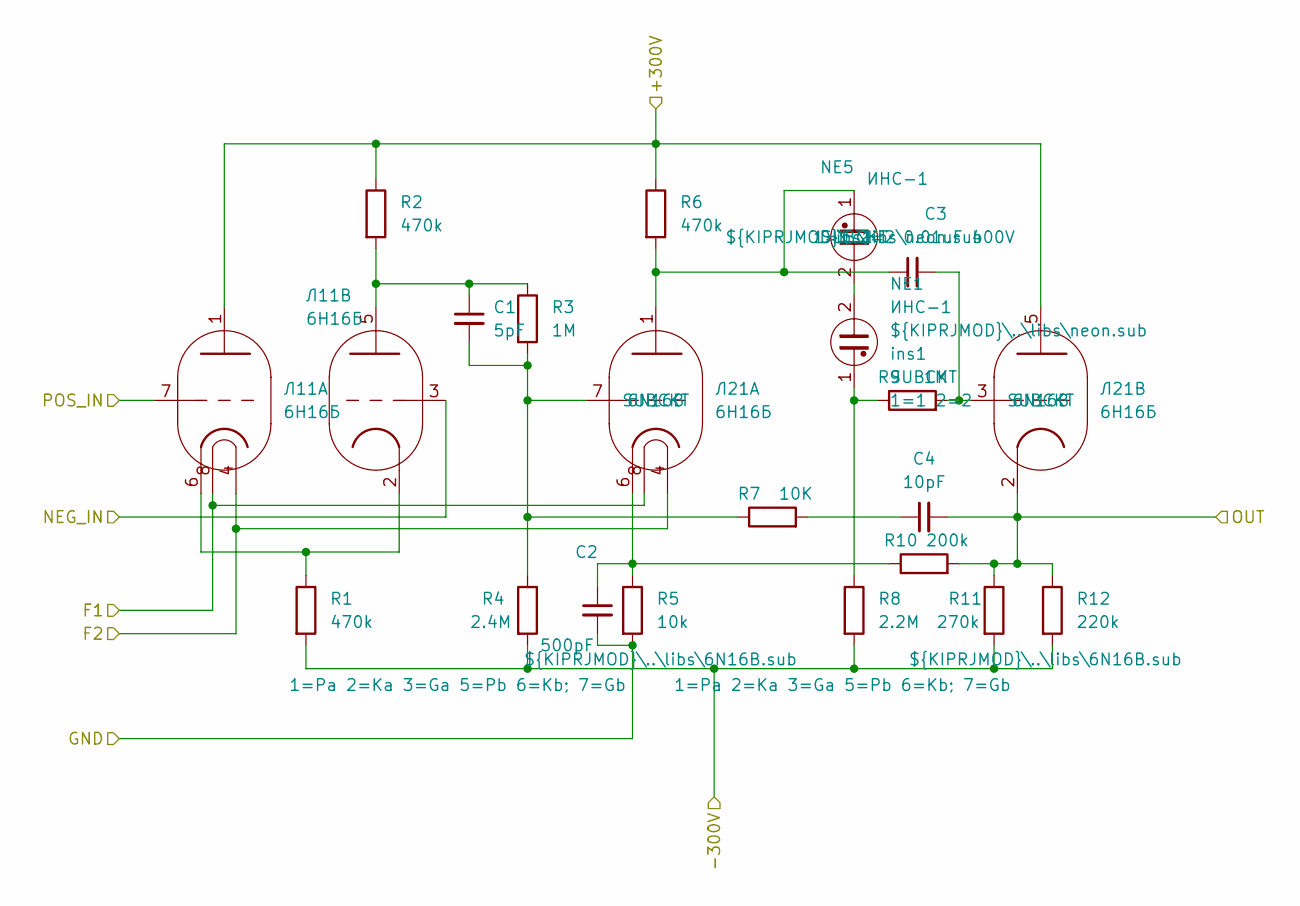
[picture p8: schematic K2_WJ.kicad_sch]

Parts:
C1: 5pF; C_Axial_L12.0mm_D7.5mm_P15.00mm_Horizontal
C2: 500pF; C_Axial_L22.0mm_D9.5mm_P27.50mm_Horizontal
C3: 0.01uF 400V; C_Axial_L12.0mm_D9.5mm_P15.00mm_Horizontal
C4: 10pF; C_Axial_L12.0mm_D7.5mm_P15.00mm_Horizontal
NE1, NE5: ИНС-1
R1, R2, R6: 470k; R_Axial_DIN0617_L17.0mm_D6.0mm_P20.32mm_Horizontal
R3, R9: 1M; R_Axial_DIN0617_L17.0mm_D6.0mm_P20.32mm_Horizontal
R4: 2.4M; R_Axial_DIN0617_L17.0mm_D6.0mm_P20.32mm_Horizontal
R5: 10k; R_Axial_DIN0617_L17.0mm_D6.0mm_P20.32mm_Horizontal
R7: 10K; R_Axial_DIN0617_L17.0mm_D6.0mm_P20.32mm_Horizontal
R8: 2.2M; R_Axial_DIN0617_L17.0mm_D6.0mm_P20.32mm_Horizontal
R10: 200k; R_Axial_DIN0617_L17.0mm_D6.0mm_P20.32mm_Horizontal
R11: 270k; R_Axial_DIN0617_L17.0mm_D6.0mm_P20.32mm_Horizontal
R12: 220k; R_Axial_DIN0617_L17.0mm_D6.0mm_P20.32mm_Horizontal
Л11, Л21: 6Н16Б; 6N16B

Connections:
/K2-WJ/+300V: R2.1, R6.1, Л11.1 (A), Л21.5 (A); also elsewhere on the board
/K2-WJ/-300V: R1.2, R4.2, R8.2, R11.2, R12.2; also elsewhere on the board
/K2-WJ/F1: Л11.8 (F1), Л21.8 (F1); also elsewhere on the board
/K2-WJ/F2: Л11.4 (F1), Л21.4 (F1); also elsewhere on the board
/K2-WJ/GND: C2.2, R5.2; also elsewhere on the board
/K2-WJ/NEG_IN: Л11.3 (G); also elsewhere on the board
/K2-WJ/OUT: C4.2, R10.2, R11.1, R12.1, Л21.2 (K); also elsewhere on the board
/K2-WJ/POS_IN: Л11.7 (G); also elsewhere on the board
unnamed: C4.1, R7.2
unnamed: NE1.1, R8.1, R9.1
unnamed: NE1.2, NE5.2
unnamed: R1.1, Л11.2 (K), Л11.6 (K)
unnamed: C1.1, R2.2, R3.1, Л11.5 (A)
unnamed: C3.1, NE5.1, R6.2, Л21.1 (A)
unnamed: C1.2, R3.2, R4.1, R7.1, Л21.7 (G)
unnamed: C2.1, R5.1, R10.1, Л21.6 (K)
unnamed: C3.2, R9.2, Л21.3 (G)

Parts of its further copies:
C5, C9, C13: 5pF; C_Axial_L12.0mm_D7.5mm_P15.00mm_Horizontal
C6, C10, C14: 500pF; C_Axial_L22.0mm_D9.5mm_P27.50mm_Horizontal
C7, C11, C15: 0.01uF 400V; C_Axial_L12.0mm_D9.5mm_P15.00mm_Horizontal
C8, C12, C16: 10pF; C_Axial_L12.0mm_D7.5mm_P15.00mm_Horizontal
NE2, NE3, NE4, NE6, NE7, NE8: ИНС-1
R13, R14, R18, R25, R26, R30, R37, R38, R42: 470k; R_Axial_DIN0617_L17.0mm_D6.0mm_P20.32mm_Horizontal
R15, R21, R27, R33, R39, R45: 1M; R_Axial_DIN0617_L17.0mm_D6.0mm_P20.32mm_Horizontal
R16, R28, R40: 2.4M; R_Axial_DIN0617_L17.0mm_D6.0mm_P20.32mm_Horizontal
R17, R29, R41: 10k; R_Axial_DIN0617_L17.0mm_D6.0mm_P20.32mm_Horizontal
R19, R31, R43: 10K; R_Axial_DIN0617_L17.0mm_D6.0mm_P20.32mm_Horizontal
R20, R32, R44: 2.2M; R_Axial_DIN0617_L17.0mm_D6.0mm_P20.32mm_Horizontal
R22, R34, R46: 200k; R_Axial_DIN0617_L17.0mm_D6.0mm_P20.32mm_Horizontal
R23, R35, R47: 270k; R_Axial_DIN0617_L17.0mm_D6.0mm_P20.32mm_Horizontal
R24, R36, R48: 220k; R_Axial_DIN0617_L17.0mm_D6.0mm_P20.32mm_Horizontal
Л12, Л13, Л14, Л22, Л23, Л24: 6Н16Б; 6N16B

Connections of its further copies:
/K2-WJ1/NEG_IN: Л12.3 (G); also elsewhere on the board
/K2-WJ1/OUT: C8.2, R22.2, R23.1, R24.1, Л22.2 (K); also elsewhere on the board
/K2-WJ1/POS_IN: Л12.7 (G); also elsewhere on the board
/K2-WJ2/NEG_IN: Л13.3 (G); also elsewhere on the board
/K2-WJ2/OUT: C12.2, R34.2, R35.1, R36.1, Л23.2 (K); also elsewhere on the board
/K2-WJ2/POS_IN: Л13.7 (G); also elsewhere on the board
/K2-WJ3/NEG_IN: Л14.3 (G); also elsewhere on the board
/K2-WJ3/OUT: C16.2, R46.2, R47.1, R48.1, Л24.2 (K); also elsewhere on the board
/K2-WJ3/POS_IN: Л14.7 (G); also elsewhere on the board
/K2-WJ/+300V: R14.1, R18.1, R26.1, R30.1, R38.1, R42.1, Л12.1 (A), Л13.1 (A), Л14.1 (A), Л22.5 (A), Л23.5 (A), Л24.5 (A); also elsewhere on the board
/K2-WJ/-300V: R13.2, R16.2, R20.2, R23.2, R24.2, R25.2, R28.2, R32.2, R35.2, R36.2, R37.2, R40.2, R44.2, R47.2, R48.2; also elsewhere on the board
/K2-WJ/F1: Л12.8 (F1), Л13.8 (F1), Л14.8 (F1), Л22.8 (F1), Л23.8 (F1), Л24.8 (F1); also elsewhere on the board
/K2-WJ/F2: Л12.4 (F1), Л13.4 (F1), Л14.4 (F1), Л22.4 (F1), Л23.4 (F1), Л24.4 (F1); also elsewhere on the board
/K2-WJ/GND: C6.2, C10.2, C14.2, R17.2, R29.2, R41.2; also elsewhere on the board
unnamed: C8.1, R19.2
unnamed: C12.1, R31.2
unnamed: C16.1, R43.2
unnamed: NE2.1, R20.1, R21.1
unnamed: NE2.2, NE6.2
unnamed: NE3.1, R32.1, R33.1
unnamed: NE3.2, NE7.2
unnamed: NE4.1, R44.1, R45.1
unnamed: NE4.2, NE8.2
unnamed: R13.1, Л12.2 (K), Л12.6 (K)
unnamed: C5.1, R14.2, R15.1, Л12.5 (A)
unnamed: R25.1, Л13.2 (K), Л13.6 (K)
unnamed: C9.1, R26.2, R27.1, Л13.5 (A)
unnamed: R37.1, Л14.2 (K), Л14.6 (K)
unnamed: C13.1, R38.2, R39.1, Л14.5 (A)
unnamed: C7.1, NE6.1, R18.2, Л22.1 (A)
unnamed: C5.2, R15.2, R16.1, R19.1, Л22.7 (G)
unnamed: C6.1, R17.1, R22.1, Л22.6 (K)
unnamed: C7.2, R21.2, Л22.3 (G)
unnamed: C11.1, NE7.1, R30.2, Л23.1 (A)
unnamed: C9.2, R27.2, R28.1, R31.1, Л23.7 (G)
unnamed: C10.1, R29.1, R34.1, Л23.6 (K)
unnamed: C11.2, R33.2, Л23.3 (G)
unnamed: C15.1, NE8.1, R42.2, Л24.1 (A)
unnamed: C13.2, R39.2, R40.1, R43.1, Л24.7 (G)
unnamed: C14.1, R41.1, R46.1, Л24.6 (K)
unnamed: C15.2, R45.2, Л24.3 (G)

Board: 2 copper layers, 81 parts (0 on the bottom side), 53 nets, no tracks yet.

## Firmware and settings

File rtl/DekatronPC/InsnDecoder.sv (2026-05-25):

module InsnDecoder(
    input wire Clk,
    input wire Rst_n,
    input wire HardRst_n,

    input wire Halt,
    input wire Step,
    input wire Run,

    input wire keyInsnLoadingStart,
    input wire keyInsnLoadingStop,
`ifdef EMULATOR
    output reg [31:0] IRET,
`endif

    input wire [INSN_WIDTH - 1:0] Insn,
    input wire IpLineReady,
    input wire ApLineReady,

    input wire DataZero,
    input wire ApZero,
    output wire LoopValZero,

    output reg ApRequest,
    output reg ApLineCin,
    output reg ApLineDec,
    output reg ApLineZero,
    output reg IpRequest,
    output reg DataRequest,
    output reg InsnMode,
    output reg InsnLoading,
    
    output reg RstReq,

    output reg tx_vld,
    input wire tx_rdy,
    input wire rx_vld,

    output reg [2:0] state,

    output wire IsHalted,

    //==========================================================================
//         Switch panel section
//==========================================================================
    input wire EchoMode, //When turned on, Symbol from CIN is printed to Cout
    input wire RunOnHardRst,
    input wire RunOnSoftRst,
    input wire SoftRstOnEOT
);

assign IsHalted = (state == HALT);

//If Debug mode {} check AP 
//In brainfuck mode [] check *AP
assign LoopValZero = InsnMode ? DataZero : ApZero;

reg OneStep;
reg Echo;

parameter [1:0]
    NO_RST   = 2'b00,
    HARD_RST = 2'b01,
    SOFT_RST = 2'b10;

reg [1:0] RstType;
wire RunOnRst;
assign RunOnRst = (RstType == HARD_RST) & RunOnHardRst | (RstType == SOFT_RST) & RunOnSoftRst;

parameter [2:0]
    IDLE    =  3'b001,
    FETCH   =  3'b010,
    EXEC    =  3'b011,
    HALT    =  3'b100,
    CIN     =  3'b101,
    COUT    =  3'b110,
    CIO_ACQ =  3'b111;

always @(posedge Clk, negedge Rst_n, negedge HardRst_n) begin
    if (~HardRst_n) begin
        tx_vld <= 1'b0;
        Echo <= 1'b0;
        RstReq <= 1'b0;
        RstType <= HARD_RST;
        InsnLoading <= 1'b0;
        IpRequest <= 1'b0;
        ApLineDec <= 1'b0;
        ApLineCin <= 1'b0;
        ApRequest <= 1'b0;
        DataRequest <= 1'b0;
        ApLineZero <= 1'b0; 
        OneStep <= 1'b0;
        state <= HALT;
        InsnMode <= DEBUG_ISA;
`ifdef EMULATOR        
        IRET <= 0;
`endif
    end
    else if (~Rst_n) begin
        tx_vld <= 1'b0;
        Echo <= 1'b0;
        RstReq <= 1'b0;
        RstType <= SOFT_RST;
        InsnLoading <= 1'b0;
        IpRequest <= 1'b0;
        ApLineDec <= 1'b0;
        ApLineCin <= 1'b0;
        ApRequest <= 1'b0;
        DataRequest <= 1'b0;
        ApLineZero <= 1'b0; 
        OneStep <= 1'b0;
        state <= HALT;
        InsnMode <= BRAINFUCK_ISA;
`ifdef EMULATOR        
        IRET <= 0;
`endif
    end
    else begin
        case (state)
            IDLE: begin
                if (Halt) begin
                    state <= HALT;
                end
                else begin
                    state <= FETCH;
                    IpRequest <= 1'b1;
                end
            end
            FETCH: begin
                IpRequest <= 1'b0;
                tx_vld <= 1'b0;

                if (InsnLoading & (keyInsnLoadingStop | Halt)) begin
                    InsnLoading <= 1'b0;
                    state <= HALT;
                end

                else if (IpLineReady) begin
                    if (InsnLoading) begin
                        casez({InsnMode,Insn})
                            5'h04: begin // INSN_EOT
                                InsnLoading <= 1'b0;
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

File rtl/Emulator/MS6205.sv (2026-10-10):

module MS6205(
    input wire Rst_n,
    input wire Clock_1us,
    input wire Clock_1ms,
    input wire [7:0] tx_data,
    input wire tx_vld_i,
    output reg [7:0] address,
    output wire [7:0] data_n,
    output wire data_valid_n,
    input wire [INSN_WIDTH-1:0] RomData1,
    input wire [DATA_DEKATRON_NUM*DEKATRON_WIDTH-1:0] apData,
    input wire [DATA_DEKATRON_NUM*DEKATRON_WIDTH-1:0] apData1,
    /* verilator lint_off UNUSEDSIGNAL */
    input wire [IP_DEKATRON_NUM*DEKATRON_WIDTH-1:0] ipAddress,
    output reg  [IP_DEKATRON_NUM*DEKATRON_WIDTH-1:0] ipAddress1,
    input wire [AP_DEKATRON_NUM*DEKATRON_WIDTH-1:0] apAddress,
    output reg  [AP_DEKATRON_NUM*DEKATRON_WIDTH-1:0] apAddress1,
    input wire write_addr,
    input wire write_data,
    input wire ready,
    input wire [39:0] keysCurrentState,
    /* verilator lint_on UNUSEDSIGNAL */
    output wire marker,

    input wire tx_switch_view_i, //if 1 enable automatic switch on MS6205

    /* verilator lint_off UNUSEDSIGNAL */
    input wire [3:0] DPC_State
    /* verilator lint_on UNUSEDSIGNAL */
);

reg [2:0] ms6205_currentView;
wire tx_vld;
reg tx_view_req;
parameter COLUMNS = 16;
parameter ROWS = 10;
parameter MAX_POS = COLUMNS * ROWS;

parameter [2:0] 
    MS6205_RESTART = 3'b000,
    MS6205_IRAM = 3'b010,
    MS6205_DRAM = 3'b011,
    MS6205_CIO = 3'b101;

reg [2:0] ms6205_nextView;

reg showMarker;
assign marker = showMarker;

always_comb begin
    if (ms6205_currentView == MS6205_RESTART) begin
        ms6205_nextView = MS6205_IRAM;
    end
    else begin
        if (keysCurrentState[KEYBOARD_IRAM_KEY])
            ms6205_nextView = MS6205_IRAM;
        else if (keysCurrentState[KEYBOARD_DRAM_KEY])
            ms6205_nextView = MS6205_DRAM;
        else if (keysCurrentState[KEYBOARD_CIO_KEY] | tx_view_req)
            ms6205_nextView = MS6205_CIO;
        else if (keysCurrentState[KEYBOARD_HARD_RST])
            ms6205_nextView = MS6205_RESTART;
        else
            ms6205_nextView = ms6205_currentView;
    end
end

always @(negedge Clock_1ms, negedge Rst_n) begin
    if (!Rst_n)
        ms6205_currentView <= MS6205_RESTART;
    else begin
        ms6205_currentView <= ms6205_nextView;
    end
end

//wire PressedKey = |symbol;

reg [7:0] displayRam [0: MAX_POS-1];

reg [7:0] stdioRam [0: MAX_POS-1];
/* verilator lint_off UNDRIVEN */
reg [3:0] insnRam [0: MAX_POS-1];

reg [11:0] dataRam [0: 9];
/* verilator lint_on UNDRIVEN */
//reg [7:0] DRAM [0: MAX_POS-1];
reg [7:0] stdioAddr;

initial begin
    $readmemh("../Emulator/MSDisplayNull.hex", displayRam);
    $readmemh("../Emulator/MSmemZero.hex", stdioRam);
    $readmemh("../Emulator/MSmemZero.hex", insnRam);
end

Impulse impulse_addr(
	.Clk(Clock_1us),
	.Rst_n(Rst_n),
	.En(tx_vld_i),
	.Impulse(tx_vld)
);

always @(negedge Clock_1us, negedge Rst_n) begin
    if (~Rst_n) begin
        stdioAddr <= 8'h0;
        tx_view_req <= 1'b0;  
    end
    else begin
        insnRam[ipAddress1[7:0]+6] <= RomData1;
        dataRam[apAddress1[3:0]] <= (apAddress == apAddress1)? apData : apData1;
        if (tx_vld) begin
            stdioRam[stdioAddr] <= tx_data;
            stdioAddr <= stdioAddr + 1;
            if (tx_switch_view_i) begin
                tx_view_req <= 1'b1;
            end
        end
        if (ms6205_currentView == MS6205_CIO) begin
            tx_view_req <= 1'b0;
        end
    end
end

reg [7:0] stdioData;
reg [7:0] stdioNextData;
reg stdioDataValid_n;

wire [7:0] data;

reg [7:0] ms6205Pos;
wire [7:0] ms6205NextPos;
assign ms6205NextPos = (ms6205Pos == MAX_POS - 1) ? 8'h0 : ms6205Pos + 8'h1;

assign data = stdioData;
assign data_n = ~data;
assign data_valid_n = stdioDataValid_n;

wire [DATA_DEKATRON_NUM*DEKATRON_WIDTH-1:0] currentDataRam0 = dataRam[ms6205Pos[7:4]*2];
wire [DATA_DEKATRON_NUM*DEKATRON_WIDTH-1:0] currentDataRam1 = dataRam[ms6205Pos[7:4]*2+1];

always_ff @(negedge Clock_1ms, negedge Rst_n) begin
    if (~Rst_n) begin
        ms6205Pos <= 8'h00;
        stdioData <= 8'h00;
        address <= 8'h00;
        showMarker <= 1'b0;
        stdioDataValid_n <= 1'b1;
    end
    else begin
        ipAddress1[IP_DEKATRON_NUM*DEKATRON_WIDTH-1:2*DEKATRON_WIDTH] <= ipAddress[IP_DEKATRON_NUM*DEKATRON_WIDTH-1:2*DEKATRON_WIDTH];
        apAddress1[AP_DEKATRON_NUM*DEKATRON_WIDTH-1:1*DEKATRON_WIDTH] <= apAddress[AP_DEKATRON_NUM*DEKATRON_WIDTH-1:1*DEKATRON_WIDTH];
        ipAddress1[2*DEKATRON_WIDTH-1:0] <= ms6205Pos;
        apAddress1[1*DEKATRON_WIDTH-1:0] <= ms6205Pos[6:3];
        
        ms6205Pos <= ms6205NextPos;
        displayRam[ms6205Pos] <= stdioNextData;
        if (displayRam[ms6205Pos] != stdioNextData) begin
            address <= ms6205Pos;
            stdioData <= stdioNextData;
            showMarker <= 1'b0;
            stdioDataValid_n <= 1'b0;
        end
        else begin
            address <= ipAddress[2*DEKATRON_WIDTH-1:0] + 8'd6;
            showMarker <= ms6205_currentView == MS6205_IRAM;
            stdioDataValid_n <= 1'b1;
        end
    end
end
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

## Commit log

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2021-06-25 Fix few timing issues
    [MS6205.sv]
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2023-04-18 Fix Verilator warnings for Emulator
    [MS6205.sv]
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2024-05-23 Fix issue with Step signal: Not IpCounter does oonly +1 for any diration of Step
    [InsnDecoder.sv]
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2024-06-01 FIX issue as OneStep Doesn't work for NOP
    [InsnDecoder.sv]
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2024-06-06 Fix issue with ms6205 address position
    [MS6205.sv]
2024-06-08 Data RAM mode on MS6205 work correctly now
    [MS6205.sv]
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2024-06-10 Revert Quartus changes (Need to automate all this stuff
    [MS6205.sv]
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2024-09-29 Fix MS6205 issue introduced in 4fda25013ece0d172978843355c233c63eeebf5f
    [MS6205.sv]
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2024-10-02 Fix DRAM view issue
    [MS6205.sv]
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2024-11-11 Consul 260.01 support (#21)
    * Start implementing consul connection
    * consul.sv: connect all flow
    * [Emulator.cpp] Add ioRegs interfase
    * [sch] add emulator io digit boards
    * [Emulator.cpp] Consul print Out start working
    * Consul use timings for it's mangets
    * Update sim timings and set proper duration for letter solenoid
    * IO_Regs: Enable signal now is properly generated is a neg edge Strobe
    * Add triangles
    * Sch: opamp
    * Verilog: Fix issue with reaging io regs
    * Consul: works much better
    * Folder stricture renaming
    * wrapup
    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
    [2NAND_6J2B.kicad_sch, 2OR.kicad_sch, INV_6Ж2Б.kicad_sch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]
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2026-02-18 fir: Emulator as Rst_n was not updated after wire to logic rename (#23)
    * fix: disable memory cleanup for EMULATOR and SYNTH
    * fix: lint issues. DekatronPC works under Verilator
    * fix: logic valuew only do initial
2026-05-25 Добавление режима загрузки программ (#26)
    * hard reset impl
    * ap counter zero fix
    Исправлено обнуление счетчика адреса данных
    * fix data zeroing
    Исправлено обнуление счетчика данных. Та же проблема, что со счетчиком адреса: после выставления Request входные данные изменяются до получения Ready
    * bootloader fix
    Добавлен переход в Brainfuck ISA в конце бутлодера
    * add insn valid ready
    Добавлены сигналы для InsnIn в IpLine, добавлено состо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
2026-07-11 Add Sim and Synth CI
    * fix: ad build script for quartus
    * fix: uart lint and test ok
    * fix: try to enable CI
    * fix: CI recursive and exit code
    * fix: update dockerfile - use only repo packets
2026-07-11 Feature/uvm test infrastructure (#27)
    * Add UVM test infrastructure with cocotb + pyuvm (200+ tests, 28 modules)
    - Fix add.sv RTL bug (c0 typo → co)
    - 40+ Makefile targets for icarus and Verilator
    - Covers all 8 phases: logic primitives, dekatron, memory, DPC core, emulator, conversions
    - Wrapper modules for cocotb VPI name collisions (Impulse, OneShot, etc.)
    - BCD utilities, reset sequences, clock generators in conftest.py
    - README.md with full usage documentation
    * Move tb/ to project root, update paths for rtl/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
2026-10-06 CI synt: count tubes for MachineCtrl, not InsnDecoder
    run_tests.sh -s synthesises IpLine, ApLine and MachineCtrl, but passed
    InsnDecoder.json to dpc_stat.py, which no longer exists, so the job
    failed after a successful synthesis.
    Claude-Session: https://claude.ai/code/session_01HKwovAgJt2p5dG14atnWZN
2026-10-06 tb: fix bcd_to_bin and dek_counter targets, show failure logs
    - test_bcd_to_bin pointed at BcdToBin.v; the file is BcdToBin.sv.
    - test_dek_counter built against the old dekatron stack (Dekatron.sv,
    DekatronWriteAmp, BcdToBin.v). Now builds DekatronCounter from
    DekatronTubeV2, DekatronModule, DekatronPhaseGen, DekatronPulseSender,
    BcdToBinEn, BinToBcd. The test also drives the physical soft_rst and
    hard_rst lines to 0 instead of leaving them floating.
    - make regression kept test output in /dev/null. A failed target now
    prints the last 30 lines of its log and a GitHub ::error annotation
    with the error lines.
    Claude-Session: h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
2026-10-06 tb: port pulse_sender, ram, ip_memory tests to the current RTL
    The three tests still drove the pre-v0.6 ports (PulseF/Pulses,
    Address/CS/WE, Request/Ready) that no longer exist.
    - test_dekatron_pulse: DekatronPulseSender with its own phase
    generator. No pulses at idle; StepF gives GuideA then GuideB, StepR
    the reverse; no overlap; a quiet last third; release stops pulses.
    - test_ram: Ram (D_NUM 5, banks 10^4). ready independent of valid,
    zero init, write/read across all banks, write-through, rd_data
    register holds the last cell, BCD tetrad > 9 gives err and no write.
    - test_ip_memory: program write/read, bootloader ROM at 99900..99999
    (contents parsed from bootloader.sv), is_bootl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
2026-10-06 tb: reset dekatron counter tubes with soft_rst before each test
    rst_n resets the logic only and never moves a discharge (TRS 12.3), so
    every DekatronCounter test started from the value the previous test
    left. start_clocks_and_reset now holds the physical soft_rst line for
    3 x RESET_MIN_HS hs_clk cycles and checks the counter reads 0.
    test_dcounter_in_latching is skipped: DekatronCounter does not latch
    its operands, the master holds them until ready (module header).
    The regression annotation now lists every AssertionError and the
    cocotb summary line instead of the last 12 error lines.
    Claude-Session: https://claude.ai/code/session_01H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
2026-10-06 DekatronCounter: operands are not latched (REQ-CNT-V2-004)
    Owner decision: the input register was removed to save tubes. dec,
    set and set_zero are needed only until the handshake; in feeds the
    dekatron write circuit for the whole write window and must stay until
    ready returns. The only master with set is ApLine's data counter, whose
    in (rx_q or the memory register, selected by op) is stable because
    MachineCtrl holds ap_op until ap_ready.
    - TRS: REQ-CNT-V2-004 rewritten (was "latched on accept").
    - DekatronCounter.sv: header and ST_SET comments, no logic change.
    - tb: remove the skipped test_dcounter_in_latching.
    Claude-Session: https: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
2026-10-06 tb: fix tests that passed without checking, cocotb 2 setup notes
    UART RX/loopback and OneShot tests now actually assert their results;
    regression summary grouping fixed in tb/Makefile. tb/README.md drops
    cocotb-coverage (it pins cocotb<2). Report doc/uvm_tb_check.md lists the
    setup, the fixed tests and coverage gaps (REQ-VER-*).
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2026-10-06 ApLine, IpLine: FSM rewrite with Moore strobes (REQ-APV2-007, REQ-IPV2-007)
    Per doc/tube_count_reduction.md §4: OP/WAIT pairs merged, valid strobes
    decoded from state and gated by all-slaves-ready, mem_rd_valid unused.
    ApLine: 9 states -> 6, 874 -> 719 tubes (§10).
    IpLine: 12 states -> 11, dir_q replaces ip_dec/scan_dec_q, loop_init_q and
    clr_is_loop_q removed, insn_q (not live insn_in) written on load,
    halt_pending_q cleared by reset; 902 -> 722 tubes, equiv_opt proven (§11).
    The old IpLine latched the opcode on the stale rd_valid in the read-accept
    cycle and returned the previous fetch's opcode with a Ram-style memory.
    ApLine_tb and IpLine_tb extended (Icarus, pass). IpLine_tb uses a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
2026-10-07 MachineCtrl: FSM rewrite with Moore strobes, COUT from the data counter (REQ-CTLV2-010, OPEN-017)
    MachineCtrl (doc/tube_count_reduction.md §12):
    - 15 states -> 10; strobes (ip_valid, ap_valid, tx_vld, rx_rdy,
    *_rst_req, bell) decoded from state, ip_op/ap_op/ap_dec decoded from
    {insn_mode, insn}; 25 -> 9 flops, 512 -> 284.5 tubes, one clock less
    per instruction.
    - Loop overflow halts on its rising edge from any state (REQ-CTLV2-005):
    the old S_FETCH_W branch overrode the halt, and CLRL re-armed the
    error flag before IpLine dropped the overflow.
    - New MachineCtrl_tb (all 32 opcodes, TEST, CIN/echo, loading, resets,
    overflow, step mode), added to run_tests.sh -t.
    COUT (§13, owner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
2026-10-07 Relay logic for panel switches; decode once, no insn_q (REQ-MOD-011, REQ-APV2-008, REQ-IPV2-008)
    Relays (REQ-MOD-011):
    - RELAY_2CO cell in vtube_cells.lib: 0 tubes, no function, so ABC never
    uses it; behavioral model in vtube_cells.v and rtl/Logic/Relay.sv.
    - RelayMux #(W, S) and RelayEn #(W), keep_hierarchy, two contacts per
    relay. Coils are driven only by panel switches.
    - MachineCtrl: BellOnHALT/CIN/Error via RelayEn, RunOnSoft/HardRst select
    via RelayMux (5 relays). EchoMode and SoftRstOnEOT stay on tubes: a relay
    saves nothing there (8 variants x 7 ABC seeds).
    - dpc_stat.py reports relays per block; cell table counts instances.
    - Synthesis: 1595.5 tubes + 5 relays; doc/tube_coun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
2026-10-07 FPGA bitstream build from the command line and in CI (REQ-RTL-004)
    rtl/run/build_fpga.sh generates a Quartus project in rtl/quartus_build/
    from quartus/Emulator.qsf (device, pins) and the simulator file lists
    (DPC.files, Emul.files), since the qsf's own file list is stale. Stages:
    elab, syn, compile, program; --rbf, JTAG programming, dry run. Works with
    native Quartus or the Windows install from WSL.
    CI: .github/workflows/fpga.yml runs elaboration on pull requests and the
    full compile on push to master or manually, in the community image
    chriz2600/quartus-lite:23.1.1-1 pinned by digest (Altera blocks scripted
    installer downloads). continue-on-error until the image is proven.
    Docs: doc/fpga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
2026-10-07 Prefetch the next opcode while ApLine works (P3, REQ-PERF-003)
    MachineCtrl issues the next fetch together with every ApLine op except
    TEST and CIN, latches the current opcode in op_q (ApLine gets ap_op), and
    goes from S_WAIT/S_COUT straight to S_DECODE. IpLine skips the halt step
    on ip_ahead. helloworld 5540 -> 4184 cycles; MachineCtrl +70 tubes.
    Testbenches, cycle profiler, TRS, AGENTS.md and SCHEMES updated;
    report in doc/prefetch_p3.md. Also adds the helloworld cycle profile and
    the stand PSU schematic review reports.
2026-10-08 Delay-based dekatron model without hsClk, pi.bfk on RTL and netlist (REQ-DEK-010)
    DekatronTubeDelay is the DekatronTubeV2 ring model with no hsClk port:
    moves, writes and resets are inertial #N delays in ns (HS_NS = 100 per
    *_HS unit). The discharge position is part of each move request so two
    moves in the same direction don't merge; zero-width guide glitches in
    the netlist are filtered. DekatronModule selects it with
    `define DEKATRON_DELAY_MODEL; it is not in DPC.files (Icarus only).
    run_tests.sh -d: all Icarus tests plus pi.bfk with the delay model.
    synth_sim.sh -d: the same on netlists (synt_dpc.tcl -D), the tube stays
    a black box without hsClk; new test Pi (pi.bfk on the DekatronPC
    netl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
2026-10-08 Tube cell delays on the netlist via SDF, setup/hold checks (REQ-VER-025, OPEN-014)
    - vtube_cells.v: zero-delay specify block on every cell (ignored without
    -gspecify, existing flows unchanged)
    - rtl/vtube/vtube_timing.json: per-cell, per-arc delays (150 ns), trigger
    setup/hold 150/150 ns
    - rtl/run/vtube_sdf.py: one SDF per netlist module + $sdf_annotate root
    (Icarus can't resolve escaped names like \dek[0].dModule in SDF paths)
    - rtl/vtube/vtube_timing_check.v: behavioural setup/hold checker (Icarus
    ignores $setuphold)
    - synth_sim.sh -t / -c NS, CLK_NS define in Dekatron/Counter/DekatronPC_tb
    - Finding: DekatronCounter never counts at any period, because phase windows
    close before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
2026-10-08 Test stand power supply: KiCad project and schematic review (REQ-STAND-002, REQ-PWR-*) (#34)
    Add sch/stand: root sheet with +/- LM317/LM337 rails and three instances
    of psu.kicad_sch (TL494 push-pull HV converters, 200/120/80 V; per-version
    R1/R7/R8/R9 and transformer turns in the sheet notes), PCB, project
    footprint libraries and the interactive BOM. Includes the review fixes:
    opto feedback polarity, Q1 current limit on the TL431 cathode, 18 V zener
    for the TL431/LED, BC337/BC327 gate buffers, shared RCD clamp to +Vbus.
    stand_v2.* and untitled.kicad_sch are side files outside the hierarchy.
    Backups, lock files, .kicad_prl and fab outputs are not tracked.
    Review report: doc/stand_psu_schema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
    [psu.kicad_sch, stand.kicad_pcb, stand.kicad_sch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]
2026-10-08 Binary FSM encoding in DekatronCounter, IpLine, ApLine: 1669.5 -> 1450.5 tubes (REQ-MOD-009)
    Yosys recoded the extracted state machines one-hot, which costs 16 extra
    7-tube triggers. (* fsm_encoding = "binary" *) on the state registers
    saves about 219 tubes (mean of 3 &deepsyn seeds); the old "encoding
    doesn't matter" test ran after synth and was a no-op. equiv_opt proven;
    run_tests.sh -t/-d and synth_sim.sh/-d pass.
    doc/tube_count_reduction.md §17: second reduction pass, further ideas
    (diode codecs per REQ-AUTH-002, latched carry flags) and owner questions.
2026-10-08 Pulse sender per counter with J2 guide gate, busy flag, MachineCtrl codes: 1437 -> 1362 tubes (REQ-MOD-009)
    T5 (REQ-PULSE-007): one DekatronPulseSender per DekatronCounter drives
    the guide buses; each DekatronModule gates them with a new GUIDE_EN_J2
    cell (one J2 tube) on its carry enable En. Module ports GuideA/GuideB/En
    replace StepF/StepR/Phase*_i; the carry is one enable chain.
    T4: counters without write, top limit or reset to 9 (Loop, AP) use one
    busy_q trigger instead of the FSM.
    T6: MachineCtrl state codes found by search (324.6 -> 317.7 over 5 seeds);
    testbenches and cycle_profile.py follow.
    REQ-AUTH-002: germanium diodes only in rectifiers and ferrite memory
    (owner; diode codecs T2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
2026-10-23 Netlist with tube delays works; guide phases touch; random power-on position (TRS v0.11)
    - Harwell 1951 review (doc/harwell_1951_review.md). Guide pulses must touch or
    overlap, never gap (REQ-PULSE-008): Phase2 is started by the fall of Phase1
    (Impulse FALL=1), no gates in DekatronPhaseGen; tube models accept overlap
    while the discharge is on a guide. One-guide key per decade rejected by owner.
    - Random dekatron position at power-up under DEKATRON_RANDOM_INIT; Counter_tb
    checks hard/soft reset on a data and an IP-like counter (REQ-DEK-017).
    - synth_sim.sh -t fixed (REQ-PULSE-009): phase start delay PHASE_DELAY_HS
    (-o, default 22 under -t), write window started from the write state,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
2026-10-24 6N16B reference sheet as a Markdown page with digitized curves and model check
    - doc/6n16b_datasheet.md: description, electrical data, capacitances,
    ratings, pinout with the KiCad symbol mapping, dimensions; Ia = f(Ua),
    Ia = f(Ug), S/mu/Ri = f(Ia) and pulse-mode curves redrawn; comparison
    with sch/libs/6N16B.sub (within 10 %).
    - doc/data/6n16b_datasheet.json: curves digitized from the 300 dpi scan,
    checked by overlay; accuracy and method recorded in the file and page.
    - tools/spice/datasheet_6n16b_plots.py: draws the figures and the model
    comparison from the JSON.
    - NOR2_N16 page: replaced a by-eye datasheet value with the digitized one;
    cell design method: reference sheet page a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
2026-10-24 Reference-sheet digitizing instructions and tool for the tube tester project
    - doc/digitizing_reference_sheets.md: instructions written for a small
    local model: hard rules (no invented values, no extrapolation, overlay
    before trust), setup, tables, per-plot workflow with a worked example,
    cross-checks with expected tolerances, JSON output format, stop
    conditions, known traps.
    - tools/digitize/digitize.py: render (pymupdf), crop, grid (with filled
    gaps and run-length histogram), scan, order, band, fit, overlay, plot;
    linear and log axes. Tested on 6N16B: reproduces the earlier Ia = f(Ug)
    and S/mu/Ri digitization.
    - doc/6n16b_datasheet.md: the sheet's Ia(Ua) and Ia(Ug) families d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
2026-10-29 LATCH_J2N16/DFF_J2N16 in liberty, A2OOI_J2 = AOI22, 6Kh7B in sch/tubes; TRS v0.20
    - liberty: LATCH -> LATCH_J2N16, DFF -> DFF_J2N16 (falling edge,
    clocked_on "C'"), grid attributes and SPICE delays; models in
    vtube_cells.v/.sp, timing in vtube_timing.json (REQ-MOD-008, REQ-MOD-004)
    - vtube_sdf.py and vtube_setuphold handle negedge triggers
    - synt_dpc.tcl: opt_merge after dfflibmap, one clock inverter per clock
    net instead of a BUF_N16 per trigger
    - A2OOI_J2 function corrected to AOI22 ((A*B)+(C*D))' (owner);
    run_tests.sh -s: 1376 tubes + 5 relays, equiv_opt proven
    - next cells: the AOIs; DFFSR_n async reset through a 6Kh7B diode
    analysed (doc/tube_count_reduction.md 18, DFF_J2N16 p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
2026-10-29 AOI21 A1OOI_N16J2 and AOI22 A2OOI_J2 designed in SPICE; liberty fixed (REQ-MOD-003/004)
    - tools/spice/aoi_sweep.py, aoi_static.py: transient sweep over fanout
    and model spread, static points of every input state
    - A1OOI_N16J2: 6Zh2B (A g1, B g3) + one 6N16B triode (C), Ra 15k,
    1.5 tubes (owner: the whole 6N16B in the liberty was a mistake)
    - A2OOI_J2: two 6Zh2B on one plate, Ra 15k
    - worst arc ~420 ns at fanout 10, grids >= -42 V, Ik <= 12.7 mA over
    MU2 +-20 %; hazards stay under the 92 V threshold
    - liberty: J2 -> J2B, grid attributes, SPICE delays at fanout 6;
    run_tests.sh -s: 1355 tubes + 5 relays
    - cell pages; KiCad sheets and figures still to do (TRS v0.20)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
2026-10-29 DFFRN_J2N16X7 / DFFSN_J2N16X7: async clear / preset through a 6Kh7B (REQ-MOD-004/005/008)
    - DFF_J2N16 + one 6Kh7B: a diode from the reset line into FQN (clear) or
    FQ (preset) of both latches; Cc 2.7 pF across each feedback divider
    compensates the diode capacitance (without it 1 MHz fails)
    - reset line: idle -20 V (owner), GND = asserted; RN/SN active low, so
    rst_n drives them with no inverter
    - tools/spice/dffr_sweep.py: normal / async / recovery; RN -> Q 54-100 ns,
    SN -> Q 273-611 ns, recovery >= 100 ns before C falls
    - RSLATCH sheet brings FQ/FQN out; KiCad sheets and benches agree with
    plain SPICE; 6Kh7B symbol and the two-diode model 6Kh7B2
    - liberty replaces DFFSR/DFFSR_n; vtu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
2026-10-29 OR4: cathode followers against the 6Kh7B diode OR, compared in SPICE (REQ-MOD-003/004)
    tools/spice/or4_compare.py, doc/or4_variants.md: followers on 2 x 6N16B are
    2-3x faster on the rising edge and half a tube cheaper; the diode OR works
    only on the driver plates with Rd ~470k and fails behind the dividers.
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2026-10-30 STA of the tube netlist: timing liberty, Python STA, guide phases too short for the gates (OPEN-014, REQ-PULSE-009)
    vtube_liberty.py builds the NLDM liberty vtube_cells_timing.lib from
    vtube_cells.lib and vtube_timing.json (new fanout ratios 2/6/10 grids);
    vtube_sta.py analyses the flat netlist with models of the phase generators
    and the dekatron (cathode readings valid at the next edge, step command vs
    phase gating, pulse width through the gates); vtube_sta.sh runs it all.
    fanout_load of the 2.7/6.8 pF inputs set by the C1 rule (vtube_c1 / 3.9),
    checked by the generator; the netlist is unchanged.
    Netlist timing simulation: DekatronPC_tb held rst_n 1.95 us, shorter than
    the settling of the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
2026-11-01 DekatronCounter: every operation in one 100 kHz cycle, no FSM and no write-window relay; 1364 tubes (REQ-CNT-V2-009, REQ-CLK-005, REQ-DEK-016)
    - The counter has no ST_* FSM, busy_q or writeTimer relay. ready is
    ~(soft_rst | hard_rst), and step and write lines come straight from
    accept. Only the pre-operation flags nines_q/zeroes_q (and zero_q/at_top_q
    with TOP_LIMIT_MODE) remain.
    - The tube models read the cathodes even under a write. They are valid at
    the next Clk edge, so a step right after a write carries correctly
    (Counter_tb back-to-back test). WR_SYNC_HS is removed.
    - hsClk stays 10 x Clk. The build parameter is the Clk period
    DEKATRON_CLK_NS (100 kHz default), and testbenc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
2026-11-01 No hsClk in synthesis and delay simulations; tube durations in ns, 100 kHz meets again (REQ-DEK-009, REQ-DEK-010, REQ-CLK-002, OPEN-014)
    - hsClk now exists only for the clocked dekatron model (the FPGA emulator
    and RTL runs without delays). Under DEKATRON_DELAY_MODEL no module has an
    hsClk/hs_clk port, and OneShot/Impulse have no Clk port.
    - Tube-machine durations are ns macros DEKATRON_*_NS in rtl/parameters.sv
    (guide 200, fall 300, write/reset 5000, phase delay/widths, edge 100).
    They are passed explicitly to the black boxes, so the netlist and STA
    read them from there. The *_HS parameters belong to the clocked model.
    - synt_dpc.tcl always synthesizes the delay model. synth_sim.s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
2026-11-01 ABC: amap -F 4 -A 20 instead of map -a, 1129 tubes; SDF skips paths of inputs tied to one net (REQ-MOD-009)
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2026-11-01 No rst_n on the glue triggers: 1105.3 -> 1072.3 tubes (TC-O5; REQ-REF-011, REQ-MOD-009)
    rst_n is not a reset of its own (owner): rst_n = hard_rst | soft_rst.
    - IpLine, ApLine, MachineCtrl: the rst_n branch of the main FSM is gone,
    all 32 glue triggers are DFF reset by soft_rst/hard_rst synchronously
    or written before they are read (dir_q, key_moved_q, op_q).
    - RstTimeRelay holds hard_rst while rst_n is low, then the power-up hold.
    - tx_vld is gated by the reset line: a random S_COUT at power-on would
    otherwise send the terminal one character.
    - rst_n stays only as the model reset of the RC delay elements and the
    emulator's iret counter.
    - IpLine/ApLine/MachineCtrl testbenches pulse a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
2026-11-01 Dekatron board holds only the read circuit; TC-O3 accepted (TRS v0.38; REQ-PR-020, REQ-MOD-009)
    The dekatron takes two places, 14 are left: 6Kh7B read diodes and BinToBcd
    with inverted outputs (TC-O3 accepted by the owner, not yet in the RTL).
    Guide keys and write tubes move to their own boards. SPICE with 30 pF cables
    on the write node and the key plate: Usm window 12...13 V.
2026-11-02 TC-O3: value buses active-low; tube count with the dekatron module and by tube type (TRS v0.39, v0.40; REQ-MOD-009)
    TC-O3 (owner, 2026-11-02): BinToBcdN (four NOR, no output inverters) in
    DekatronModule; counter ports out_n/in_n; ApLine pads memory cells with ones
    and tests zero as all-ones; Ram/IpMemory invert on their ports
    (ADDR_ACTIVE_LOW/DATA_ACTIVE_LOW) and keep the direct code inside;
    Emulator.sv inverts at the DekatronPC boundary; Appendix B and AGENTS
    updated; testbenches compare in the direct code. 1072.3 -> 1052.2 tubes.
    Tube count: run_tests.sh -s and synth_seeds.sh take rtl/run/.venv (else
    /var/venv); counting cells WRCH_N16 (write channel), RDD_X7 (read diode) and
    GLIFT_N16 (g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
2026-11-02 Stand PSU review: 200v winding note for all transformers, sectioned-primary leakage asymmetry (doc/stand_psu_schematic_review.md §10.5-10.6)
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2026-11-02 Remove passport scans and add missing fcore images
    The scans will be replaced by a proper scan of the owner's copy. The
    figures and board photos were dropped by the *.png ignore rule in the
    first commit, so allow them in .gitignore.
    Claude-Session: https://claude.ai/code/session_01AHQRAAPukXPcA2Nw6HSNhX
2026-11-02 ISA16: one 4-bit instruction set without insn_mode, one-decade bootloader at 99990
    Opcodes 0x0-0xA stay Brainfuck; B = LD (SOT, EOT in the load stream),
    C = CLRA, D = STORE (sets MemLock without a load: cell := data counter),
    E/F = { } (test AP). Gone: ISA0/ISA1, HRST/SRST, CLRL/CLRI, BELL, Debug
    CLRD, CLRML/LOAD, separate SOT/EOT. IpLine loses clr and its CLR states,
    the bracket detector is x11x (both kinds counted together). Hard reset
    sets IP to 99990; the bootloader 0<{0<} ... LD fits one decade.
    Verilator lint clean (DekatronPC, Emulator). Tests follow (doc/isa16.md).
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
